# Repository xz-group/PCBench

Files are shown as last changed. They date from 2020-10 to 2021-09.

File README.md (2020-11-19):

# PCBench

PCBench is a free open-source benckmark for board-level hardware attacks and Trojans.

## What's News

Version 1.0

This is the initial release of the benchmars for board-level hardware security.

## Motivation
Most modern electronic systems are hosted by printed circuit boards(PCBs), making them a ubiquitous system component that can take many different shapes and forms. In order to achieve a high level of economy of scale, the global supply chain of electronic systems has evolved into disparate segments for the design, fabrication, assembly, and testing of PCB boards and their various associated components. <br />
As a consequence, the modern PCB supply chain exposes many vulnerabilities along its different stages, allowing adversaries to introduce malicious alterations to facilitate board-level attacks. As an emerging hardware threat, the attack and defense techniques at the board level have not yet been systemically explored and thus require a thorough and comprehensive investigation. <br />
In the absence of a standard board-level attack benchmark, current re-search on perspective countermeasures is likely to be evaluated on proprietary variants of ad-hoc attacks, preventing credible and verifiable comparison among different techniques. Upon this request, we have created the PCBench, which is a set of board-level attack benchmarks for open-source release.

## Benchmarking Methodology

We generated the benchmarks based on the methodology proposed in our **ASP-DAC 2021 paper: *[PCBench: Benchmarking of Board-Level Hardware Attacks and Trojans](http://jin.ece.ufl.edu/papers/ASPDAC2021_PCB.PDF)***.
In this paper, we systematically defined and categorized a broad range of board-level attacks. 
For the first time, the attack vectors and construction rules for board-level attacks were developed.
A practical and reliable board-level attack benchmark generation scheme was also developed, which can be used to produce references for evaluating countermeasures.

## Released Benchmarks
To facilitate the development of board-level attack benchmarks, representative circuit boards are chosen as the victim designs. 
Open-source hardware projects are mainly selected due to their modern design styles, the availability of PCB designs as well as detailed documents, firmware, and/or application software. 
As a result, researchers can easily reconstruct the board-level security evaluation benchmarks. 

**The following table lists the released benchmarks:**

 Design Name | Description | Dimension (mm^2) | No. of Components | No. of Layers
 ----------- | ----------- | :---------: | :-----------------: | :-------------:
 [arduino-due](arduino-due) | Microcontroller devlopment board based on ATsam3x8e with ARM Cortex-M3 core | 102x53 | 141 | 2
 [a13-olinuxino](a13-olinuxino-g2) | Single-board Linux computer based on Allwinner-A13 with Cortex-A8 core | 120x120|370|4

*This is not the full list of benchmarks as we continue developing the new benchmarks.* 

The fabricated Arduino-due board with and without Trojans are shown below.

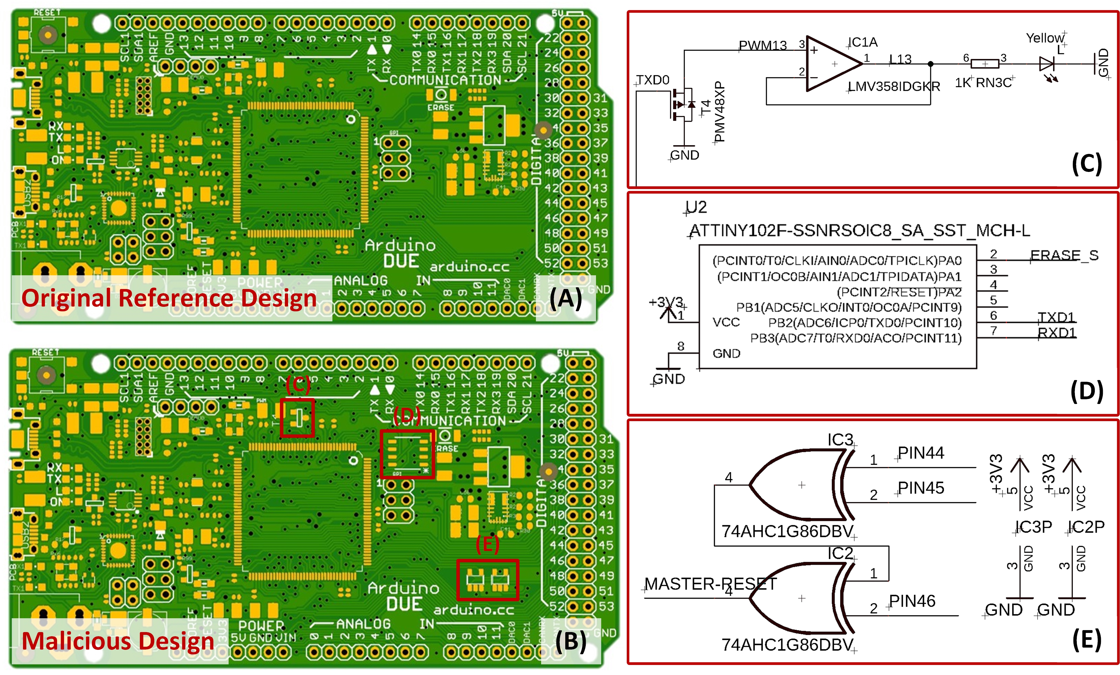
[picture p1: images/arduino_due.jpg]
Arduino Due Board


## Contributiors
The PCBench is mainly developed by *Huifeng Zhu* and *[Dr.Silvia Zhang](https://xzgroup.wustl.edu/people/xuan-silvia-zhang/)* from *Washington University in St.Louis*; *[Dr.Yier Jin](http://jin.ece.ufl.edu/)* from the *University of Florida*; and *[Dr.Xiaolong Guo](https://www.ece.k-state.edu/people/faculty/guo/)* from *Kansas State University*.

We also appreciate the efforts of below contributors: 

## How to Refer to PCBench?
If you are using the benchmarks provided in PCBench to develop either threat mitigation methods or new threat exploitations, please cite our official paper of PCBench. 
You can find the paper in the website of IEEE: [link]() or at [link](http://jin.ece.ufl.edu/papers/ASPDAC2021_PCB.PDF).

A typical BibTeX citation would be, for example:
```
@software{PCBench,
  author = {Huifeng Zhu and Xiaolong Guo and Yier Jin and Xuan Zhang}, % actual author and maintainer
  title = {PCBench: Benchmarking of Board-Level Hardware Attacks and Trojans},
  booktitle = {26th Asia and South Pacific Design Automation Conference (ASP-DAC)},
  year = {2021},
  url = {https://github.com/xz-group/PCBench},
  version = {1.0},
  date = {2020-10-15}, % set to the release date
}
```
## Get Feedback
Feel free to contact us if you have questions about PCBench: **Huifeng Zhu (zhuhuifeng@wustl.edu)**.

## License

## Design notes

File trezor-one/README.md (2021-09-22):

# Trezor One Benchmark



https://trezor.io/

## High-level Description of Hardware Attack
The goal of the Trezor One Benchmark is to siphon the recovery seed from a Trezor One device. This information could then be used to retrieve the original cryptocurrency passwords stored by the user. The recovery process is used in the event that the user forgets their PIN number or enters too many incorrect attempts. The user manual outlines this [recovery process](https://wiki.trezor.io/User_manual:Recovery).

During the initial startup sequence of the Trezor One, the user is instructed to write down a unique, device-generated sequence of 24 english words. Each word is displayed one at a time on the Trezor's built-in monochrome display.

This attack describes the necessary steps for capturing packets of display data and decoding them to reveal the full recovery seed.

## Data Capture
The Trezor One Victim board is equipped with a malicious ATtiny microcontroller that is attached, in a slave configuration, to the Trezor's STM32 microcontroller SPI lines. These SPI lines are also connected the the Trezor's display and are used to send bitmap image data. This configuration allows the malicious ATtiny to go undetected while still having access to all data being sent from the Trezor's microcontroller to its display.

Due to how the display operates, the Trezor's microcontroller sends a complete bitmap image to the display each time it needs to be altered, regardless of how many pixels need to change. This is beneficial because it makes it easy to decode recorded SPI packets and rebuild them into complete images. These decoded images represent exactly, pixel for pixel, what was displayed on the Trezor device at the time of packet transmission.

## Implementing the Attack

### Technical Details

#### Display Connecter Pins Table:

| PIN | <------------> | NET |
| --- | --- | --- |
| 12 | <------------> | GND |
| 13 | <------------> | SPI ENABLE |
| 15 | <------------> | DISPLAY DATA/COMMAND |
| 18 | <------------> | SPI CLOCK |
| 19 | <------------> | SPI DATA |

#### Trezor SSD1306 Operation
The display used is a 128x64 OLED SPI display. Internally, the display contains a single-chip driver called the SSD1306 which is widely utilized and documented. The full details of the [SSD1306 documentation](https://cdn-shop.adafruit.com/datasheets/SSD1306.pdf) are crucial to gaining a low-level understanding of this attack. 

A full screen's worth of data is sent to the display each time it is updated. At a simple level, there are 8,192 total pixels and each pixel is driven by a 1 for ON or 0 for OFF. This series of 1024 1's and 0's are sent one byte at a time via SPI to the display. However, they are not ordered left to right and top to bottom as one might expect. The full details of the pixel mapping algorithm is outlined on page 25 of the [SSD1306 documentation](https://cdn-shop.adafruit.com/datasheets/SSD1306.pdf) with regards to the display's GDDRAM. This process needs to be reversed for decoding and is exactly what is embedded in the [src/image_builder.py](image_builder.py) script.

Along with the 8,192 data bits that are sent to the display, there are also command sequences that are sent at the beginning of each transmission that do not represent pixel values. Outlined below is information representing the series of bits sent via SPI to the display by the Trezor. If necessary, specific command bytes can be tracked down in the [Trezor Firmware](https://github.com/trezor/trezor-mcu).

* **Setup Command Bytes (25 total)**
    * Description: The setup command bytes are sent directly after the RESET line of the display is triggered on startup. They aid in resetting the display, setting the contrast, setting the page addressing mode, etc. The exact bytes and corresponding meaning can be found in the [oled.c](https://github.com/trezor/trezor-mcu/blob/8af1f3643651e1cbee6b6196401f9c63e7cfc0f9/oled.c) file in the [Trezor Firmware](https://github.com/trezor/trezor-mcu).
    * Data: {0xAE, 0xD5, 0x80, 0xA8, 0x3F, 0xD3, 0x00, 0x40, 0x8D, 0x14, 0x20, 0x00, 0xA1, 0xC8, 0xDA, 0x12, 0x81, 0xCF, 0xD9, 0xF1, 0xDB, 0x40, 0xA4, 0xA6, 0xAF}
* **Prepended Command Bytes (3 total)**
    * Description: The prepended command bytes are sent directly before new image data is sent. For the Trezor, these bytes are always the same and can be helpful as a delimiter for debugging purposes.
    * Data: {0x00, 0x10, 0x40}
* **Pixel Value Bytes (1024 total)**
* Description: The pixel value bytes represent 1's and 0's for each of the 8,192 pixels. This means that there are 1024 SPI byte packets sent for this part of the transmission. This is the most important part of the transmission for the attack and is the only piece that needs to be recorded to EEPROM since the other pieces are constant and predictable.
* Data: {0x__, 0x__, 0x__, .......}

It is important to note that there is a signal connected to the display (DISPLAY DATA/COMMAND or D/C) that tells the display whether the incoming data is a series of command bytes or data bytes. For the Setup and Prepended Command Bytes, the D/C pin is pulled low so that the data is transferred to the SSD1306 command register. For the Pixel Value Bytes, the D/C is pulled high to be treated as data.

The order in which these command bytes and data bytes are sent is consistent:
1. The Setup Command Bytes are sent only once when the device is powered on.
1. The Preprended Command Bytes are sent before the initial screen data is sent.
1. The Pixel Value Bytes are sent as 0's (1024 bytes of 0x00) to clear the GDDRAM of the SSD1306.
1. The Preprended Command Bytes are sent before the startup screen data is sent.
1. The Pixel Value Bytes are sent to display the startup screen.
1. The previous two steps are repeated for every subsequent image displayed. This means that subsequent transmissions are a total of 1027 bytes (3 Prepend Command Bytes + 1024 Pixel Value Bytes)

Manual tests with an Arduino board and an external 128x64 OLED SPI display can be used to test what unique outputs may look like. Modify [SPI_Manual_Test.ino](/src/SPI_Manual_Test/SPI_Manual_Test.ino) for testing.

### Ideal Attack Sequence
1. Program the malicious ATtiny chip with firmware that enables it to record and store SPI packets to EEPROM.
1. After Trezor device is setup and functional, the malicious ATtiny chip will contain the SPI packets relating to the recovery seed image data. This means that the ATtiny device can now be connected to in some fashion that allows for its EEPROM to be extracted.
1. Enter the extracted EEPROM bytes into a .csv file.
1. Run the image builder Python script that converts the data in the .csv file to a .png image.
1. Repeat the previous step until all images representing each word in the recovery seed are created.
1. Use the recovery seed to gain access to the information on the Trezor device by following the [recovery process](https://wiki.trezor.io/User_manual:Recovery).

### Proof of Concept Attack Sequence
To prove that this ideal attack sequence is possible, various methods and tools were used to extract test data from a from both a real Trezor One and a Trezor victim board.

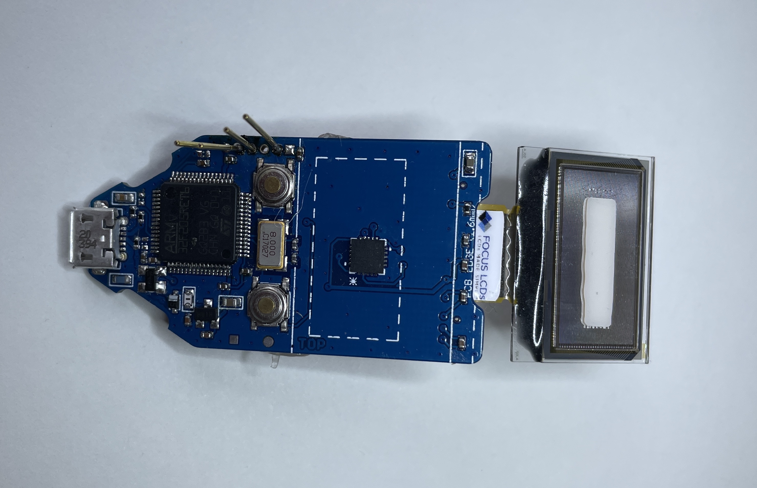
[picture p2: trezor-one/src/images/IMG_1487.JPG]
Trezor victim board


First, a Trezor victim board was populated. Firmware was built and uploaded by following the [Trezor One Dev Kit](https://mcudev.github.io/trezor-dev-kit/) documentation. Once the device is set up, you must navigate to trezor.io/start and follow the instructions. Unfortunately, this process involves updating the firmware which seems to halt any progress past this point. After the forced update, the Trezor displays an "Unknown bootloader detected" warning and does not work. However, for the purposes of the proof of concept, this limitation was ignored because the SPI data packets used to display the startup screen and "Unknown bootloader detected" warning are of the same format as the packets used to display all content (including the recovery seed words).

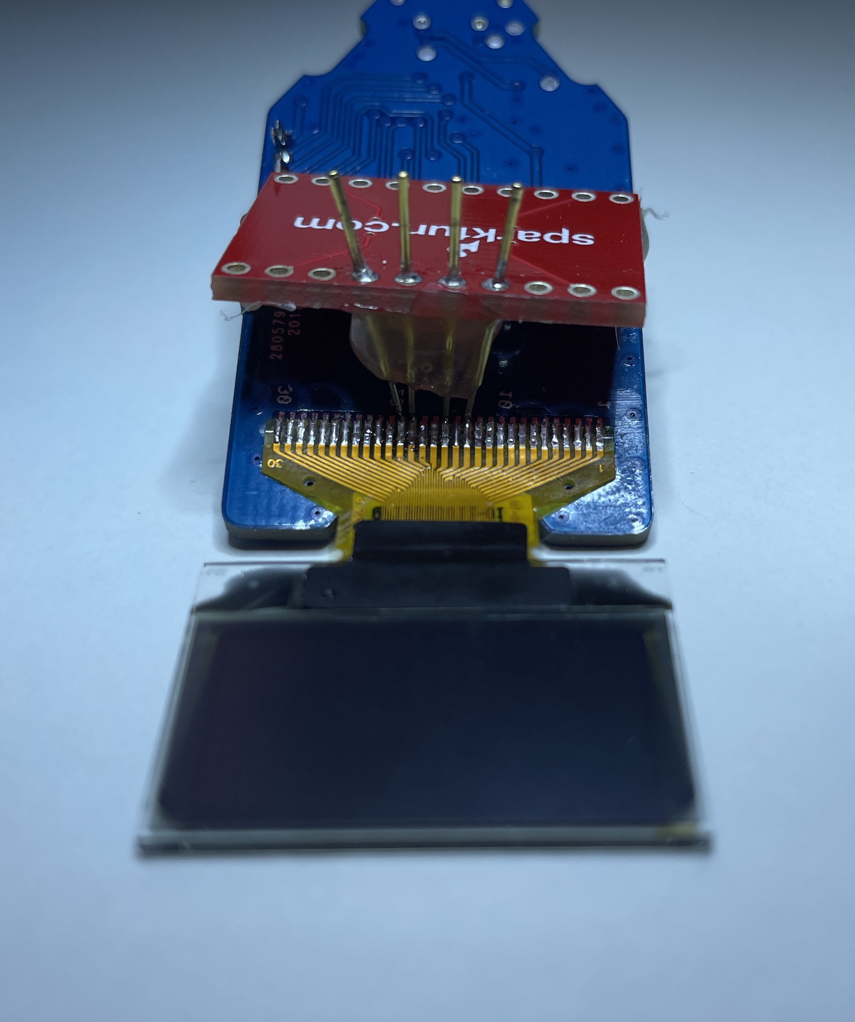
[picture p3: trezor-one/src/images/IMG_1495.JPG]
Improvised connector


Next, a logic analyzer was connected to the necessary pins on the display connector (see Technical Details) using an improvised connector. The HEX values sent over the SPI data line were then exported to the [startup_spi_data.csv](src/startup_spi_data.csv) file. The beginning and ending of the 1024 bytes representing each displayed image were then set manually in the [image_builder.py](src/image_builder.py) file. At this point in testing, the Trezor victim board displayed two images on startup. The first was a lock icon and the second was the "Unknown bootloader detected" warning. Setting and running the python script for both sets of 1024 bytes in the .csv file resulted in the [Lock Screen Image](src/lock_screen.png) and [Info Screen Image](src/info_screen.png) being generated.

To prove that these results were relevant to a real Trezor, the improvised connector was placed on a geniune Trezor One. Using a logic analyzer in the same fashion resulted in the [real_trezor_startup.csv](src/real_trezor_startup.csv) file. After setting the start and end rows of the SPI data relating to the startup screen, the python script produced the [real_trezor_startup.png](src/real_trezor_startup.png) image.

### Further Implementation

Currently, there is one gap between the proof of concept and the ideal attack sequence. In the proof of concept, the SPI data was captured with a logic analyzer and then exported to .csv file. In the ideal attack sequence, the ATtiny captures the data and the user then connects to the ATtiny to extract the recorded data from EEPROM.

Firmware for the ATtiny needs to be written that implements it as an SPI slave. Since the general purpose SPI library does not support the ATtiny85 being used, a more primitive script must be used. Refer to this [stackexchange post](https://electronics.stackexchange.com/questions/60114/spi-h-for-attiny) for ideas.

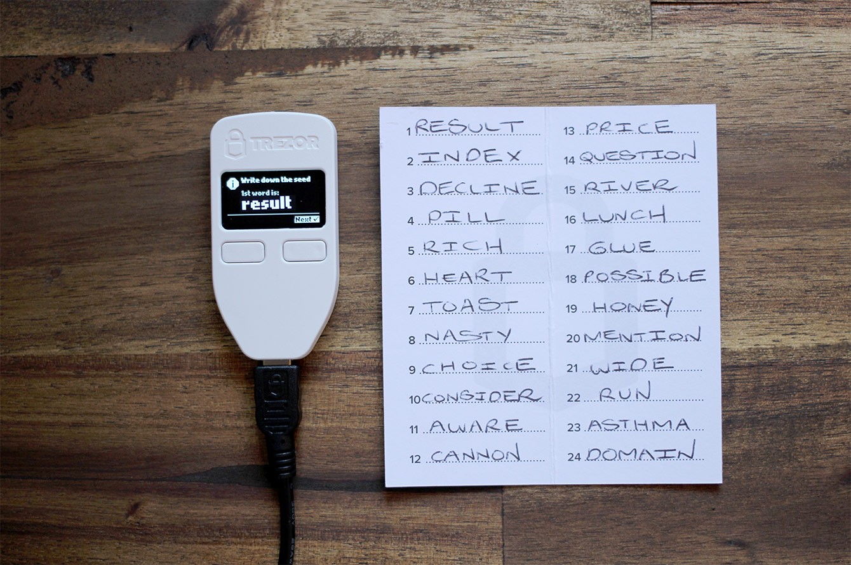
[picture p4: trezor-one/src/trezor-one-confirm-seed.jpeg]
Trezor One Recovery Seed


Once this is implemented, the next immediate problem is EEPROM space. It must be noted that the data has to be held in EEPROM because it needs to be stored in non-volatile memory. The Trezor will be powered off before the data extraction from the ATtiny occurs. It seems that the ATtiny85 has 512 bytes of EEPROM. Unfortunately, this is nowhere near sufficient for this application. Ideally, 24,576 bytes (24 recovery screens * 1024 bytes per display image) would be available to record the SPI data to. This also assumes that the ATtiny is equipped with code that knows exactly which SPI packets will represent the 24 recovery screens that need to be recorded. On the surface, this may seem simple to account for. In the startup sequence, the recovery screens should always be the Nth screen to be displayed. The ATtiny would then be able to count packets until it gets to the Nth screen. However, this may not work because of variants such as the unnecessary button presses from the user that result in extra screens being displayed. Therefore, a better method will probably have to be utilized. One method would be to figure out if the recovery screens have a special, unique design. For example, as shown in this [photo](trezor-one-confirm-seed.jpeg), the ATtiny could be programmed with a bitmap that has the correct bytes representing "Write down the seed" and "Nth word is:." These could then be compared with the most recently recorded packet to decide whether or not the packet represent a recovery screen. Furthermore, this method can also help reduce necessary EEPROM space. It can be noted than in the [photo](trezor-one-confirm-seed.jpeg), takes up at most 1/3 of the vertical space and slightly more than 1/2 of the horizontal space. While this can't solve the 512 byte limitation, it can greatly reduce the EEPROM size needed to well under 24,576 bytes. Since the final EEPROM size needed will be greater than the currently available 512 bytes in the ATtiny85, there are two options. The first is to choose another microcontroller with a larger EEPROM. The second option would be to add an external EEPROM chip which is cheap and offers a tremendous amount of storage. However, one caveat of the latter method is that the external EEPROM would need to be connected over SPI. This may potentially pose a problem because the microcontroller would have to act as both and SPI slave for the STM32 and a master for the external EEPROM.

### ATtiny85-20M1 Breakout Board

In order to upload code to this ATtiny85 package for testing, a custom breakout board is needed. This is because the footprint is unique and compatible breakout boards are difficult to find online. This breakout board was designed in KiCad and an image of the board along with the pinout information is listed below. All design files can be found [here](attiny85_breakout_board).

| Header Pin | ATtiny85 Pin | Connection |
| --- | --- | --- |
| 1 | 1 | RESET/PB5 |
| 2 | 2 | XTAL1/PB3 |
| 5 | 5 | XTAL2/PB4 |
| 8 | 8 | GND |
| 11 | 11 | AREF/PB0 |
| 12 | 12 | PB1 |
| 14 | 14 | PB2 |
| 15 | 15 | VCC |

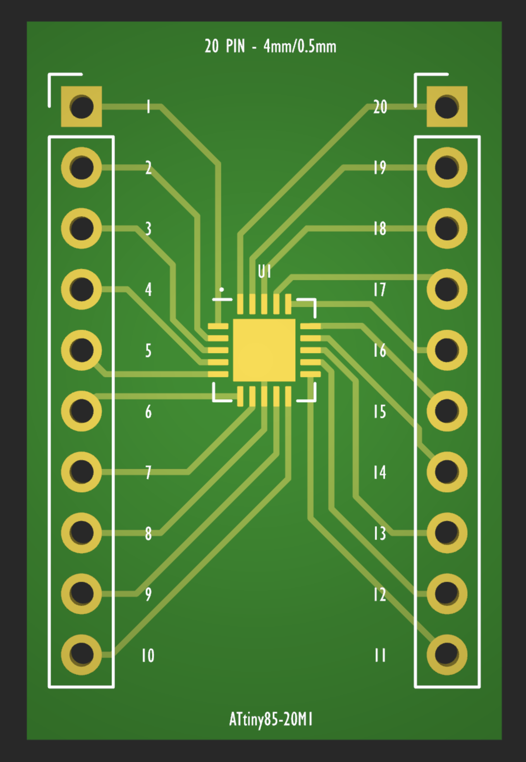
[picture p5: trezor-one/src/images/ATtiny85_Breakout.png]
ATtiny85 Breakout Board


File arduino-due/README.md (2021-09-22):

# Getting Started with the Arduino-Due Benchmark

## Introduction
This tutorial includes step-by-step information about how to get started with the `arduino-due` benchmark, including both setting up the boards and demonstrating the attacks.

For this benchmark, there are two versions of boards (as shown below): the  `malicious` version and the `reference` version. The `reference` version uses the exact same schematic design of the original [Arduino Due board](https://store.arduino.cc/usa/due). 
Note that we slightly modify the layout of the original design to ease inserting the Trojans and implementing the attacks. The `malicious` version is the same as the `reference` version (both schematic and layout) except the inserted malicious circuit, which means once the malicious circuits and related routings are removed, the `malicious` version board will be completely the same as the `reference` version board.

In this benchmark we implement three malicious attacks (as shown above):
1. A malicious MOSFET is connected to the UART transmitter to leak information through LED (subfigure c);
2. The maliciously programmed ATtiny microcontroller monitors the UART and generates Flash erase signal when triggered (subfigure d); 
3. Two XOR logic chips output a signal to reset the board once triggered (subfigure e).

## Initialize the boards
### Install the firmware of the Arduino Due programming port
#### Use the Atmel programmer to install the firmware:
1. Follow the instruction of https://www.arduino.cc/en/Hacking/DFUProgramming8U2

2. For the firmware files, the `hex` files can be found in
https://github.com/arduino/ArduinoCore-sam/tree/master/firmwares/atmega16u2

3. After programming the flash, you will see the programming port of the Arduino Due board in your Device manager.


### Test the functionality of the boards
1. Install the Arduino SAM Boards (32-bits ARM Cortex M3) from the tools->board->boards manager.
#### Program through the Programming Port
1. Connect the Programming Port.
2. Upload and Run the `Blink` example.

#### Program through the Native USB Port

1. Connect the native USB port.
2. Program directly using the native USB port, upload and Run the `Blink` example.

## Demonstrate the attacks
### 1. Malicious MOSFET
**Goal:**<br> A malicious MOSFET is connected to the UART transmit pin to leak information through LED.

**Configuration:**<br> In this demonstration, the datapath is as follows:
User input into the reference board's Serial Monitor is sent directly to the Serial1 port on the victim board. This Serial1 port (on the victim board) is directly connected to the LED that is used to leak the data. Once the victim board receives data from the reference board, it mirrors the characters back over the same Serial1 port to be leaked through the LED. The data is also mirrored to the SerialUSB port which will display on the victim board's Serial Monitor if connected.

**Demonstration:**<br>

1. Connect Pins

| Reference Board | <------------> | Victim Board |
| --- | --- | --- |
| Serial1 TX (18) | <------------> | Serial1 RX (19) |
| Serial1 RX (19) | <------------> | Serial1 TX (18) |
| GND | <------------> | GND |

2. Upload Source Code

* Attach the victim board via USB and upload the following [source code](attacks/malicious_MOSFET/victim_board_src/victim_board_src.ino)
* Attach the reference board via USB and upload the following [source code](attacks/malicious_MOSFET/reference_board_src/reference_board_src.ino)

3. Testing

* Connect the reference board via USB
* Open the Serial Monitor (this is accessed by clicking the plus button in the top right corner on the Arduino IDE)
* Click the hardware reset button (located next to the USB port) on the reference board
* Wait 5 seconds for the board to initialize until you see an information printout
* Try entering various characters into the Serial Monitor
* Take note of the LED blinking on the victim board whenever characters are sent via the reference board
* To confirm that characters are being sent, connect the reference board via USB and open another Serial Monitor to track the mirrored characters being sent from the reference board

**Vulnerability:**<br> The flashing of the LED corresponds to the 1's and 0's of the ASCII being transmitted through UART. This data could be sensed and decoded by another system to monitor sensitive UART data packets.

### 2. Malicious ATtiny
**Goal:**<br> A maliciously programmed ATtiny microcontroller monitors the UART and generates a Flash erase signal when triggered.

**Generalized Configuration:**<br> In this demonstration, the datapath is as follows:
User input into the reference board's Serial Monitor is sent directly to the Serial2 port on the victim board. This Serial2 port (on the victim board) is directly monitored by the malicious ATtiny. Once the trigger word is inputted by the user and subsequently read by the ATtiny, the ATtiny triggers a master reset of the victim board's flash memory. Throughout this process, the victim board's LED will continuously blink to show that it is still functional and has not yet been attacked. Once it is attacked, the LED will stop blinking and the board will have to be re-flashed before it can perform another test.

**Technical Configuration:**<br>
* The ATtiny102 constantly monitors the victim board's UART RX pin at 4800 baud
    * This connection configuration is undetectable by the victim board itself or any reference boards
* A reference board is used to connect to the Serial 2 UART Port of the victim board (TX-16 RX-17)
    * The reference board can trigger the ATtiny102 to erase the flash of the victim board by sending the command "ATTACK"
* A 6-character buffer array is maintined on the ATtiny102 to keep track of incoming UART characters
    * Each time a new character is read, it is placed at the end of the array
    * Subsequently, all remaining characters are shifted one index to the left in the array
    * This process discards the oldest (leftmost) character
* Once the buffer array contains the string "ATTACK" the ERASE sequence is triggered:
    * The ATtiny102 pulls the ERASE pin of the victim board LOW for 2 seconds to erase the FLASH
    * At this point, the victim board is in a paralyzed state and the ATtiny102 resumes normal listening operation

**Demonstration:**
1. Connect Pins

| Reference Board | <------------> | Victim Board |
| --- | --- | --- |
| Serial2 TX (16) | <------------> | Serial1 RX (17) |
| Serial1 RX (17) | <------------> | Serial1 TX (16) |
| GND | <------------> | GND |

2. Upload Source Code

* Attach the victim board via USB and upload the following [source code](attacks/malicious_ATtiny/victim_board_src/victim_board_src.ino)
* Attach the reference board via USB and upload the following [source code](attacks/malicious_ATtiny/reference_board_src/reference_board_src.ino)
* If the ATtiny needs to be flashed, use Atmel/Microchip Studio to upload the following [source code](attacks/malicious_ATtiny/ATtiny_src)

3. Testing

* Connect the reference board via USB
* Open the Serial Monitor (this is accessed by clicking the plus button in the top right corner on the Arduino IDE)
* Click the hardware reset button (located next to the USB port) on the reference board
* Wait 5 seconds for the board to initialize until you see an information printout
* Try entering various characters (not the trigger word) into the Serial Monitor
* Take note of the LED blinking on the victim board which signifies that it has not yet been attacked
* Enter the trigger word into the Serial Monitor
* Confirm that the attack was successful be ensuring that the victim board's LED stopped blinking

**Vulnerability:**<br> The ATtiny can erase the Flash of the victim board, rendering it useless, if the trigger command is sent to the victim board over UART.

### 3. Malicious XORs
**Goal:**<br> Two XOR logic chips output a signal to reset the victim board's Flash once triggered.

**Generalized Configuration:**<br> In this demonstration, the datapath is as follows:
User input into the reference board's Serial Monitor is monitored internally by the reference board. Once the trigger word is inputted by the user, a sequence of code executes that triggers a flash reset on the victim board. This is accomplished by setting pins 44, 45, and 46 on the victim board to a specific sequence of logic levels that trigger the flash reset. Throughout this process, the victim board's LED will continuously blink to show that it is still functional and has not yet been attacked. Once it is attacked, the LED will stop blinking and the board will have to be re-flashed before it can perform another test.

**Technical Configuration:**<br>
* The XOR chips have pins 44, 45, 46 from the victim board as inputs. In the default state, these pins are logical level HIGH so as to not trigger the Flash reset.
* The following truth table represents the various logic level inputs to the victim board and what output they trigger

| Pin 44 | Pin 45 | Pin 46 | Flash Reset |
| --- | --- | --- | ---  |
|0|0|0|NO|
|0|0|1|<mark>YES<mark>|
|0|1|0|<mark>YES<mark>|
|0|1|1|NO|
|1|0|0|<mark>YES<mark>|
|1|0|1|NO|
|1|1|0|NO|
|1|1|1|<mark>YES<mark>|

**Demonstration:**
1. Connect Pins

| Reference Board | <------------> | Victim Board |
| --- | --- | --- |
| D10 | <------------> | D44 |
| D11 | <------------> | D45 |
| D12 | <------------> | D46 |
| GND | <------------> | GND |

2. Upload Source Code

* Attach the victim board via USB and upload the following [source code](attacks/malicious_ATtiny/victim_board_src/victim_board_src.ino)
* Attach the reference board via USB and upload the following [source code](attacks/malicious_ATtiny/reference_board_src/reference_board_src.ino)

3. Testing

* Connect the reference board via USB
* Open the Serial Monitor (this is accessed by clicking the plus button in the top right corner on the Arduino IDE)
* Click the hardware reset button (located next to the USB port) on the reference board
* Wait 5 seconds for the board to initialize until you see an information printout
* Try entering various characters (not the trigger word) into the Serial Monitor
* Take note of the LED blinking on the victim board which signifies that it has not yet been attacked
* Enter the trigger word into the Serial Monitor
* Confirm that the attack was successful be ensuring that the victim board's LED stopped blinking

**Vulnerability:**<br> An external board can change the state of these input pins which would trigger a Flash reset of the victim board, rendering is useless.

## Developer Notes
* For an 8MHz internal clock on the ATtiny102, the prescaler sets the clock in the code to 1MHz
    * 1 MHz is not considered fast enough to communicated over UART at 9600 baud becuase data becomes corrupted
    * 4800 is the maximum clean baud rate for this internal clock
* ATtiny102 TX trace should be removed in final design
* Use other, non-programming pin, for the resetting functionality on the ATtiny102 (recommend PB1/Pin 5)
* The programming port on the test boards does not work due to a an error in the original Arduino Due design documentation

## References
1. Pinout of the Arduino Due Board: https://content.arduino.cc/assets/Pinout-Due_latest.pdf

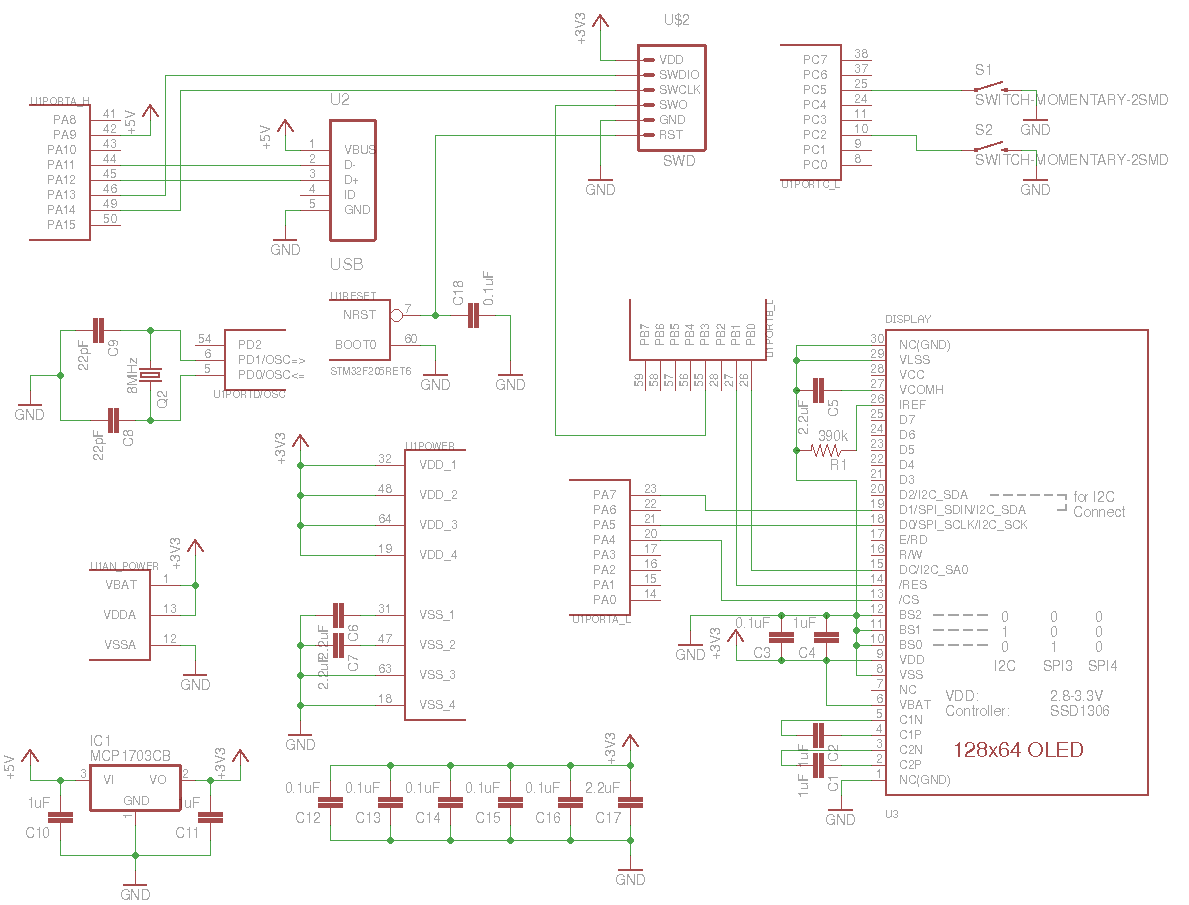
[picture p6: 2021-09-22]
trezor-one/src/electronics/trezor_one/trezor_v1.0.sch.png

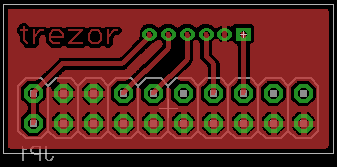
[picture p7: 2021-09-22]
trezor-one/src/electronics/trezor_one/programmer.brd.png

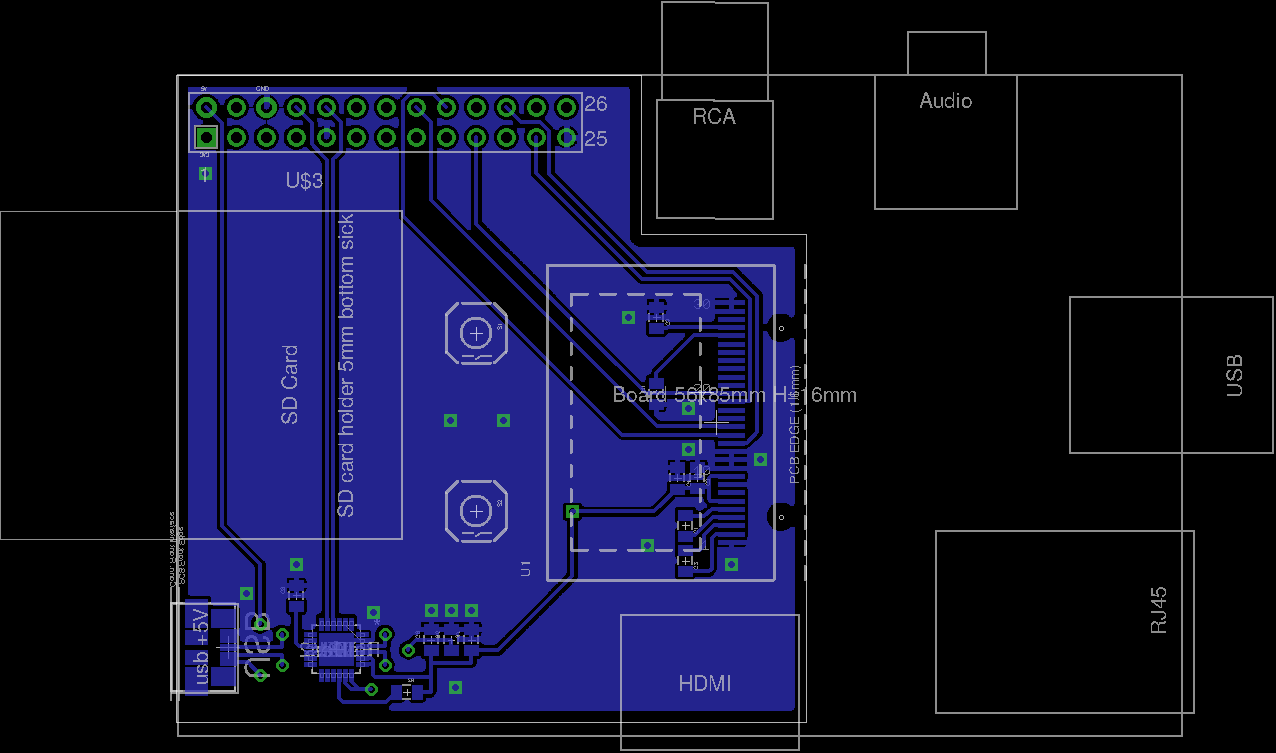
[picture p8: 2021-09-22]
trezor-one/src/electronics/trezor_one/raspi.brd.png

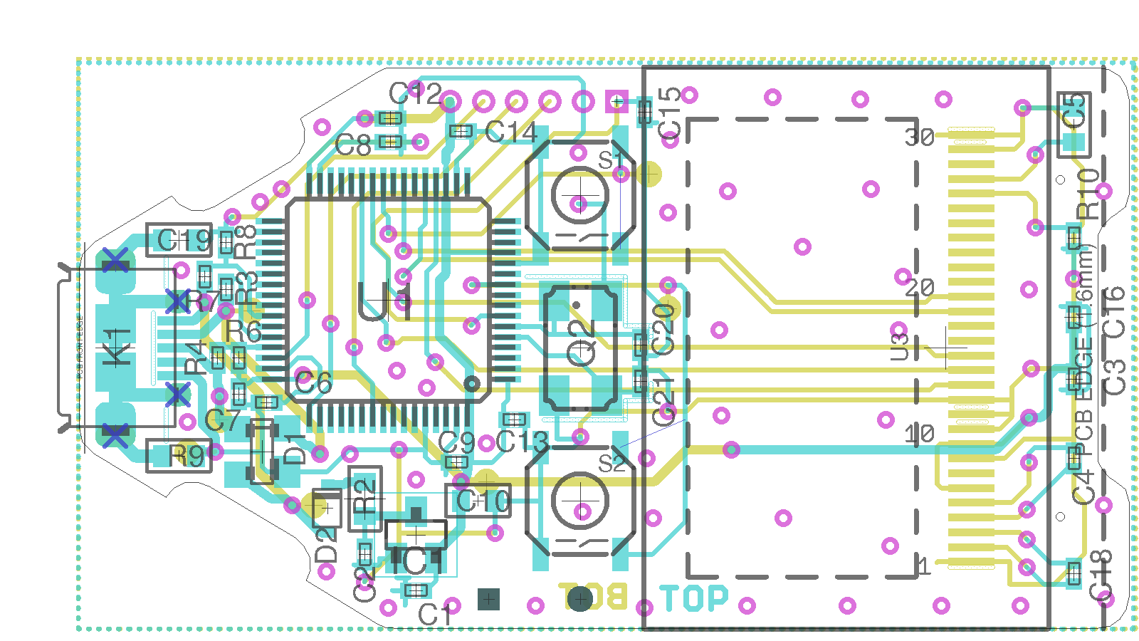
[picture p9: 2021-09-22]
trezor-one/src/electronics/trezor_one/trezor_v1.1.brd.png

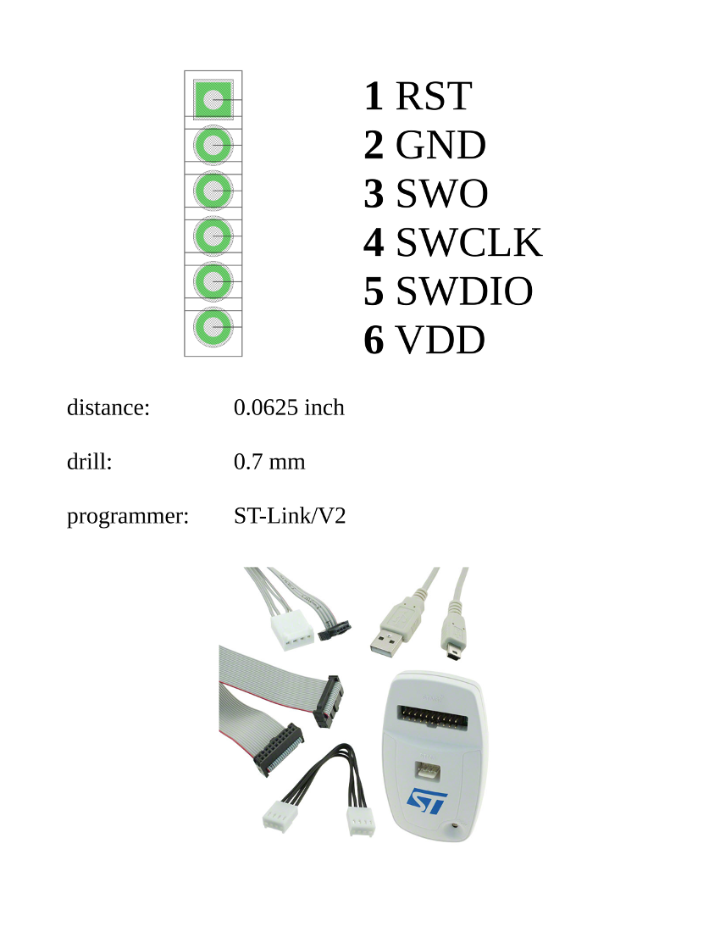
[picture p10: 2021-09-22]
trezor-one/src/electronics/trezor_one/programmer.png

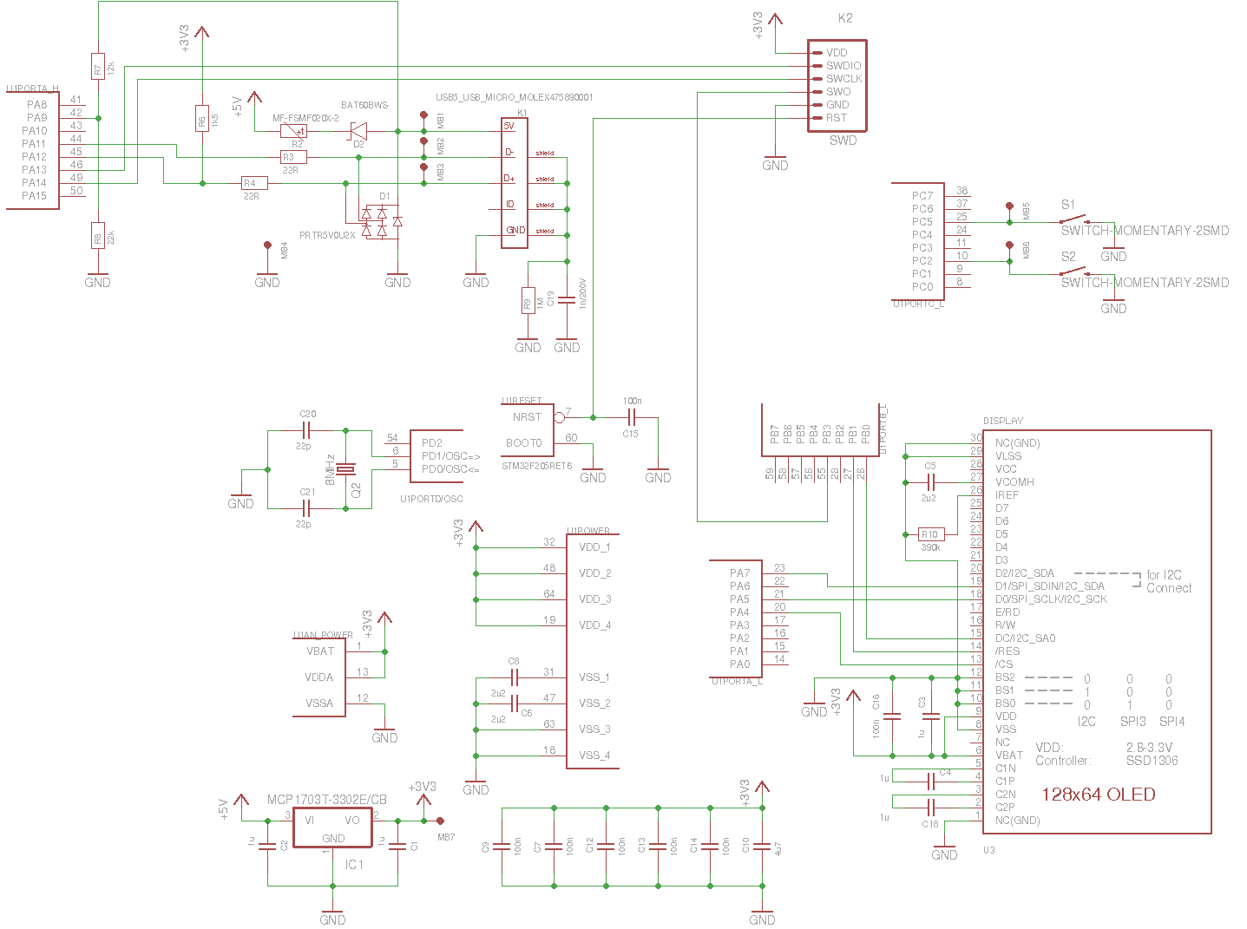
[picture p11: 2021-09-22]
trezor-one/src/electronics/trezor_one/trezor_v1.1.sch.png

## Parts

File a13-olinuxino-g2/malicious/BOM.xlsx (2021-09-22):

Qty | Value | Device | Package | Parts | Description
1 | 0.03R/1% | R-EU_R1206_5MIL_WS | R1206_5MIL_WS | R27 | RESISTOR, European symbol
4 | 1.05k/1% | R-EU_R0603_5MIL_DWS | R0603_5MIL_DWS | R35, R36, R37, R74 | RESISTOR, European symbol
4 | 1.1k/1% | R-EU_R0603_5MIL_DWS | R0603_5MIL_DWS | R19, R85, R100, R101 | RESISTOR, European symbol
3 | 100k/1% | R-EU_R0603_5MIL_DWS | R0603_5MIL_DWS | R69, R76, R84 | RESISTOR, European symbol
57 | 100nF | C-EUC0603_DWS | C0603_DWS | C1, C2, C3, C4, C13, C15, C17, C19, C20, C21, C22, C23, C24, C29, C30, C32, C34, C36, C37, C38, C39, C40, C41, C43, C44, C45, C46, C47, C48, C49, C50, C51, C56, C57, C59, C62, C63, C64, C70, C72, C80, C81, C82, C90, C97, C101, C105, C108, C110, C111, C112, C118, C119, C122, C127, C131, C141 | CAPACITOR, European symbol
1 | 100pF | C-EUC0603_DWS | C0603_DWS | C144 | CAPACITOR, European symbol
4 | 100uF/16V/LOWESR/105C/6.3x11mm_RM2.5 | CPOL-EUE2.5-6.3 | E2,5-6,3 | C91, C99, C107, C117 | POLARIZED CAPACITOR, European symbol
10 | 10k | R-EU_R0603_5MIL_DWS | R0603_5MIL_DWS | R14, R16, R18, R47, R55, R56, R96, R97, R103, R104 | RESISTOR, European symbol
1 | 10k/1% | R-EU_R0603_5MIL_DWS | R0603_5MIL_DWS | R81 | RESISTOR, European symbol
1 | 10nF | C-EUC0603_DWS | C0603_DWS | C123 | CAPACITOR, European symbol
1 | 10pF | C-EUC0603_DWS | C0603_DWS | C130 | CAPACITOR, European symbol
31 | 10uF/6.3V | C-EUC0603_DWS | C0603_DWS | C6, C7, C8, C10, C11, C14, C16, C31, C35, C54, C55, C58, C73, C74, C76, C77, C78, C79, C83, C85, C86, C88, C92, C93, C95, C96, C98, C100, C102, C109, C121 | CAPACITOR, European symbol
1 | 10uH/3.15A/20% | LLQH88PN100M38 | 8X8MM_3131 | L13
1 | 11k/1% | R-EU_R0603_5MIL_DWS | R0603_5MIL_DWS | R82 | RESISTOR, European symbol
2 | 13k/1% | R-EU_R0603_5MIL_DWS | R0603_5MIL_DWS | R68, R83 | RESISTOR, European symbol
3 | 17.8k/1% | R-EU_R0603_5MIL_DWS | R0603_5MIL_DWS | R20, R21, R22 | RESISTOR, European symbol
1 | 1N5819(S4SOD-123) | SCHOTKKY7.62SS-1N5819(S4SOD-123) | SOD-123 | D1
1 | 1N5822/SS34/SMA | D-MLL-41 | MELF-MLL41 | D9 | DIODE
1 | 1N5822/SS34/SMA | SCHOTKKY7.62SS2 | MLL-41 | D7
2 | 1R | R-EU_R0603_5MIL_DWS | R0603_5MIL_DWS | R34, R41 | RESISTOR, European symbol
9 | 1nF | C-EUC0603_DWS | C0603_DWS | C60, C61, C65, C66, C67, C84, C87, C103, C139 | CAPACITOR, European symbol
6 | 1uF | C-EUC0603_DWS | C0603_DWS | C28, C33, C75, C89, C94, C104 | CAPACITOR, European symbol
14 | 2.2k | R-EU_R0603_5MIL_DWS | R0603_5MIL_DWS | R8, R9, R45, R49, R50, R52, R53, R59, R60, R61, R72, R73, R75, R77 | RESISTOR, European symbol
3 | 2.2k/1% | R-EU_R0603_5MIL_DWS | R0603_5MIL_DWS | R31, R32, R33 | RESISTOR, European symbol
6 | 2.2uH/1.5A/DCR<0.1R/CD32 | L-CD32 | CD32 | L2, L3, L4, L10, L14, L15
3 | 200k/1% | R-EU_R0603_5MIL_DWS | R0603_5MIL_DWS | R7, R46, R67 | RESISTOR, European symbol
8 | 22R | R-EU_R0603_5MIL_DWS | R0603_5MIL_DWS | R87, R88, R89, R90, R91, R92, R93, R94 | RESISTOR, European symbol
1 | 22k/1% | R-EU_R0603_5MIL_DWS | R0603_5MIL_DWS | R86 | RESISTOR, European symbol
1 | 22pF | C-EUC0603_DWS | C0603_DWS | C114 | CAPACITOR, European symbol
1 | 22uF | C-EUC0603_DWS | C0603_DWS | C140 | CAPACITOR, European symbol
21 | 22uF/6.3V | C-EUC0603_DWS | C0603_DWS | C5, C9, C12, C18, C25, C42, C52, C68, C69, C71, C113, C115, C116, C128, C129, C132, C133, C135, C136, C137, C138 | CAPACITOR, European symbol
4 | 240R/1% | R-EU_R0603_5MIL_DWS | R0603_5MIL_DWS | R10, R12, R13, R23 | RESISTOR, European symbol
4 | 2k/1% | R-EU_R0603_5MIL_DWS | R0603_5MIL_DWS | R1, R2, R6, R11 | RESISTOR, European symbol
1 | 3.3k/1% | R-EU_R0603_5MIL_DWS | R0603_5MIL_DWS | R65 | RESISTOR, European symbol
2 | 3.3nF | C-EUC0603_DWS | C0603_DWS | C53, C124 | CAPACITOR, European symbol
1 | 32768Hz/6pF | MC-306_32.768KHZ/SMD_8038 | MC-306 | Q3
4 | 33pF | C-EUC0603_DWS | C0603_DWS | C26, C27, C120, C125 | CAPACITOR, European symbol
4 | 4.32k/1% | R-EU_R0603_5MIL_DWS | R0603_5MIL_DWS | R28, R29, R30, R102 | RESISTOR, European symbol
2 | 4.99k/1% | R-EU_R0603_5MIL_DWS | R0603_5MIL_DWS | R62, R71 | RESISTOR, European symbol
1 | 470uF/25V/LOWESR/105C | CPOL-EUE5-10.5 | E5-10,5 | C126 | POLARIZED CAPACITOR, European symbol
7 | 47k | R-EU_R0603_5MIL_DWS | R0603_5MIL_DWS | R4, R5, R17, R51, R54, R64, R70 | RESISTOR, European symbol
1 | 47pF | C-EUC0603_DWS | C0603_DWS | C134 | CAPACITOR, European symbol
3 | 51R | R-EU_R0603_5MIL_DWS | R0603_5MIL_DWS | R43, R98, R99 | RESISTOR, European symbol
3 | 549R/1% | R-EU_R0603_5MIL_DWS | R0603_5MIL_DWS | R38, R39, R40 | RESISTOR, European symbol
2 | 6.8k/1% | R-EU_R0603_5MIL_DWS | R0603_5MIL_DWS | R48, R79 | RESISTOR, European symbol
1 | 680R/1% | R-EU_R0603_5MIL_DWS | R0603_5MIL_DWS | R66 | RESISTOR, European symbol
1 | 74LVC1G06DCK | 74LVC1G06DCK | SC70-5 | IC1 | Single Inverter Buffer/Driver With Open-Drain Output
2 | 8.2k/1% | R-EU_R0603_5MIL_DWS | R0603_5MIL_DWS | R78, R80 | RESISTOR, European symbol
3 | 8.66k/1% | R-EU_R0603_5MIL_DWS | R0603_5MIL_DWS | R24, R25, R26 | RESISTOR, European symbol
1 | A13 | Allwinner A13 | TQFP176 | U3
1 | ATTINY102F-SSNRSOIC8_SA_SST_MCH-L | ATTINY102F-SSNRSOIC8_SA_SST_MCH-L | SOIC8_SA_SST_MCH-L | U17
1 | AXP209(QFN48) | AXP209 | QFN48 | U9
2 | BAT54C | DIODE_AC-CA_ | SOT23C | D10, D11 | DUAL DIODE
5 | BAT54S | DIODE_AC-AC_ | SOT23C(BAT54S) | D2, D3, D4, D5, D6 | DUAL DIODE
2 | BH10S | ML10 | ML10-MALE | GPIO-1, UEXT | HARTING
4 | BSS138 | N-MOS+DIODBSS138(SOT23-3) | SOT23 | FET1, FET2, FET4, FET5
1 | CL470nH/0805/1.76R/250mA | L-USL0805_5MIL_DWS | L0805_5MIL_DWS | L1 | INDUCTOR, American symbol
1 | DW02R | CON2DW02R | DW02R | LIPO_BAT
1 | FB0805/600R/200mA(201209-601) | L-USL0805_5MIL_DWS | L0805_5MIL_DWS | L12 | INDUCTOR, American symbol
6 | FB0805/600R/2A | L-USL0805_5MIL_DWS | L0805_5MIL_DWS | L5, L6, L7, L8, L9, L11 | INDUCTOR, American symbol
1 | GL850G-HHGXX | GL850G | SSOP28 | U11
1 | H27UBG8T2BTR | H27UBG8T2A | TSOP48 | U4
2 | HC49/S1 | HC49/S1 | HC49/SMD2_THIN | Q1, Q2 | CRYSTAL
1 | IRLML6402 | P-MOS+DIODIRLML6402 | SOT23 | FET3
2 | K4B2G0846Q-BCKO | H5TQ2G83CFR-H9C | FBGA78 | U1, U2
1 | LED/GREEN/0603 | LED0603DWS | LED-0603 | LED1
1 | LED/RED/0603 | LED0603DWS | LED-0603 | PWR_LED
1 | LED/YELLOW/0603 | LED0603DWS | LED-0603 | CHGLED
1 | MICRO_SD/MMC_CP_NEWTFC-WPAPR-08 | MICRO_SD/MMC_CP_NEWTFC-WPAPR-08 | TFC-WPAPR-08 | SD
2 | 2.54pinhead 2x20 | 2.54pinhead 2x20 | 2.54pinhead 2x20 | GPIO-2, LCD_CON | HARTING
1 | MP1482DS | MP1482 | SOIC8 | U13
1 | PCF8563T/5 | PCF8563 | SO-8 | U14 | Real-time clock/calendar
2 | PJ-W47S-05D2-LF_V2 | AUDIO_JACK_5PINPJ-W47S-05D2-LF_V2 | PJ-W47S-05D2-LF_5PIN_V2 | HEADPHONES, MIC
11 | RA0805_(4X0402)_22R | R_MATRIX_4E_25X625 | R_MATRIX_4_0402_25X625 | RM1, RM2, RM3, RM4, RM5, RM6, RM7, RM8, RM9, RM10, RM16
1 | RA1206_(4X0603)_4B8_100K | R_MATRIX_4E | R_MATRIX_4 | RM12
1 | SMBJ16A | SMBJ16A | DO214AA | D8
3 | SN74ALVC244 | 74ALVC244 | PW | U5, U6, U7
2 | SY6280 | SY6280 | SOT23-5 | U8, U12
1 | SY7208(SOT23-6) | SY7208 | SOT23-6 | U16
2 | SY8008C(AA)C | SY8008 | SOT23-5 | U10, U15
7 | T1107A(6x3.8x2.5mm) | SW-TAKT6 | SW-TAKT_6X3.5_SMD | PWR_BUT, RESET, SW1, SW2, SW3, SW4, SW5
1 | USB-OTG | MINI_USB9 | USB_MINI_9PIN | USB_OTG
3 | USB_A_VERTICAL | USB_SHIELDUSB_A_VERTICAL | USB_A_VERTICAL_PTH | USB_HOST1, USB_HOST2, USB_HOST3
1 | VGA15 | DB1522 | DB15-F_22MM | VGA_DB15-F
1 | YDJ-1136 | PWR-JAKPWR_JACK_UNI_MILLING | PWR_JACK_UNI_MILLING | PWR

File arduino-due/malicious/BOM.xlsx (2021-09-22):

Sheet: Sheet1
Qty | Value | Device | Package | Parts | Description | BUILT_BY | CASE | MANUFACTURER_PART_NUMBER | PART_NUMBER | TYPE | VALUE
1 |  | 0644_4X1VP.2,54H11,8 | PH1X4-THT | DEBUG | 4x1 V P.2,54 H11,8
3 | 0R | 0039_JUMP_0402 | R0402 | JR1, R1, R8 | 0R 0402 |  | 0402 |  | JUMP_0402 | Resistenze | 0R
1 | 100K_1% | 2022_CR0603FW104L | R0603-ROUND | R28 | 0603 Resistor 100K 1% |  |  |  | CR0603FW104L |  | 100K_1%
1 | 100k | 0026_100K_0603 | R0603-ROUND | R30 | 100K 0603 |  | 0603 |  | 100K_0603 | Resistenze | 100k
2 | 100k | 0134_CR0402FX1003L | R0402 | R4, R16 | 100K 0402 |  | 0402 |  | CR0402FX1003 L | Resistenze | 100k
3 | 100k | 0168_CAY16-104J4LF | CAY16 | RN1, RN2, RN4 | 100K 064 R |  | SMD 3,2x1,6 |  | CAY16-104J4LF | Resistenze | 100k
2 | 100nF | 0015_100NF_0603 | C0603-ROUND | C41, C50 | 100nF 0603 50V |  | 0603 |  | cl10b104kbnc | Condensatori | 100nF
22 | 100nF | 0132_100NF_0402 | C0402 | C4, C5, C6, C7, C8, C9, C10, C12, C13, C14, C15, C16, C17, C18, C19, C28, C30, C31, C32, C34, C36, C37 | 100nF 0402 |  | 0402 |  | 100nF_0402 | Condensatori | 100nF
4 | 10K | 0136_CR0402FX1002_L | R0402 | R2, R13, R18, R99 | 10K 0402 |  | 0402 |  | CR0402FX1002_L | Resistenze | 10K
2 | 10n | 0165_10NF_0402 | C0402 | C20, C26 | 10nF 0402
1 | 12mHz-12pF-K7 | 0396_12MHZ-12PF-K7 | CRYSTAL-3.2-2.5 | Y1 | 12Mhz - K7 12pF - SMD |  |  |  |  |  | 12mHz-12pF-K7
1 | 157SW | 0173_IT-1185AP1C-160G-G_T&R | SMD_157SW | ERASE | Pushbutton 4x3 SMD H2,5mm |  |  |  | IT-1185AP1C-160G-G_T&R | Switches | 157SW
1 | 16Mhz-KX-7 | 0395_16.000MHZ__12PF | CRYSTAL-3.2-2.5 | Y4 | 16Mhz - K7 12pF - SMD |  |  |  | 16.000Mhz__12pF | Cristalli | 16Mhz-KX-7
1 | 18x2F-H8.5 | 1756_12TW323 | 2X18 | XIO | Female Gray Connector strip for Arduino 3V3 bases 18x2 F V h 8,5 p2,54 |  |  |  | 12TW323 | Connettori | 18x2F-H8.5
1 | 19K1_0,1% | 2339_ | R0603-ROUND | R29 | 19K1 0,1% 0603 |  | 0603 |  |  | Resistenze | 19K1_0,1%
1 | 1K | 0005_064R_1K_/_CAY16-102J4LF | CAY16 | RN3 | 1K 064R |  | SMD_3,2x1,6 |  | 064R_1K_/_CAY16-102J4LF | Resistenze | 1K
5 | 1K | 0140_1K_0402 | R0402 | R3, R14, R15, R21, R23 | 1K 0402 |  | 0402 |  | 1K_0402 | Resistenze | 1K
1 | 1K5 | 0163_1K5_ARRAY | CAY16 | RN5 | 1K5 064 R
1 | 1M | 0139_1M_0402 | R0402 | R9 | 1M 0402 |  | 0402 |  | 1M_0402 | Resistenze | 1M
1 | 1uF | 0133_1UF_0402 | C0402 | C38 | 1uF 0402 |  | 0402 |  | 1uF_0402 | Condensatori | 1uF
2 | 22R | 0468_22R_0402 | R0402 | R19, R20 | 22R 0402 |  | 0402 |  | 22R_0402 | Resistenze | 22R
7 | 22pF | 0137_22PF_0402 | C0402 | C21, C22, C23, C24, C25, C39, C40 | 22pF 0402 |  | 0402 |  | 22pF_0402 | Condensatori | 22pF
10 | 22uF | 0167_ | SMC_B | C1, C2, C3, C11, C27, C29, C33, C35, C49, PC2 | 22uF 25V |  |  |  |  | Condensatori | 22uF
1 | 2x2M - NM | XXXX_PINHD-2X2 | 2X02 | JP5 | PIN HEADER
1 | 32,768Khz_SMD | 0213_ABS07-32.768KHZ-T | RESONATOR_EPSON_FC_145 | Y2 | 32,768KHz - SMD |  |  |  | ABS07-32.768KHZ-T | Cristalli | 32,768Khz_SMD
2 | 39R 1% | 0138_39R_0402 | R0402 | R5, R6 | 39R 0402
1 | 47uF | 0113_47UF | PANASONIC_D | PC1 | 47uF |  |  |  | 47uF | Condensatori | 47uF
1 | 56k | 0411_56K_0603 | R0603-ROUND | R31 | 56K 0603 |  | 0603 |  | 56K_0603 | Resistenze | 56k
1 | 6K8 | 0164_6K8_0603 | R0603-ROUND | R7 | 6K8 0603 |  | 0603 |  | 6K8_0603 | Resistenze | 6K8
2 | 74AHC1G86DBV | 74AHC1G86DBV | SOT23-5 | IC2, IC3 | 2-input EXCLUSIV-OR gate
1 | 74LVC1G125DCKR | 0040_SN74LVC1G125DCKR | SC70-5 | IC10 | Single bus buffer with 3-state output |  | SC70 |  | SN74LVC1G125DCKR | Circuito_Integrato | 74LVC1G125DCKR
1 | 75K | 0376_CR0603FX7502_L | R0603-ROUND | R17 | 75K 0603 |  | 0603 |  | CR0603FX7502_L | Resistenze | 75K
1 | ATMEGA16U2-MU | 0007_ATMEGA16U2-MUR | MLF32 | IC6 | 8-bit Microcontroller with 16K Bytes of ISP Flash and USB Controller ATMEGA16U2-MUR |  | QFN32_5x5 |  | ATMEGA16U2-MUR | Circuito_Integrato | ATMEGA16U2-MU
1 | ATSAM3X8EA-AU | 0162_ATSAM3X8EA-AUAU | LQFP144 | U1 | AT91SAM ARM-based Flash MCU ATSAM3X8EA-AU |  | LQFP144 |  | ATSAM3X8EA-AU | Circuito_Integrato | ATSAM3X8EA-AU
1 | ATTINY102F-SSNRSOIC8_SA_SST_MCH-L | ATTINY102F-SSNRSOIC8_SA_SST_MCH-L | SOIC8_SA_SST_MCH-L | U2 |  | EMA_Molly |  | ATTINY102F-SSNR
1 | BC847B | 0169_BC847B | SOT23 | Q2 | BC847BSMD |  |  |  | BC847B | Transistor | BC847B
5 | BRNCG0603MLC-05E | 0010_BRNCG0603MLC-05E | CT/CN0603 | Z1, Z2, Z3, Z4, Z5 | CG0603MLC-05E |  |  |  | BRNCG0603MLC-05E | Protezione | BRNCG0603MLC-05E
1 | CD1206-S01575 | 0012_CD1206-S01575 | MINIMELF | D2 | small-signal high-speed Switching Diodes CD1206 |  | 1206 |  | CD1206-S01575 | Diodi | CD1206-S01575
5 | FH254-108DF08500V | 1683_20TW-536 | 1X08 | ADCH, ADCL, COMMUNICATION, POWER, PWML | Female Gray Connector strip for Arduino 3V3 bases - 8x1 F V h 8,5 p2,54mm |  |  |  | 20TW-536 | Connettori | FH254-108DF08500V
1 | FH254-110DF08500V | 1684_20TW-537 | 1X10 | PWMH | Female Gray Connector strip for Arduino 3V3 bases - 10x1 F V h 8,5 p2,54mm |  |  |  | 20TW-537 | Connettori | FH254-110DF08500V
4 | FIDUCIALMOUNT | FIDUCIALMOUNT | FIDUCIA-MOUNT | FID1, FID2, FID3, FID4
1 | Green | 0043_KPT-2012SGC | CHIPLED_0805 | ON | LED GREEN - SMD-0805 |  |  |  | KPT-2012SGC | Opto | Green
2 | ICSP | 0114_PH254-203DF118A00V | 2X03 | ICSP1, SPI | 3x2 M V h 8,5 mm p2,54 |  |  |  | PH254-203DF118A00V | Connettori | ICSP
1 | LMV358IDGKR | 0021_LMV358IDGKR | MSOP08 | IC1 | Dual low-voltage (2.7 V to 5.5 V), operational amplifiers with rail-to-rail output swing LMV358IDGKR |  | MSOP8 |  | LMV358IDGKR | Circuito_Integrato | LMV358IDGKR
1 | MCR-AB1-S-RA-SMT-TR | 0631_MCR-AB1-S-RA-SMT-TR | MCR-AB1-S-RA-SMT | USB1 | Usb Micro F/90 Smd Tipo AB |  |  |  | MCR-AB1-S-RA-SMT-TR | Connettori | MCR-AB1-S-RA-SMT-TR
1 | MCR-B-S-RA-SMT-CS1TR | 0158_MCR-B-S-RA-SMT-CS1TR | CON2_USB_MICRO_B_AT | USB2 | Usb Micro F/90 Smd Tipo B |  |  |  | MCR-B-S-RA-SMT-CS1TR | Connettori | MCR-B-S-RA-SMT-CS1TR
2 | MF-MSMF050-2 500mA | 0002_MF-MSMF050-2 | L1812 | F1, F2 | 500 mA Multifuse � Polyfuse |  |  |  | MF-MSMF050-2 | Protezione | MF-MSMF050-2 500mA
5 | MH2029-300Y | 0001_BLM21PG300SN1D_/_MH2029-300Y | 805 | L1, L2, L3, L5, L6 | BLM21 |  |  |  | BLM21PG300SN1D_/_MH2029-300Y | Protezione | MH2029-300Y
1 | MPM3610 | 2093_MPM3610GQV-P | QFN-20 | IC5 | MPM3610 Step Down Regulator |  | QFN-20 |  | MPM3610GQV-P | Circuito_Integrato | MPM3610
1 | MSS1P3L-M3/89A | 1653_MSS1P3L-M3/89A | MICROSMP | D1 | Surface Mount Schottky Barrier Rectifiers - Case microSMP |  |  |  |  |  | MSS1P3L-M3/89A
1 | NM | J0402 | J0402 | BR1 | Three terminal jumper made from two 0402, 0603, 0805, etc.
1 | NX1117CE33Z | 0045_NX1117CE33Z,115 | SOT223 | IC4 | Low-dropout linear regulator 3V3 NX1117CE33Z,115 |  | SOT223 |  | NX1117CE33Z,115 | Circuito_Integrato | NX1117CE33Z
1 | PINHEAD-2x5-P1.27 | 0171_PH127-205DF055G00AROUND-PADS | PINHEAD_2X05_127 | CN2 | 2x5 PASSO 1,27
4 | PMV48XP | 0297_PMV48XP | SOT-23 | T1, T2, T3, T4 | 20 V, 3.5 A P-channel Trench MOSFET - PMV48XP |  | SOT23 |  | PMV48XP | Transistor | PMV48XP
1 | POWER-SUPPLY | 0018_19746-POWER-SUPPLY | POWERSUPPLY_DC-21MM | X2 | JACK |  |  |  | 19746 | Connettori | POWER-SUPPLY
1 | SS1P3L | 0025_SS1P3L-M3/84A | DO220AAL | D5 | 1A 30V Schottky Barrier Rectifiers -SS1P3L-M3/84A |  | SMP |  | SS1P3L-M3/84A | Diodi | SS1P3L
1 | TS42 | 0946_TS42031-160W-TR-7260 | TS42 | RESET | Pushbutton 6x6 Smd - White |  |  |  | IT-1157AHNP-160G-G_GTR | Switches | TS42
5 | Yellow | 0044_KPT-2012YC | CHIPLED_0805 | L, RX, RX1, TX, TX1 | LED YELLOW - SMD - 0805 |  |  |  | KPT-2012YC | Opto | Yellow

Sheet: DUE_V02g
Qty;"Value";"Device";"Package";"Parts";"Description";"BUILT_BY";"CASE";"CODE-ARDUINO";"COPYRIGHT";"DATASHEET";"DISTRIBUTOR-LINK";"DISTRIBUTOR-PN";"MANUFACTURER";"MANUFACTURER-PN";"MANUFACTURER_PART_NUMBER";"MONTHLY_USAGE";"NOTE";"PART_NUMBER";"POPULARITY";"PRICE";"SOURCELIBRARY";"SUPPLIER";"TYPE";"VALUE";"VENDOR";
1;"";"0644_4X1VP.2,54H11,8";"PH1X4-THT";"DEBUG";"4x1 V P.2,54 H11,8";"";"";"";"";"";"";"";"";"";"";"";"";"";"";"";"";"";"";"";"";
3;"0R";"0039_JUMP_0402";"R0402";"JR1, R1, R8";"0R 0402";"";"0402";"";"";"";"";"";"";"";"";"_____";"";"JUMP_0402";"";"_____";"";"_____";"Resistenze";"0R";"";
1;"100K_1%";"2022_CR0603FW104L";"R0603-ROUND";"R28";"0603 Resistor 100K 1%";"";"";"";"";"";"";"";"";"";"";"";"";"CR0603FW104L";"";"";"";"";"";"100K_1%";"";
1;"100k";"0026_100K_0603";"R0603-ROUND";"R30";"100K 0603";"";"0603";"";"";"";"";"";"";"";"";"_____";"";"100K_0603";"";"_____";"";"_____";"Resistenze";"100k";"";
2;"100k";"0134_CR0402FX1003L";"R0402";"R4, R16";"100K 0402";"";"0402";"";"";"";"";"";"";"";"";"";"";"CR0402FX1003 L";"";"";"";"";"Resistenze";"100k";"";
3;"100k";"0168_CAY16-104J4LF";"CAY16";"RN1, RN2, RN4";"100K 064 R";"";"SMD 3,2x1,6";"";"";"";"";"";"";"";"";"";"";"CAY16-104J4LF";"";"";"";"";"Resistenze";"100k";"";
2;"100nF";"0015_100NF_0603";"C0603-ROUND";"C41, C50";"100nF 0603 50V";"";"0603";"";"";"";"";"";"";"";"";"_____";"";"cl10b104kbnc";"";"_____";"";"_____";"Condensatori";"100nF";"";
22;"100nF";"0132_100NF_0402";"C0402";"C4, C5, C6, C7, C8, C9, C10, C12, C13, C14, C15, C16, C17, C18, C19, C28, C30, C31, C32, C34, C36, C37";"100nF 0402";"";"0402";"";"";"";"";"";"";"";"";"_____";"";"100nF_0402";"";"_____";"";"_____";"Condensatori";"100nF";"";
4;"10K";"0136_CR0402FX1002_L";"R0402";"R2, R13, R18, R99";"10K 0402";"";"0402";"";"";"";"";"";"";"";"";"_____";"";"CR0402FX1002_L";"";"_____";"";"_____";"Resistenze";"10K";"";
2;"10n";"0165_10NF_0402";"C0402";"C20, C26";"10nF 0402";"";"";"";"";"";"";"";"";"";"";"";"";"";"";"";"";"";"";"";"";
1;"12mHz-12pF-K7";"0396_12MHZ-12PF-K7";"CRYSTAL-3.2-2.5";"Y1";"12Mhz - K7 12pF - SMD";"";"";"";"";"";"";"";"";"";"";"";"";"";"";"";"";"";"";"12mHz-12pF-K7";"";
1;"157SW";"0173_IT-1185AP1C-160G-G_T&R";"SMD_157SW";"ERASE";"Pushbutton 4x3 SMD H2,5mm";"";"";"";"";"";"";"";"";"";"";"_____";"";"IT-1185AP1C-160G-G_T&R";"";"_____";"";"_____";"Switches";"157SW";"";
1;"16Mhz-KX-7";"0395_16.000MHZ__12PF";"CRYSTAL-3.2-2.5";"Y4";"16Mhz - K7 12pF - SMD";"";"";"";"";"";"";"";"";"";"";"_____";"";"16.000Mhz__12pF";"";"_____";"";"_____";"Cristalli";"16Mhz-KX-7";"";
1;"18x2F-H8.5";"1756_12TW323";"2X18";"XIO";"Female Gray Connector strip for Arduino 3V3 bases 18x2 F V h 8,5 p2,54";"";"";"";"";"";"";"";"";"";"";"_____";"";"12TW323";"";"_____";"";"_____";"Connettori";"18x2F-H8.5";"";
1;"19K1_0,1%";"2339_";"R0603-ROUND";"R29";"19K1 0,1% 0603";"";"0603";"";"";"";"";"";"";"";"";"_____";"";"";"";"_____";"";"_____";"Resistenze";"19K1_0,1%";"";
1;"1K";"0005_064R_1K_/_CAY16-102J4LF";"CAY16";"RN3";"1K 064R";"";"SMD_3,2x1,6";"";"";"";"";"";"";"";"";"_____";"";"064R_1K_/_CAY16-102J4LF";"";"_____";"";"_____";"Resistenze";"1K";"";
5;"1K";"0140_1K_0402";"R0402";"R3, R14, R15, R21, R23";"1K 0402";"";"0402";"";"";"";"";"";"";"";"";"_____";"";"1K_0402";"";"_____";"";"_____";"Resistenze";"1K";"";
1;"1K5";"0163_1K5_ARRAY";"CAY16";"RN5";"1K5 064 R";"";"";"";"";"";"";"";"";"";"";"";"";"";"";"";"";"";"";"";"";
1;"1M";"0139_1M_0402";"R0402";"R9";"1M 0402";"";"0402";"";"";"";"";"";"";"";"";"_____";"";"1M_0402";"";"_____";"";"_____";"Resistenze";"1M";"";
1;"1uF";"0133_1UF_0402";"C0402";"C38";"1uF 0402";"";"0402";"";"";"";"";"";"";"";"";"_____";"";"1uF_0402";"";"_____";"";"_____";"Condensatori";"1uF";"";
2;"22R";"0468_22R_0402";"R0402";"R19, R20";"22R 0402";"";"0402";"";"";"";"";"";"";"";"";"_____";"";"22R_0402";"";"_____";"";"_____";"Resistenze";"22R";"";
7;"22pF";"0137_22PF_0402";"C0402";"C21, C22, C23, C24, C25, C39, C40";"22pF 0402";"";"0402";"";"";"";"";"";"";"";"";"_____";"";"22pF_0402";"";"_____";"";"_____";"Condensatori";"22pF";"";
10;"22uF";"0167_";"SMC_B";"C1, C2, C3, C11, C27, C29, C33, C35, C49, PC2";"22uF 25V";"";"";"";"";"";"";"";"";"";"";"_____";"";"";"";"_____";"";"_____";"Condensatori";"22uF";"";
1;"2x2M - NM";"XXXX_PINHD-2X2";"2X02";"JP5";"PIN HEADER";"";"";"";"";"";"";"";"";"";"";"";"";"";"";"";"";"";"";"";"";
1;"32,768Khz_SMD";"0213_ABS07-32.768KHZ-T";"RESONATOR_EPSON_FC_145";"Y2";"32,768KHz - SMD";"";"";"";"";"";"";"";"";"";"";"_____";"";"ABS07-32.768KHZ-T";"";"_____";"";"_____";"Cristalli";"32,768Khz_SMD";"";
2;"39R 1%";"0138_39R_0402";"R0402";"R5, R6";"39R 0402";"";"";"";"";"";"";"";"";"";"";"";"";"";"";"";"";"";"";"";"";
1;"47uF";"0113_47UF";"PANASONIC_D";"PC1";"47uF";"";"";"";"";"";"";"";"";"";"";"_____";"";"47uF";"";"_____";"";"_____";"Condensatori";"47uF";"";
1;"56k";"0411_56K_0603";"R0603-ROUND";"R31";"56K 0603";"";"0603";"";"";"";"";"";"";"";"";"_____";"";"56K_0603";"";"_____";"";"_____";"Resistenze";"56k";"";
1;"6K8";"0164_6K8_0603";"R0603-ROUND";"R7";"6K8 0603";"";"0603";"";"";"";"";"";"";"";"";"_____";"";"6K8_0603";"";"_____";"";"_____";"Resistenze";"6K8";"";
2;"74AHC1G86DBV";"74AHC1G86DBV";"SOT23-5";"IC2, IC3";"2-input EXCLUSIV-OR gate";"";"";"";"";"";"";"";"";"";"";"";"";"";"0";"";"";"";"";"";"";
1;"74LVC1G125DCKR";"0040_SN74LVC1G125DCKR";"SC70-5";"IC10";"Single bus buffer with 3-state output";"";"SC70";"";"";"";"";"";"";"";"";"_____";"";"SN74LVC1G125DCKR";"";"_____";"";"_____";"Circuito_Integrato";"74LVC1G125DCKR";"";
1;"75K";"0376_CR0603FX7502_L";"R0603-ROUND";"R17";"75K 0603";"";"0603";"";"";"";"";"";"";"";"";"_____";"";"CR0603FX7502_L";"";"_____";"";"_____";"Resistenze";"75K";"";
1;"ATMEGA16U2-MU";"0007_ATMEGA16U2-MUR";"MLF32";"IC6";"8-bit Microcontroller with 16K Bytes of ISP Flash and USB Controller ATMEGA16U2-MUR";"";"QFN32_5x5";"";"";"";"";"";"";"";"";"_____";"";"ATMEGA16U2-MUR";"";"_____";"";"_____";"Circuito_Integrato";"ATMEGA16U2-MU";"";
1;"ATSAM3X8EA-AU";"0162_ATSAM3X8EA-AUAU";"LQFP144";"U1";"AT91SAM ARM-based Flash MCU ATSAM3X8EA-AU";"";"LQFP144";"";"";"";"";"";"";"";"";"";"";"ATSAM3X8EA-AU";"";"";"";"";"Circuito_Integrato";"ATSAM3X8EA-AU";"";
1;"ATTINY102F-SSNRSOIC8_SA_SST_MCH-L";"ATTINY102F-SSNRSOIC8_SA_SST_MCH-L";"SOIC8_SA_SST_MCH-L";"U2";"";"EMA_Molly";"";"";"Copyright (C) 2018 Accelerated Designs. All rights reserved";"";"";"";"";"";"ATTINY102F-SSNR";"";"";"";"";"";"Microchip_2019-08-23_25";"";"";"";"Microchip";
1;"BC847B";"0169_BC847B";"SOT23";"Q2";"BC847BSMD";"";"";"";"";"";"";"";"";"";"";"_____";"";"BC847B";"";"_____";"";"_____";"Transistor";"BC847B";"";
5;"BRNCG0603MLC-05E";"0010_BRNCG0603MLC-05E";"CT/CN0603";"Z1, Z2, Z3, Z4, Z5";"CG0603MLC-05E";"";"";"";"";"";"";"";"";"";"";"_____";"";"BRNCG0603MLC-05E";"";"_____";"";"_____";"Protezione";"BRNCG0603MLC-05E";"";
1;"CD1206-S01575";"0012_CD1206-S01575";"MINIMELF";"D2";"small-signal high-speed Switching Diodes CD1206";"";"1206";"";"";"";"";"";"";"";"";"_____";"";"CD1206-S01575";"";"_____";"";"_____";"Diodi";"CD1206-S01575";"";
2;"DNP";"A3-FRAME";"FRAME";"U$1, U$2";"";"";"";"DNP";"";"DNP";"DNP";"DNP";"DNP";"DNP";"";"";"DNP";"";"";"";"";"";"";"DNP";"";
8;"DNP";"TPTP-1.00MM";"TP-1.00MM";"UD+1, UD+2, UD-1, UD-2, UGND1, UGND2, UVB1, UVB2";"Testpoint";"";"";"";"";"DNP";"DNP";"DNP";"DNP";"DNP";"";"";"";"";"";"";"";"";"";"DNP";"";
5;"FH254-108DF08500V";"1683_20TW-536";"1X08";"ADCH, ADCL, COMMUNICATION, POWER, PWML";"Female Gray Connector strip for Arduino 3V3 bases - 8x1 F V h 8,5 p2,54mm";"";"";"";"";"";"";"";"";"";"";"_____";"";"20TW-536";"";"_____";"";"_____";"Connettori";"FH254-108DF08500V";"";
1;"FH254-110DF08500V";"1684_20TW-537";"1X10";"PWMH";"Female Gray Connector strip for Arduino 3V3 bases - 10x1 F V h 8,5 p2,54mm";"";"";"";"";"";"";"";"";"";"";"_____";"";"20TW-537";"";"_____";"";"_____";"Connettori";"FH254-110DF08500V";"";
4;"FIDUCIALMOUNT";"FIDUCIALMOUNT";"FIDUCIA-MOUNT";"FID1, FID2, FID3, FID4";"";"";"";"";"";"";"";"";"";"";"";"";"";"";"";"";"";"";"";"";"";
1;"Green";"0043_KPT-2012SGC";"CHIPLED_0805";"ON";"LED GREEN - SMD-0805";"";"";"";"";"";"";"";"";"";"";"_____";"";"KPT-2012SGC";"";"_____";"";"_____";"Opto";"Green";"";
2;"ICSP";"0114_PH254-203DF118A00V";"2X03";"ICSP1, SPI";"3x2 M V h 8,5 mm p2,54";"";"";"";"";"";"";"";"";"";"";"_____";"";"PH254-203DF118A00V";"";"_____";"";"_____";"Connettori";"ICSP";"";
1;"LMV358IDGKR";"0021_LMV358IDGKR";"MSOP08";"IC1";"Dual low-voltage (2.7 V to 5.5 V), operational amplifiers with rail-to-rail output swing LMV358IDGKR";"";"MSOP8";"";"";"";"";"";"";"";"";"_____";"";"LMV358IDGKR";"";"_____";"";"_____";"Circuito_Integrato";"LMV358IDGKR";"";
1;"MCR-AB1-S-RA-SMT-TR";"0631_MCR-AB1-S-RA-SMT-TR";"MCR-AB1-S-RA-SMT";"USB1";"Usb Micro F/90 Smd Tipo AB";"";"";"";"";"";"";"";"";"";"";"_____";"";"MCR-AB1-S-RA-SMT-TR";"";"_____";"";"_____";"Connettori";"MCR-AB1-S-RA-SMT-TR";"";
1;"MCR-B-S-RA-SMT-CS1TR";"0158_MCR-B-S-RA-SMT-CS1TR";"CON2_USB_MICRO_B_AT";"USB2";"Usb Micro F/90 Smd Tipo B";"";"";"";"";"";"";"";"";"";"";"_____";"";"MCR-B-S-RA-SMT-CS1TR";"";"_____";"";"_____";"Connettori";"MCR-B-S-RA-SMT-CS1TR";"";
2;"MF-MSMF050-2 500mA";"0002_MF-MSMF050-2";"L1812";"F1, F2";"500 mA Multifuse 锟?Polyfuse";"";"";"";"";"";"";"";"";"";"";"_____";"";"MF-MSMF050-2";"";"_____";"";"_____";"Protezione";"MF-MSMF050-2 500mA";"";
5;"MH2029-300Y";"0001_BLM21PG300SN1D_/_MH2029-300Y";"0805";"L1, L2, L3, L5, L6";"BLM21";"";"";"";"";"";"";"";"";"";"";"_____";"";"BLM21PG300SN1D_/_MH2029-300Y";"";"_____";"";"_____";"Protezione";"MH2029-300Y";"";
1;"MPM3610";"2093_MPM3610GQV-P";"QFN-20";"IC5";"MPM3610 Step Down Regulator";"";"QFN-20";"";"";"";"";"";"";"";"";"";"";"MPM3610GQV-P";"";"";"";"";"Circuito_Integrato";"MPM3610";"";
1;"MSS1P3L-M3/89A";"1653_MSS1P3L-M3/89A";"MICROSMP";"D1";"Surface Mount Schottky Barrier Rectifiers - Case microSMP";"";"";"";"";"";"";"";"";"";"";"";"";"";"";"";"";"";"";"MSS1P3L-M3/89A";"";
1;"NM";"J0402";"J0402";"BR1";"Three terminal jumper made from two 0402, 0603, 0805, etc.";"";"";"";"";"";"";"";"";"";"";"";"";"";"";"";"";"";"";"";"";
1;"NX1117CE33Z";"0045_NX1117CE33Z,115";"SOT223";"IC4";"Low-dropout linear regulator 3V3 NX1117CE33Z,115";"";"SOT223";"";"";"";"";"";"";"";"";"_____";"";"NX1117CE33Z,115";"";"_____";"";"_____";"Circuito_Integrato";"NX1117CE33Z";"";
1;"PINHEAD-2x5-P1.27";"0171_PH127-205DF055G00AROUND-PADS";"PINHEAD_2X05_127";"CN2";"2x5 PASSO 1,27";"";"";"";"";"";"";"";"";"";"";"";"";"";"";"";"";"";"";"";"";
4;"PMV48XP";"0297_PMV48XP";"SOT-23";"T1, T2, T3, T4";"20 V, 3.5 A P-channel Trench MOSFET - PMV48XP";"";"SOT23";"";"";"";"";"";"";"";"";"_____";"";"PMV48XP";"";"_____";"";"_____";"Transistor";"PMV48XP";"";
1;"POWER-SUPPLY";"0018_19746-POWER-SUPPLY";"POWERSUPPLY_DC-21MM";"X2";"JACK";"";"";"";"";"";"";"";"";"";"";"_____";"";"19746";"";"_____";"";"_____";"Connettori";"POWER-SUPPLY";"";
1;"SS1P3L";"0025_SS1P3L-M3/84A";"DO220AAL";"D5";"1A 30V Schottky Barrier Rectifiers -SS1P3L-M3/84A";"";"SMP";"";"";"";"";"";"";"";"";"_____";"";"SS1P3L-M3/84A";"";"_____";"";"_____";"Diodi";"SS1P3L";"";
1;"TS42";"0946_TS42031-160W-TR-7260";"TS42";"RESET";"Pushbutton 6x6 Smd - White";"";"";"";"";"";"";"";"";"";"";"_____";"";"IT-1157AHNP-160G-G_GTR";"";"_____";"";"_____";"Switches";"TS42";"";
5;"Yellow";"0044_KPT-2012YC";"CHIPLED_0805";"L, RX, RX1, TX, TX1";"LED YELLOW - SMD - 0805";"";"";"";"";"";"";"";"";"";"";"_____";"";"KPT-2012YC";"";"_____";"";"_____";"Opto";"Yellow";"";

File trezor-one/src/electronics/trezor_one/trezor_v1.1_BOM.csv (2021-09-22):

Qty | Value | Device | Package | Parts | Description
7 | 100n | C_0402 | 402 | C7, C9, C12, C13, C14, C15, C16
1 | 12k | R_0402 | 402 | R7
1 | 1M | R_0603 | 603 | R9
1 | 1k5 | R_0402 | 402 | R6
1 | 1n/200V | C_0603 | 603 | C19
5 | 1u | C_0402 | 402 | C1, C2, C3, C4, C18
2 | 22R | R_0402 | 402 | R3, R4
1 | 22k | R_0402 | 402 | R8
2 | 22p | C_0402 | 402 | C20, C21
2 | 2u2 | C_0402 | 402 | C6, C8
1 | 2u2 | C_0603 | 603 | C5
1 | 390k | R_0402 | 402 | R10
1 | 4u7 | C_0603 | 603 | C10
1 | 8MHz | CRYSTALCTS406 | CTS406 | Q2 | CRYSTAL
1 | BAT60BWS | DS_SOD323 | SOD323 | D2
1 | DISPLAY | DISP_OLED_UG-2864HSWEG010.96";UG-2864HSWEG01_0.96IN_WRAPAROUND" | U3 | UG-2864HSWEG01 OLED display
1 | MCP1703T-3302E/CB | MCP1703CB | SOT23 | IC1 | 250 mA, 16V, Low Quiescent Current LDO Regulator
1 | MF-FSMF020X-2 | POLYSWITCH_0603 | 603 | R2
1 | PRTR5V0U2X | PRTR5V0_SOT143B | SOT143B | D1
1 | STM32F205RET6 | STM32F10XRXT6 | TQFP64 | U1 | STM32F101/103 64pin LQFP
1 | SWD | SWD | SWD | K2 | SWD
2 | SWITCH-MOMENTARY-2SMD | SWITCH-MOMENTARY-2SMD | TACTILE_SWITCH_SMD | S1, S2 | Various NO switches- pushbuttons, reed, etc
1 | USB5_USB_MICRO_MOLEX475890001 | USB5_USB_MICRO_MOLEX475890001 | USB_MICRO-MOLEX475890001 | K1

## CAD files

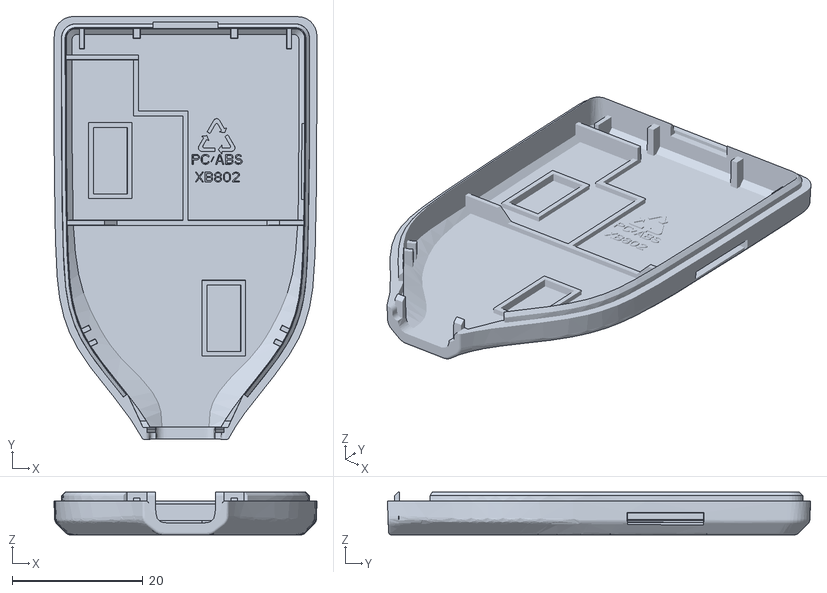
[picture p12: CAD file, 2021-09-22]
trezor-one/src/case/trezor_model_t/v1/bottom.stl
40.2 x 64.7 x 6.55

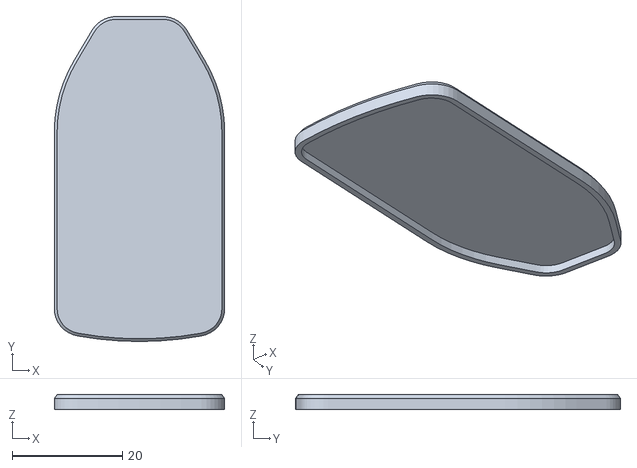
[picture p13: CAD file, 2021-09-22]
trezor-one/src/case/trezor_one/v3/cover-down.stl
30.9 x 58.9 x 2.64

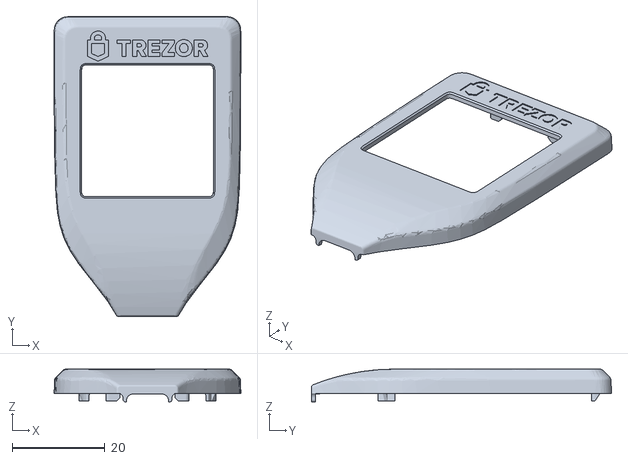
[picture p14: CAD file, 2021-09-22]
trezor-one/src/case/trezor_model_t/v1/top.stl
40.2 x 64.6 x 7.05

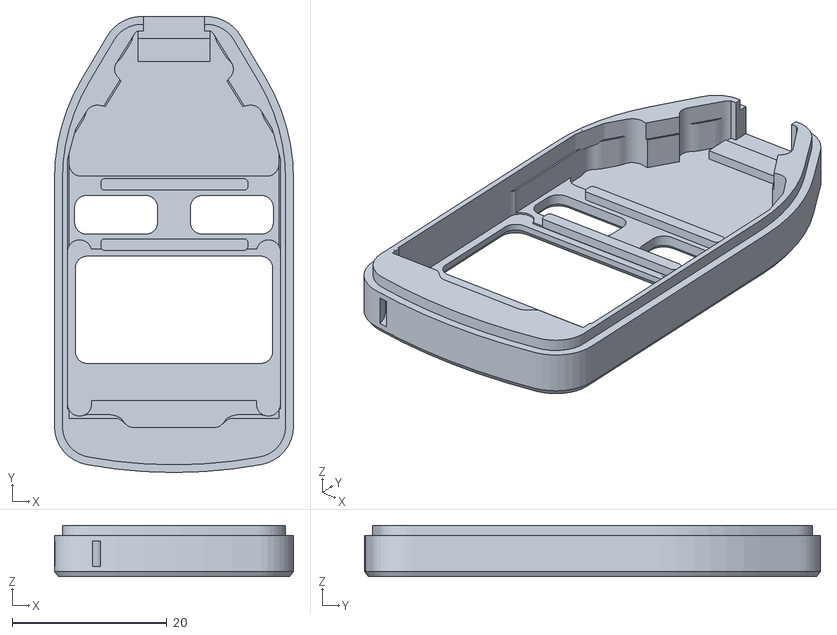
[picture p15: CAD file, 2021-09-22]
trezor-one/src/case/trezor_one/v3/cover-up.stl
30.9 x 58.9 x 6.61

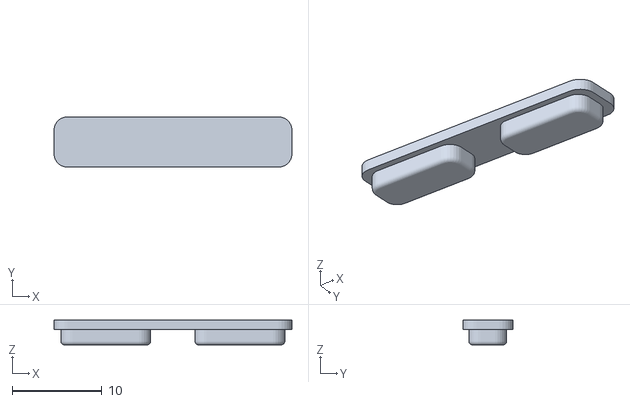
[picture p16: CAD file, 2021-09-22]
trezor-one/src/case/trezor_one/v3/buttons.stl
26.5 x 5.60 x 2.76

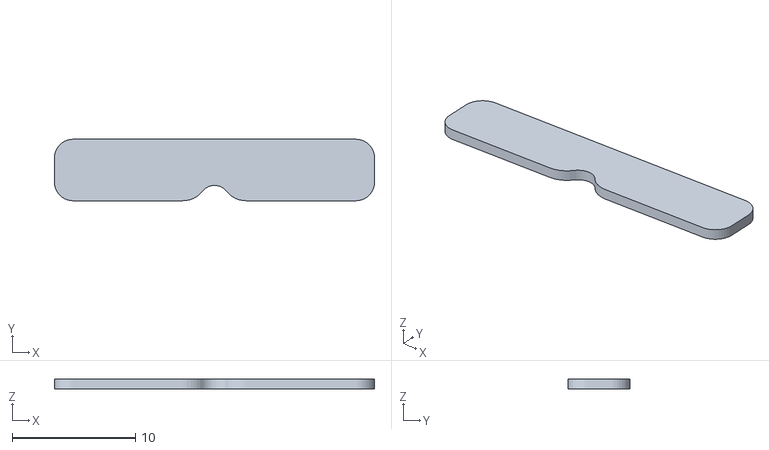
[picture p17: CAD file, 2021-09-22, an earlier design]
trezor-one/src/case/trezor_one/v1/button-down.stl
26.0 x 5.00 x 0.8

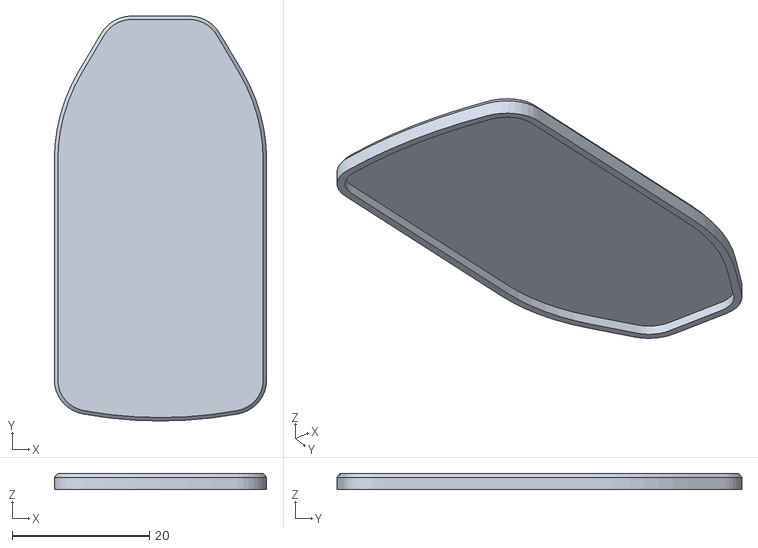
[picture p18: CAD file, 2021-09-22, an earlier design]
trezor-one/src/case/trezor_one/v2/cover-down-3.stl
30.9 x 58.9 x 2.40

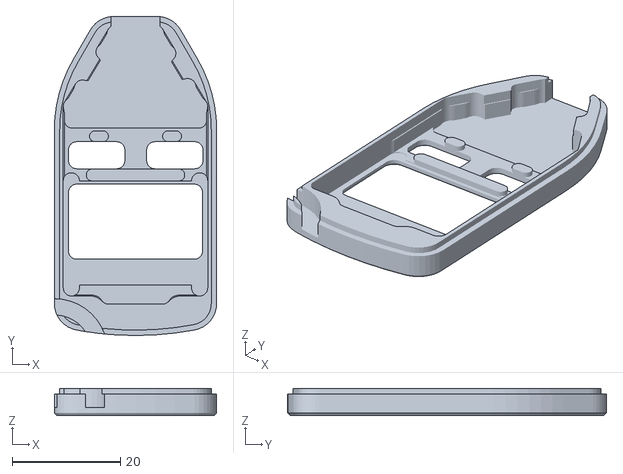
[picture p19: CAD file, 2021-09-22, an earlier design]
trezor-one/src/case/trezor_one/v1/cover-up.stl
30.0 x 58.9 x 5.00

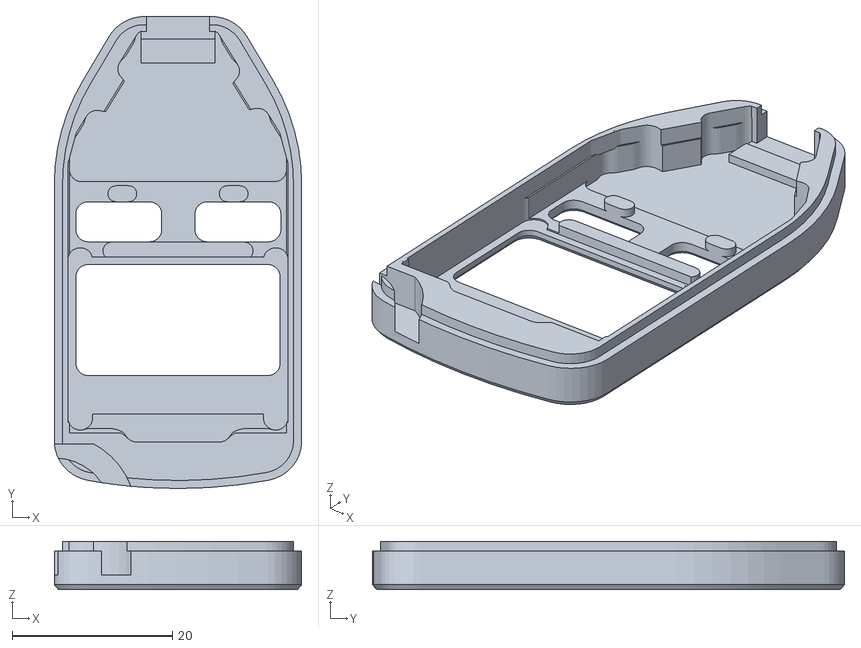
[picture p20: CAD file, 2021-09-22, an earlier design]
trezor-one/src/case/trezor_one/v2/cover-up-3.stl
30.9 x 58.9 x 6.01

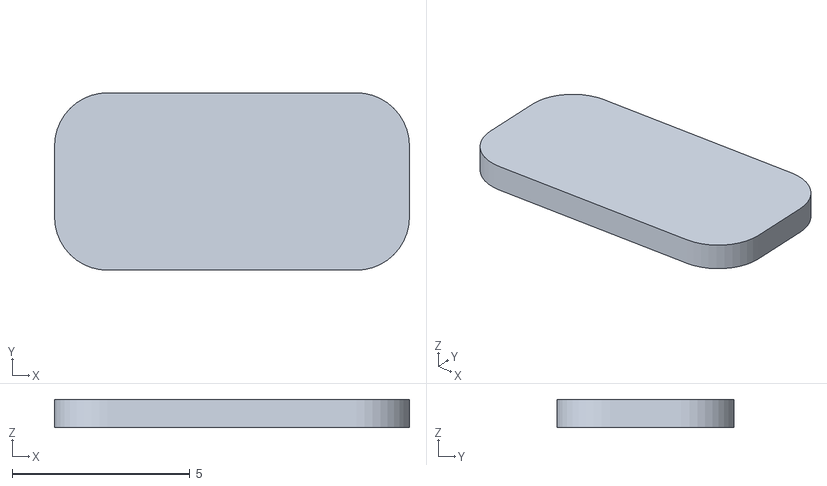
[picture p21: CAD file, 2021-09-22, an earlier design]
trezor-one/src/case/trezor_one/v1/button-up-1.stl
10.0 x 5.00 x 0.8

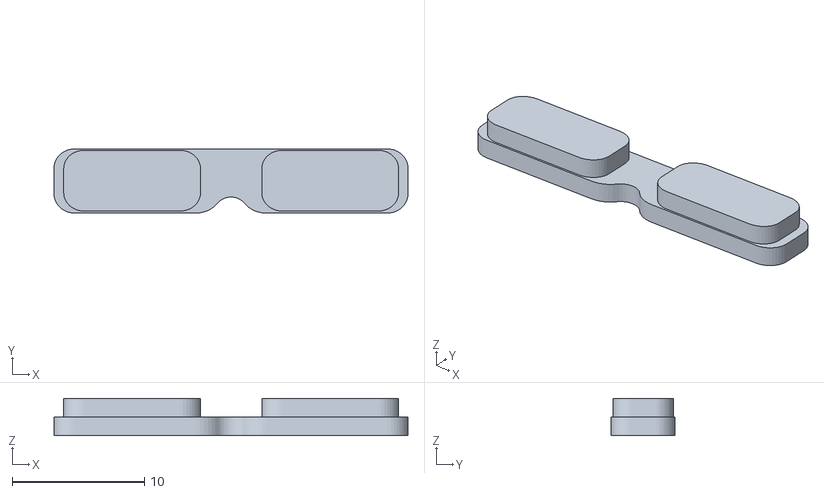
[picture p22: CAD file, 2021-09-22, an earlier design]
trezor-one/src/case/trezor_one/v2/buttons.stl
26.8 x 4.85 x 2.82

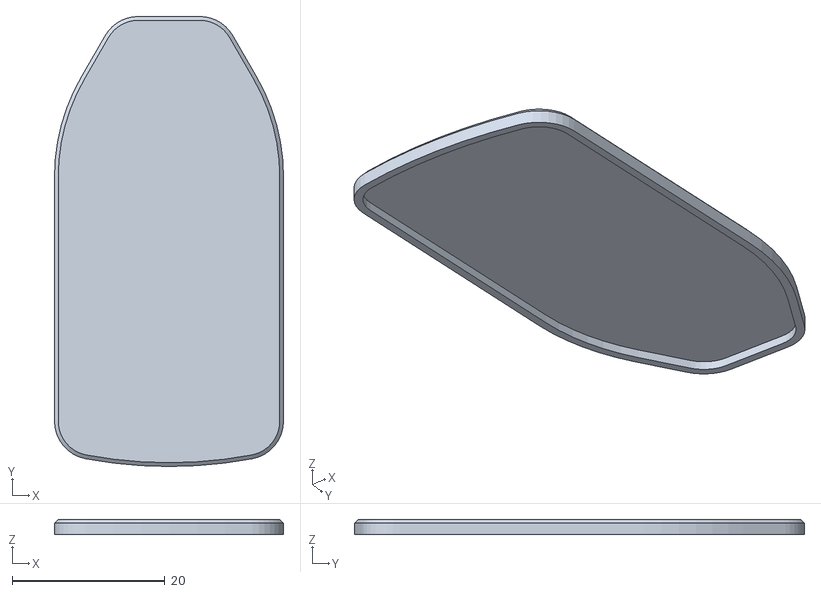
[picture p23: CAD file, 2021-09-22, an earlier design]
trezor-one/src/case/trezor_one/v1/cover-down.stl
30.0 x 58.9 x 2.00

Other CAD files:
trezor-one/src/case/trezor_one/v1/button-up-2.stl

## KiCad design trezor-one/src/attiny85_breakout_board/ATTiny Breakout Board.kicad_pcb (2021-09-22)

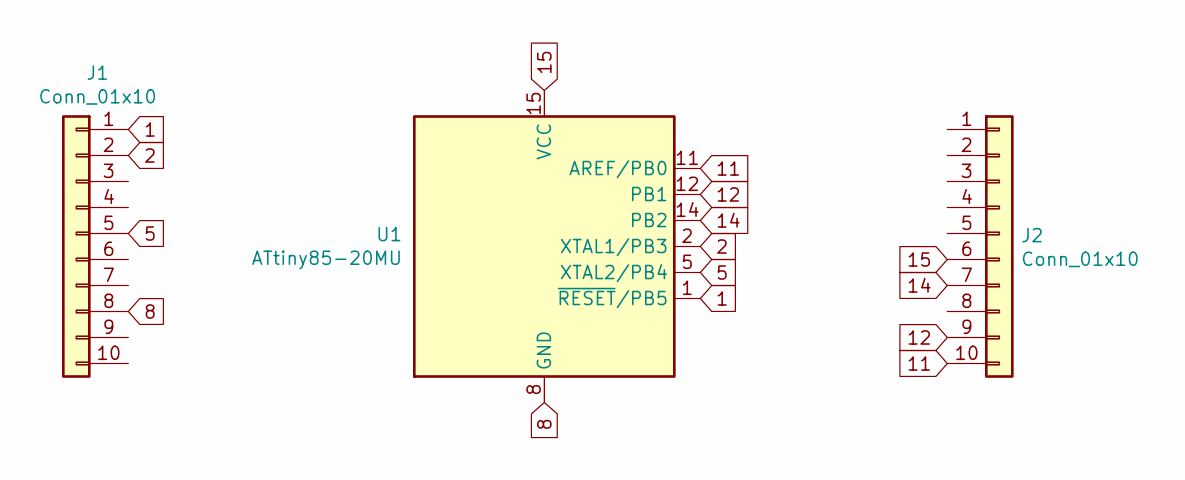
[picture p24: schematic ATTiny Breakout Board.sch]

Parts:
J1, J2: Conn_01x10; PinHeader_1x10_P2.54mm_Vertical
U1: ATtiny85-20MU; QFN-20-1EP_4x4mm_P0.5mm_EP2.6x2.6mm

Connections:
1: J1.1, U1.1 (~RESET~/PB5)
2: J1.2, U1.2 (XTAL1/PB3)
5: J1.5, U1.5 (XTAL2/PB4)
8: J1.8, U1.8 (GND), U1.21 (GND)
11: J2.10, U1.11 (AREF/PB0)
12: J2.9, U1.12 (PB1)
14: J2.7, U1.14 (PB2)
15: J2.6, U1.15 (VCC)
unnamed: J1.3, U1.3 (NC)
unnamed: J1.4, U1.4 (NC)
unnamed: J1.6, U1.6 (NC)
unnamed: J1.7, U1.7 (NC)
unnamed: J1.9, U1.9 (NC)
unnamed: J1.10, U1.10 (NC)
unnamed: J2.1, U1.20 (NC)
unnamed: J2.2, U1.19 (NC)
unnamed: J2.3, U1.18 (NC)
unnamed: J2.4, U1.17 (NC)
unnamed: J2.5, U1.16 (NC)
unnamed: J2.8, U1.13 (NC)

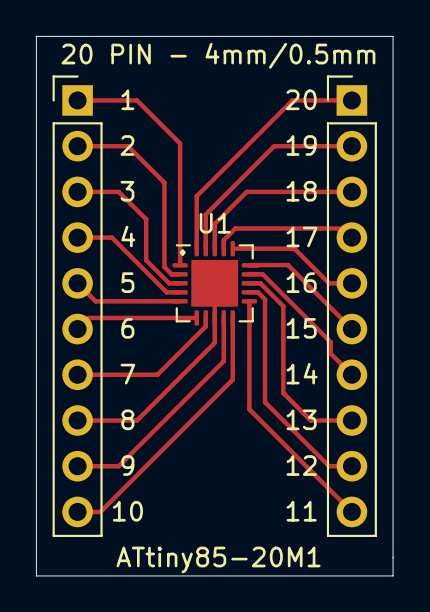
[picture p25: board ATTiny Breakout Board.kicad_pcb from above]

Board: 2 copper layers, 19.8 x 30.0 mm, 3 parts (0 on the bottom side), 20 nets.

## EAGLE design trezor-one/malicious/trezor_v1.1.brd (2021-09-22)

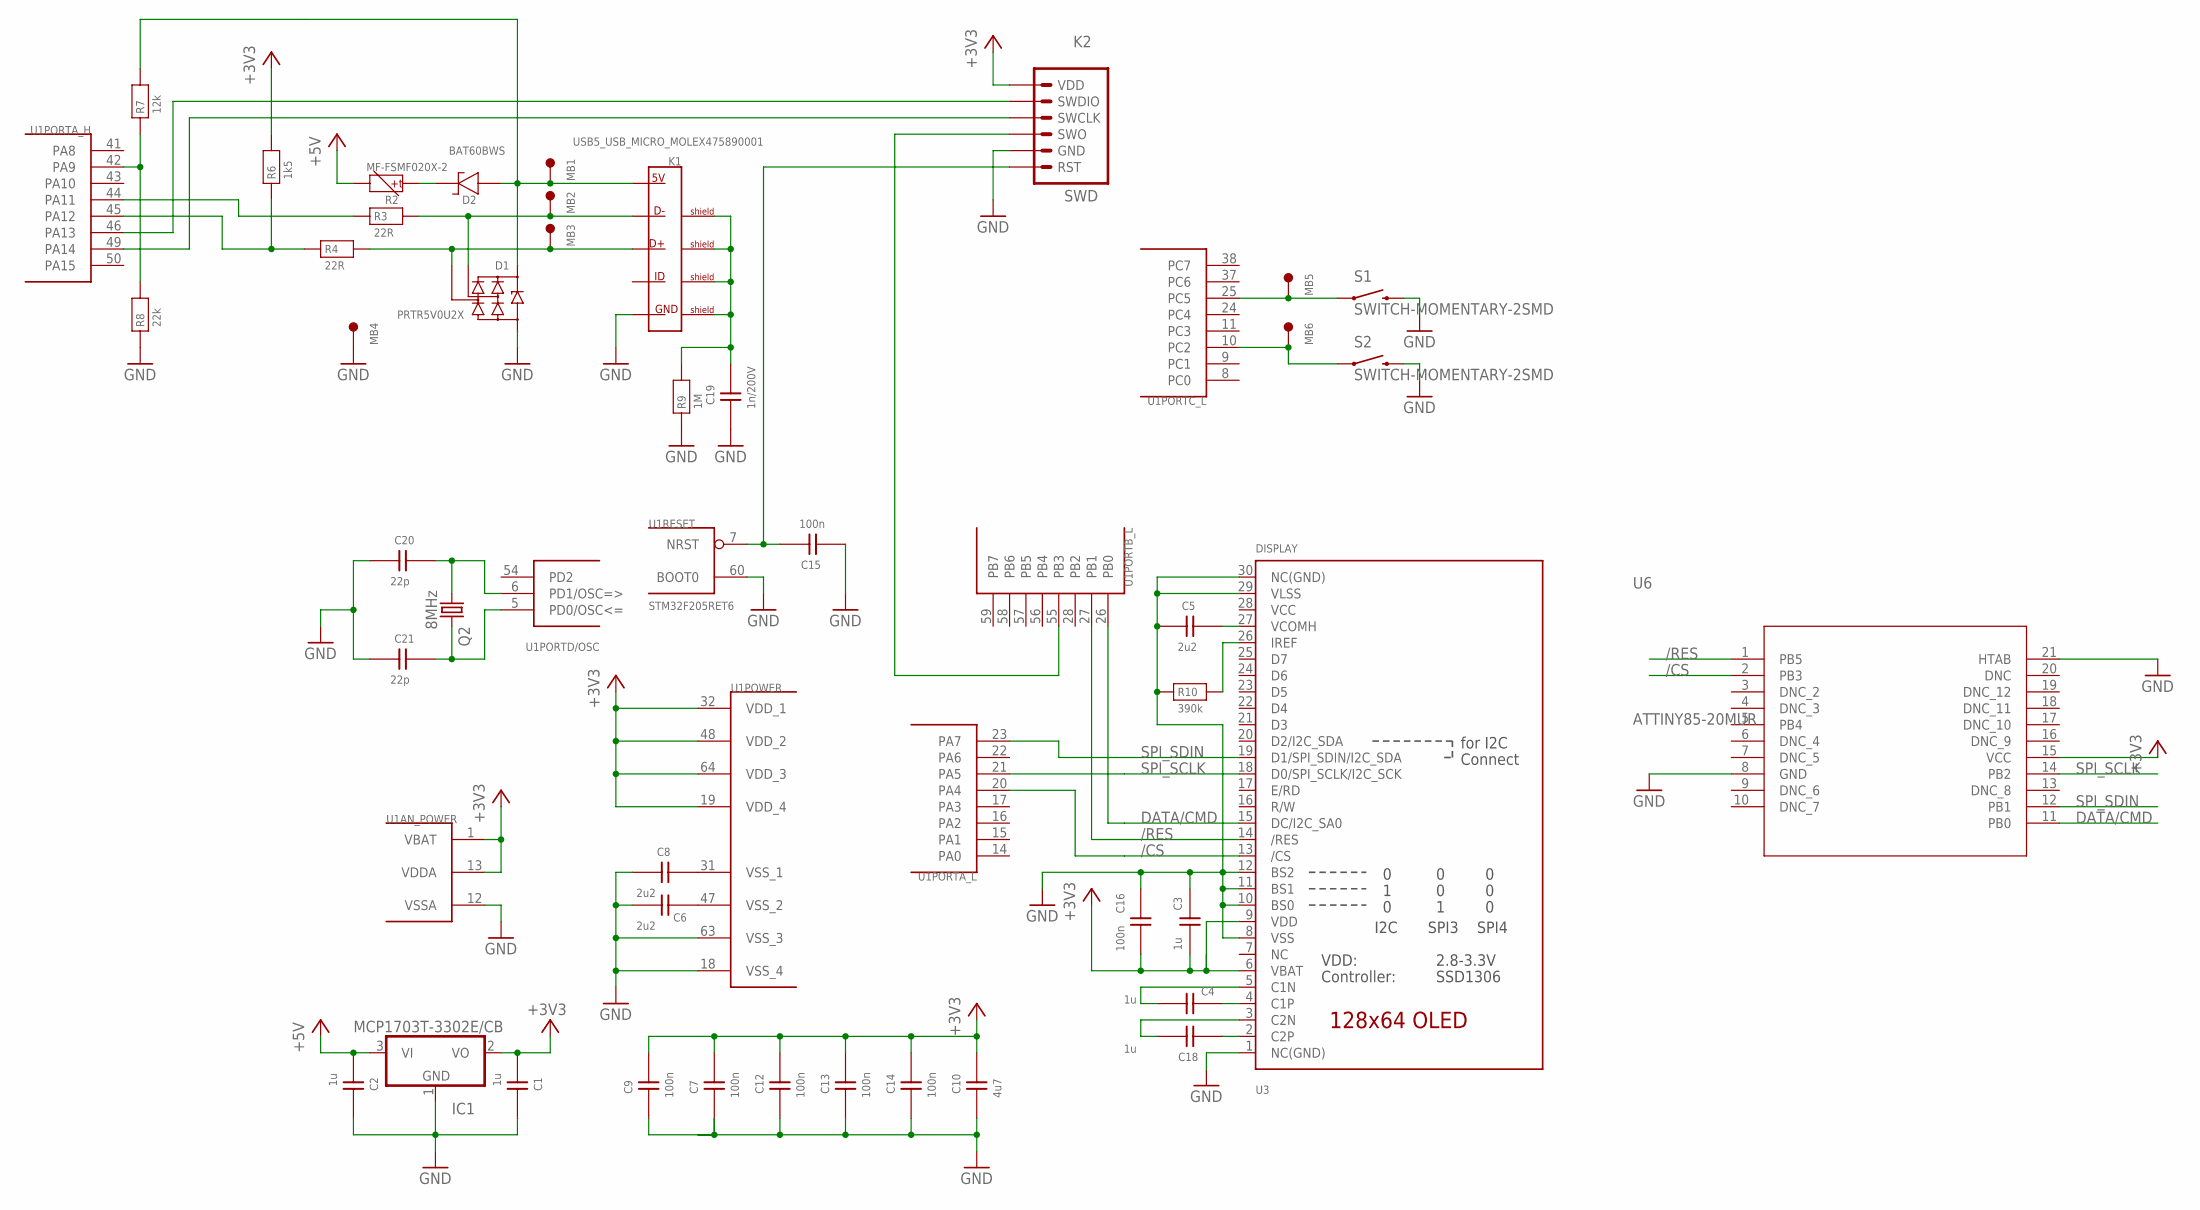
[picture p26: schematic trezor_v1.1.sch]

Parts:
C1, C2, C3, C4, C18: 1u; 0402
C5: 2u2; 0603
C6, C8: 2u2; 0402
C7, C9, C12, C13, C14, C15, C16: 100n; 0402
C10: 4u7; 0603
C19: 1n/200V; 0603
C20, C21: 22p; 0402
D1: PRTR5V0U2X; SOT143B
D2: BAT60BWS; SOD323
IC1: MCP1703T-3302E/CB; SOT23
K1: USB5_USB_MICRO_MOLEX475890001; USB_MICRO-MOLEX475890001
K2: SWD
MB1, MB2, MB3, MB4, MB5, MB6: MB_1.50; MB1.5
Q2: 8MHz; CTS406
R2: MF-FSMF020X-2; 0603
R3, R4: 22R; 0402
R6: 1k5; 0402
R7: 12k; 0402
R8: 22k; 0402
R9: 1M; 0603
R10: 390k; 0402
S1, S2: SWITCH-MOMENTARY-2SMD; TACTILE_SWITCH_SMD
U1: STM32F205RET6; TQFP64
U3: DISPLAY; UG-2864HSWEG01_0.96IN_WRAPAROUND
U6: ATTINY85-20MUR; 20M1_ATM

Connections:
+3V3: C1.P$1 (1), C3.P$1 (1), C7.P$2 (2), C9.P$2 (2), C10.2, C12.P$2 (2), C13.P$2 (2), C14.P$2 (2), C16.P$1 (1), IC1.2 (VO), K2.6 (VDD), R6.P$2 (2), U1.1 (VBAT), U1.13 (VDDA), U1.19 (VDD_4), U1.32 (VDD_1), U1.48 (VDD_2), U1.64 (VDD_3), U3.6 (VBAT), U3.9 (VDD), U6.15 (VCC)
+5V: C2.P$1 (1), IC1.3 (VI), R2.2
/CS: U1.20 (PA4), U3.13 (/CS), U6.2 (PB3)
/RES: U1.27 (PB1), U3.14 (/RES), U6.1 (PB5)
DATA/CMD: U1.26 (PB0), U3.15 (DC/I2C_SA0), U6.11 (PB0)
GND: C1.P$2 (2), C2.P$2 (2), C3.P$2 (2), C5.1, C6.P$1 (1), C7.P$1 (1), C8.P$1 (1), C9.P$1 (1), C10.1, C12.P$1 (1), C13.P$1 (1), C14.P$1 (1), C15.P$1 (1), C16.P$2 (2), C19.1, C20.P$1 (1), C21.P$1 (1), D1.1 (GND), IC1.1 (GND), K1.5 (5_GND), K2.2 (GND), MB4.1, R8.P$1 (1), R9.1, R10.P$1 (1), S1.3 (2), S1.4 (2), S2.3 (2), S2.4 (2), U1.12 (VSSA), U1.18 (VSS_4), U1.60 (BOOT0), U1.63 (VSS_3), U3.1 (NC(GND)), U3.8 (VSS), U3.10 (BS0), U3.11 (BS1), U3.12 (BS2), U3.29 (VLSS), U3.30 (NC(GND)), U6.8 (GND), U6.21 (HTAB)
unnamed: C15.P$2 (2), K2.1 (RST), U1.7 (NRST)
unnamed: C8.P$2 (2), U1.31 (VSS_1)
unnamed: C5.2, U3.27 (VCOMH)
unnamed: C6.P$2 (2), U1.47 (VSS_2)
unnamed: R10.P$2 (2), U3.26 (IREF)
unnamed: C18.P$1 (1), U3.2 (C2P)
unnamed: C4.P$1 (1), U3.4 (C1P)
unnamed: C18.P$2 (2), U3.3 (C2N)
unnamed: C4.P$2 (2), U3.5 (C1N)
unnamed: K2.3 (SWO), U1.55 (PB3)
unnamed: K2.5 (SWDIO), U1.46 (PA13)
unnamed: K2.4 (SWCLK), U1.49 (PA14)
unnamed: R3.P$1 (1), U1.44 (PA11)
unnamed: MB5.1, S1.1, S1.2 (1), U1.25 (PC5)
unnamed: MB6.1, S2.1, S2.2 (1), U1.10 (PC2)
unnamed: D1.4 (VCC), D2.A (1), K1.1 (1_5V), MB1.1, R7.P$2 (2)
unnamed: D2.K (2), R2.1
unnamed: D1.2 (I/O1), K1.2 (2_D-), MB2.1, R3.P$2 (2)
unnamed: D1.3 (I/O2), K1.3 (3_D+), MB3.1, R4.P$2 (2)
unnamed: C19.2, K1.S1_BOT (SHIELD_1), K1.S1_TOP (SHIELD_1), K1.S2_BOT (SHIELD_2), K1.S2_TOP (SHIELD_2), K1.S3_BOT (SHIELD_3), K1.S3_TOP (SHIELD_3), K1.S4_BOT (SHIELD_4), K1.S4_TOP (SHIELD_4), K1.SA (SHIELD_1), K1.SB (SHIELD_2), R9.2
unnamed: R7.P$1 (1), R8.P$2 (2), U1.42 (PA9)
SPI_SCLK: U1.21 (PA5), U3.18 (D0/SPI_SCLK/I2C_SCK), U6.14 (PB2)
SPI_SDIN: U1.23 (PA7), U3.19 (D1/SPI_SDIN/I2C_SDA), U6.12 (PB1)
USB_D_P: R4.P$1 (1), R6.P$1 (1), U1.45 (PA12)
VCC: U3.28 (VCC)
XTAL1: C20.P$2 (2), Q2.1, U1.6 (PD1/OSC=>)
XTAL2: C21.P$2 (2), Q2.3 (2), U1.5 (PD0/OSC<=)

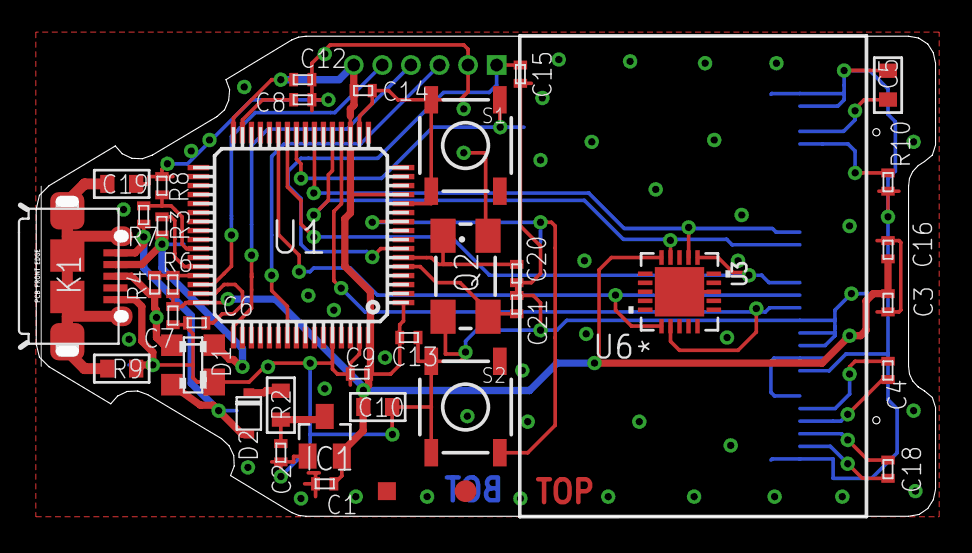
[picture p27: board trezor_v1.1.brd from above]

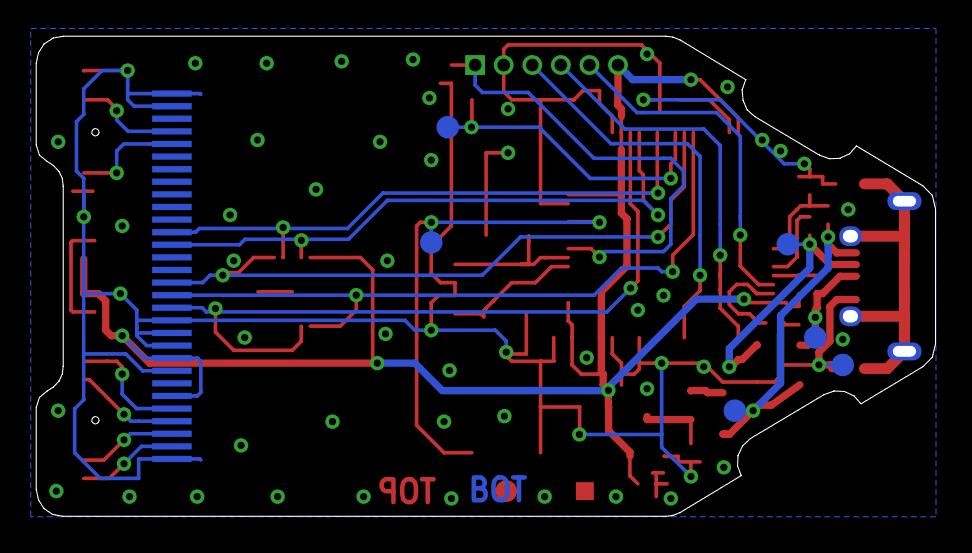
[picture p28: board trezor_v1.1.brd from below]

Board: 2 copper layers, 50.0 x 26.7 mm, 46 parts (6 on the bottom side), 32 nets.

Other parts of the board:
U$3: BADMARK
U$4: CENTR

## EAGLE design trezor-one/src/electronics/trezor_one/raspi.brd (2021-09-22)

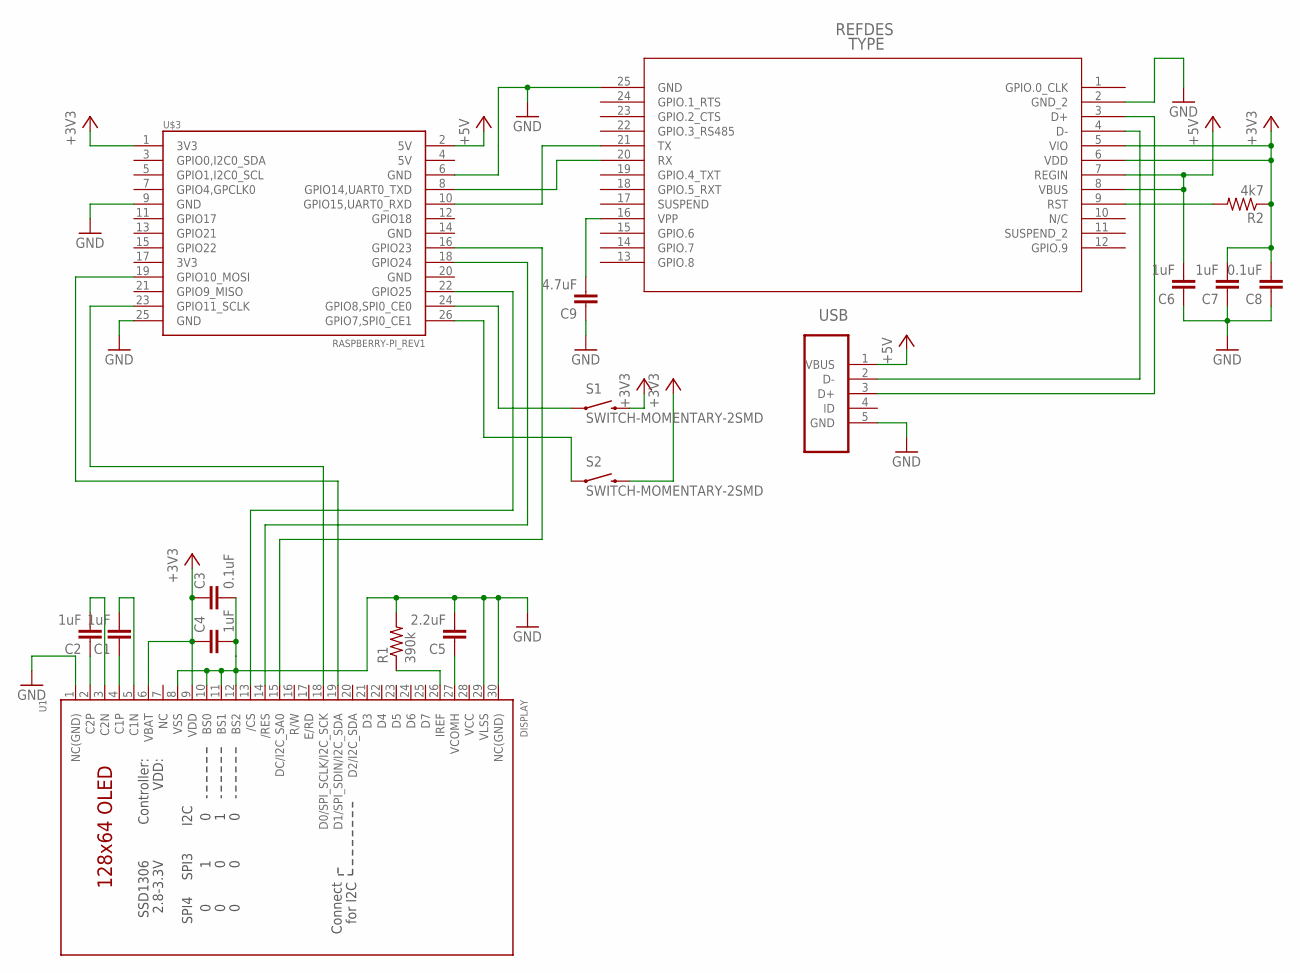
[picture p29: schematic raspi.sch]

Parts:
C1, C2, C4, C6, C7: 1uF; 0805
C3, C8: 0.1uF; 0805
C5: 2.2uF; 0805
C9: 4.7uF; 0805
R1: 390k; 0805
R2: 4k7; 0805
S1, S2: SWITCH-MOMENTARY-2SMD; TACTILE_SWITCH_SMD
U1: DISPLAY; UG-2864HSWEG01_0.96IN_WRAPAROUND
U2: CP2110-F01-GM
U$3: RASPBERRY-PI_REV1
USB: 47346-0001; MOLEX_47346-0001

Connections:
+3V3: C3.1, C4.1, C7.2, C8.2, R2.1, S1.3 (2), S2.3 (2), U1.6 (VBAT), U1.9 (VDD), U2.5 (VIO), U2.6 (VDD), U$3.1 (3V3)
+5V: C6.2, U2.7 (REGIN), U2.8 (VBUS), U$3.2 (5V), USB.1 (VBUS)
GND: C3.2, C4.2, C5.2, C6.1, C7.1, C8.1, C9.1, R1.2, U1.1 (NC(GND)), U1.8 (VSS), U1.10 (BS0), U1.11 (BS1), U1.12 (BS2), U1.29 (VLSS), U1.30 (NC(GND)), U2.2 (GND_2), U2.25 (GND), U$3.6 (GND), U$3.9 (GND), U$3.25 (GND), USB.5 (GND)
unnamed: U1.19 (D1/SPI_SDIN/I2C_SDA), U$3.19 (GPIO10_MOSI)
unnamed: S2.1, U$3.26 (GPIO7,SPI0_CE1)
unnamed: S1.1, U$3.24 (GPIO8,SPI0_CE0)
unnamed: U1.15 (DC/I2C_SA0), U$3.16 (GPIO23)
unnamed: U1.18 (D0/SPI_SCLK/I2C_SCK), U$3.23 (GPIO11_SCLK)
unnamed: C5.1, U1.27 (VCOMH)
unnamed: U1.13 (/CS), U$3.22 (GPIO25)
unnamed: U1.14 (/RES), U$3.18 (GPIO24)
unnamed: R1.1, U1.26 (IREF)
unnamed: C2.1, U1.2 (C2P)
unnamed: C1.1, U1.4 (C1P)
unnamed: C2.2, U1.3 (C2N)
unnamed: C1.2, U1.5 (C1N)
unnamed: C9.2, U2.16 (VPP)
unnamed: U2.21 (TX), U$3.10 (GPIO15,UART0_RXD)
unnamed: U2.20 (RX), U$3.8 (GPIO14,UART0_TXD)
unnamed: R2.2, U2.9 (RST)
USB_D_N: U2.4 (D-), USB.2 (D-)
USB_D_P: U2.3 (D+), USB.3 (D+)
VCC: U1.28 (VCC)

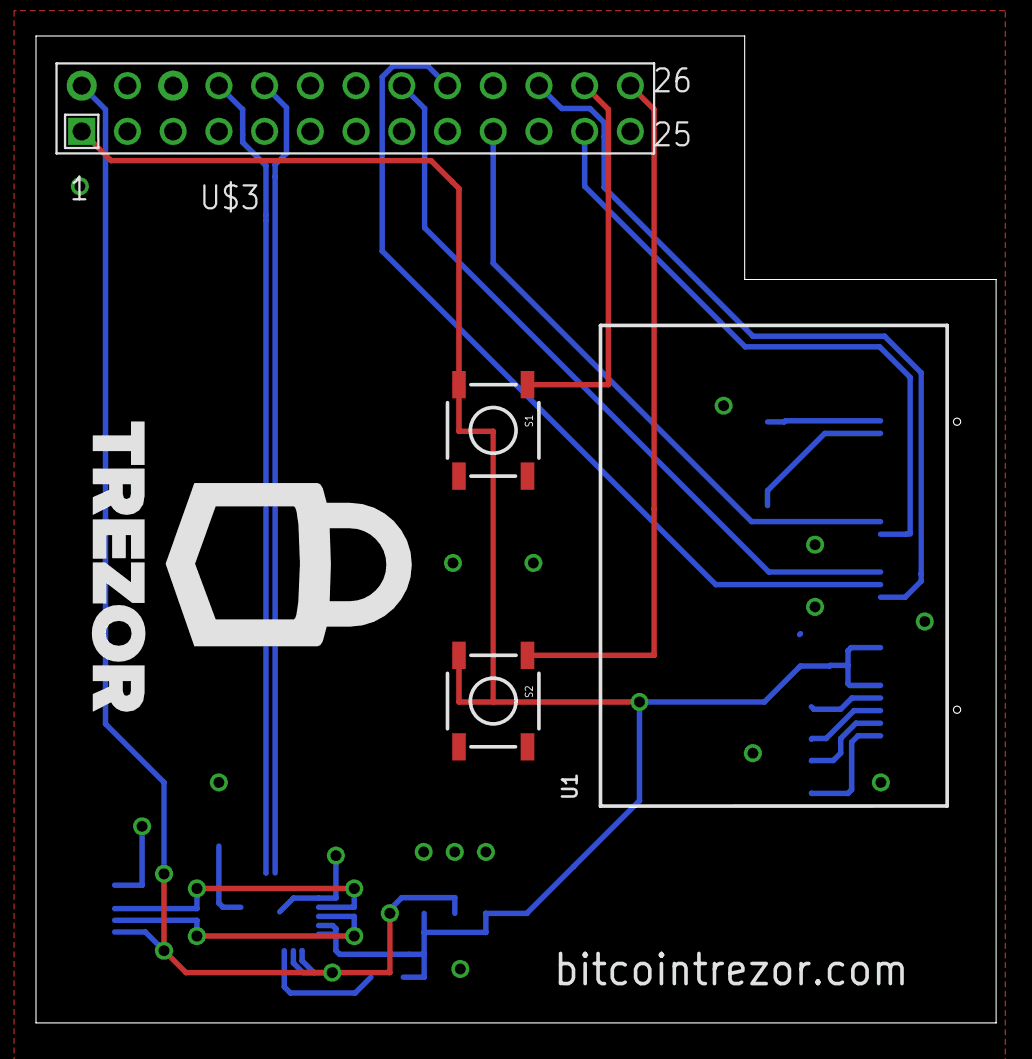
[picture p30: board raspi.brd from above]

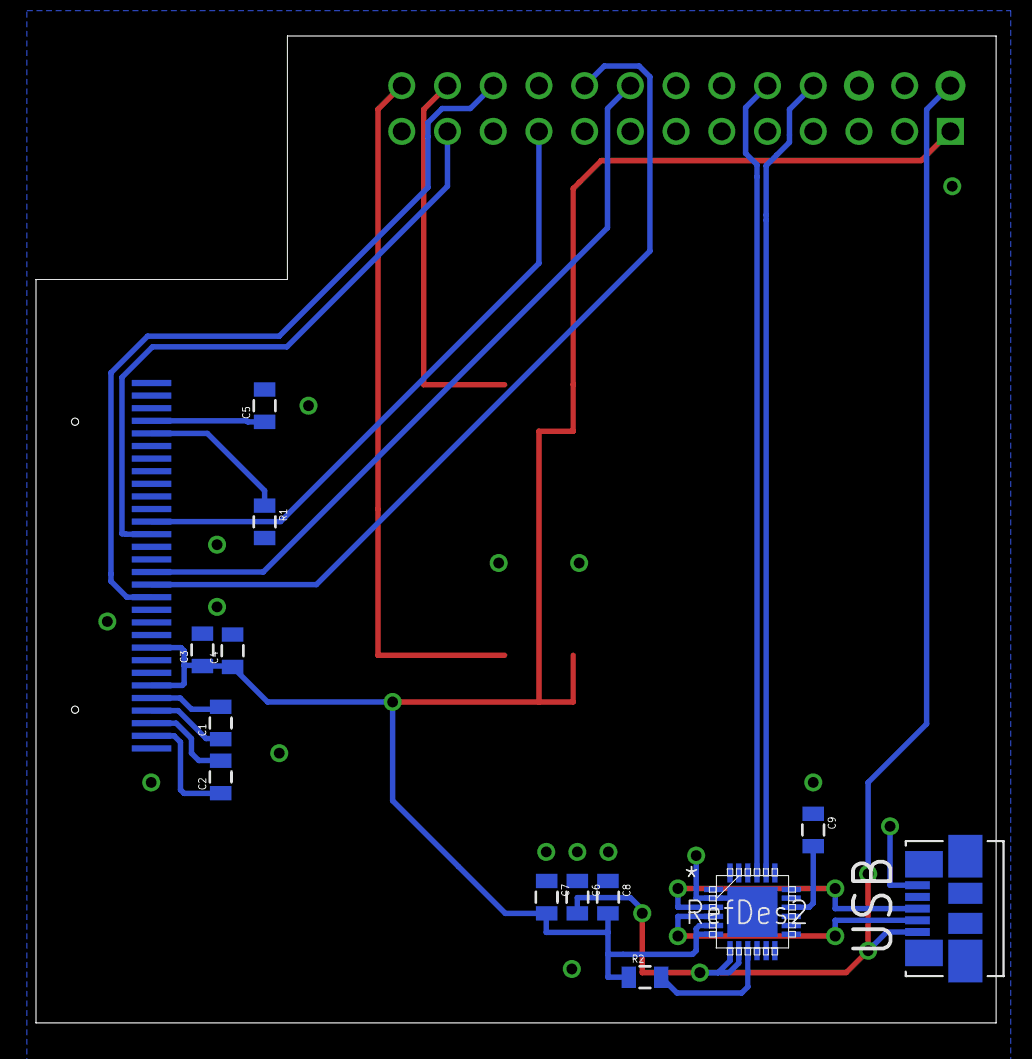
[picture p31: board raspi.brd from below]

Board: 2 copper layers, 53.3 x 54.8 mm, 17 parts (13 on the bottom side), 22 nets.

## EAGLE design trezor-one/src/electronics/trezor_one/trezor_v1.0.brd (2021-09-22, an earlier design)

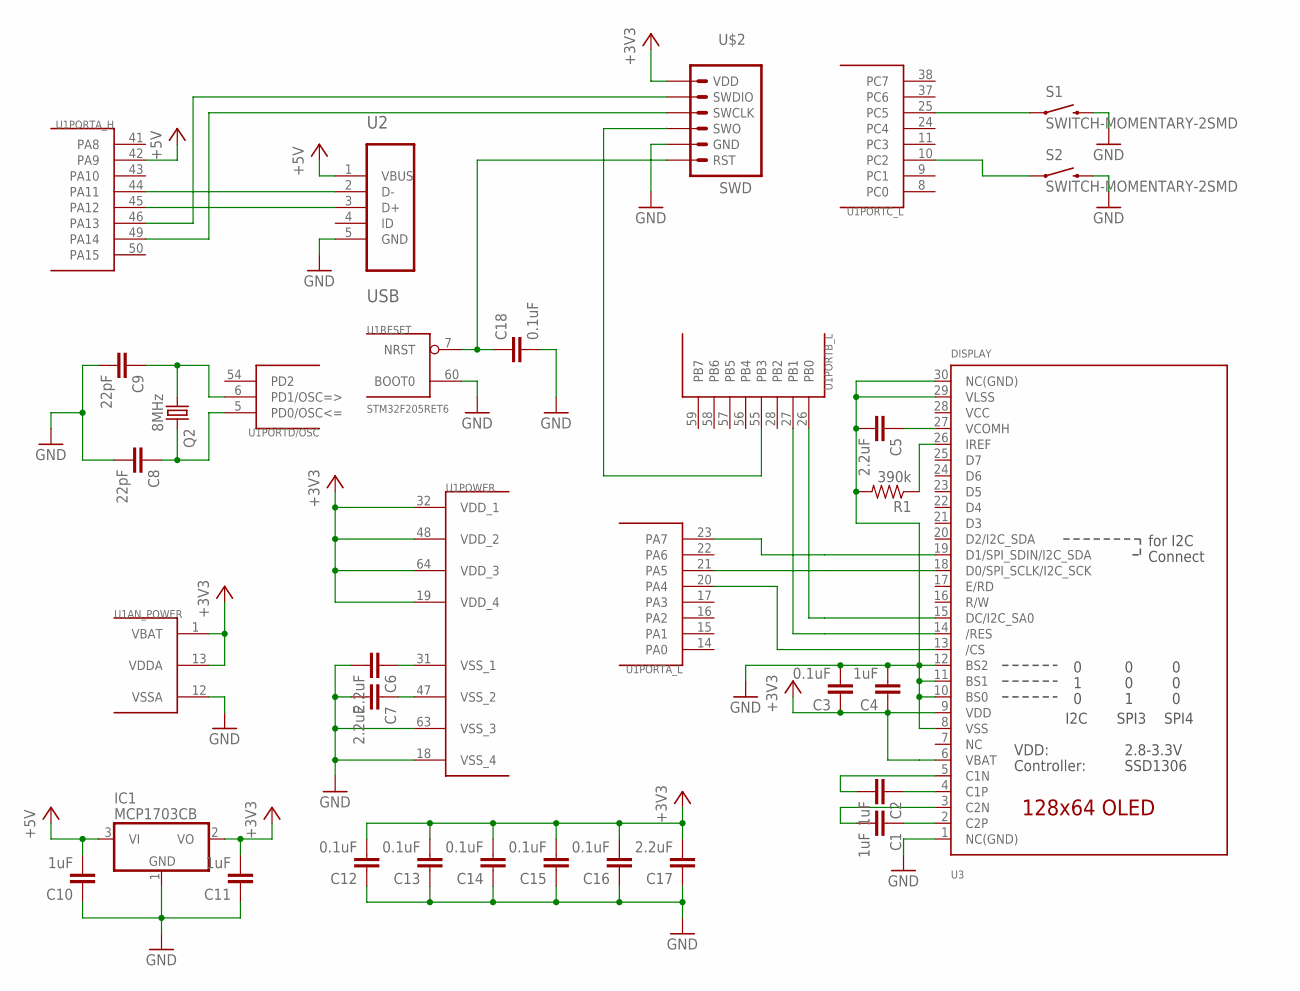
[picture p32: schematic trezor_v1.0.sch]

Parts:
C1, C2, C4, C10, C11: 1uF; 0603-CAP
C3, C12, C13, C14, C15, C16, C18: 0.1uF; 0603-CAP
C5, C6, C7, C17: 2.2uF; 0603-CAP
C8, C9: 22pF; 0603-CAP
IC1: MCP1703CB; SOT23
Q2: 8MHz; CTS406
R1: 390k; 0603-RES
S1, S2: SWITCH-MOMENTARY-2SMD; TACTILE_SWITCH_SMD
U1: STM32F205RET6; TQFP64
U2: USB; MOLEX_47346-0001
U3: DISPLAY; UG-2864HSWEG01_0.96IN_WRAPAROUND
U$2: SWD

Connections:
+3V3: C3.1, C4.1, C11.2, C12.2, C13.2, C14.2, C15.2, C16.2, C17.2, IC1.2 (VO), U1.1 (VBAT), U1.13 (VDDA), U1.19 (VDD_4), U1.32 (VDD_1), U1.48 (VDD_2), U1.64 (VDD_3), U3.6 (VBAT), U3.9 (VDD), U$2.6 (VDD)
+5V: C10.2, IC1.3 (VI), U1.42 (PA9), U2.1 (VBUS)
GND: C3.2, C4.2, C5.2, C6.2, C7.2, C8.2, C9.2, C10.1, C11.1, C12.1, C13.1, C14.1, C15.1, C16.1, C17.1, C18.2, IC1.1 (GND), R1.2, S1.3 (2), S2.3 (2), U1.12 (VSSA), U1.18 (VSS_4), U1.60 (BOOT0), U1.63 (VSS_3), U2.5 (GND), U3.1 (NC(GND)), U3.8 (VSS), U3.10 (BS0), U3.11 (BS1), U3.12 (BS2), U3.29 (VLSS), U3.30 (NC(GND)), U$2.2 (GND)
unnamed: U1.23 (PA7), U3.19 (D1/SPI_SDIN/I2C_SDA)
unnamed: C18.1, U1.7 (NRST), U$2.1 (RST)
unnamed: U1.26 (PB0), U3.15 (DC/I2C_SA0)
unnamed: C6.1, U1.31 (VSS_1)
unnamed: U1.21 (PA5), U3.18 (D0/SPI_SCLK/I2C_SCK)
unnamed: C5.1, U3.27 (VCOMH)
unnamed: U1.27 (PB1), U3.14 (/RES)
unnamed: C7.1, U1.47 (VSS_2)
unnamed: R1.1, U3.26 (IREF)
unnamed: C1.1, U3.2 (C2P)
unnamed: C2.1, U3.4 (C1P)
unnamed: C1.2, U3.3 (C2N)
unnamed: C2.2, U3.5 (C1N)
unnamed: U1.55 (PB3), U$2.3 (SWO)
unnamed: U1.46 (PA13), U$2.5 (SWDIO)
unnamed: U1.20 (PA4), U3.13 (/CS)
unnamed: U1.49 (PA14), U$2.4 (SWCLK)
unnamed: S1.1, U1.25 (PC5)
unnamed: S2.1, U1.10 (PC2)
USB_D_N: U1.44 (PA11), U2.2 (D-)
USB_D_P: U1.45 (PA12), U2.3 (D+)
VCC: U3.28 (VCC)
XTAL1: C9.1, Q2.1, U1.6 (PD1/OSC=>)
XTAL2: C8.1, Q2.3 (2), U1.5 (PD0/OSC<=)

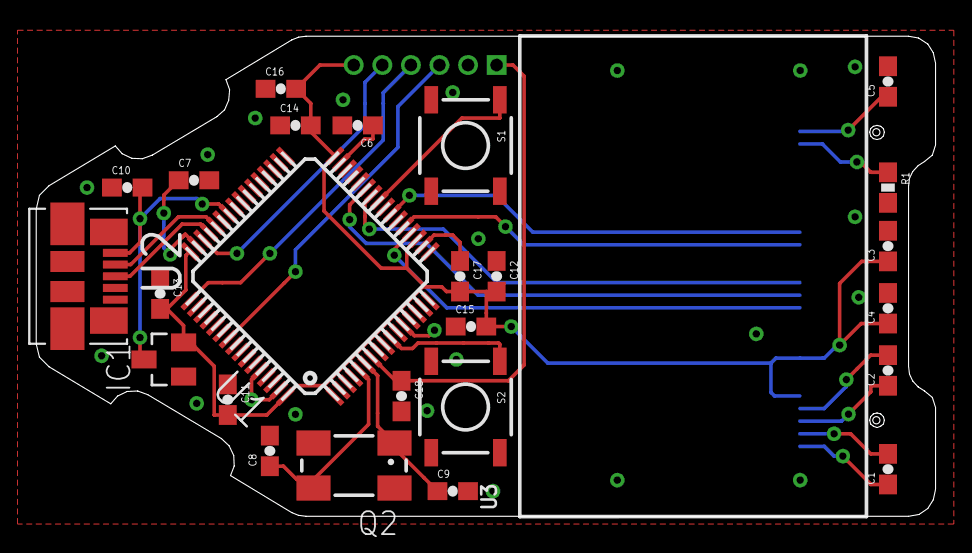
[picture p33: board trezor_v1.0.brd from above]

Board: 2 copper layers, 50.0 x 26.7 mm, 27 parts (0 on the bottom side), 26 nets.

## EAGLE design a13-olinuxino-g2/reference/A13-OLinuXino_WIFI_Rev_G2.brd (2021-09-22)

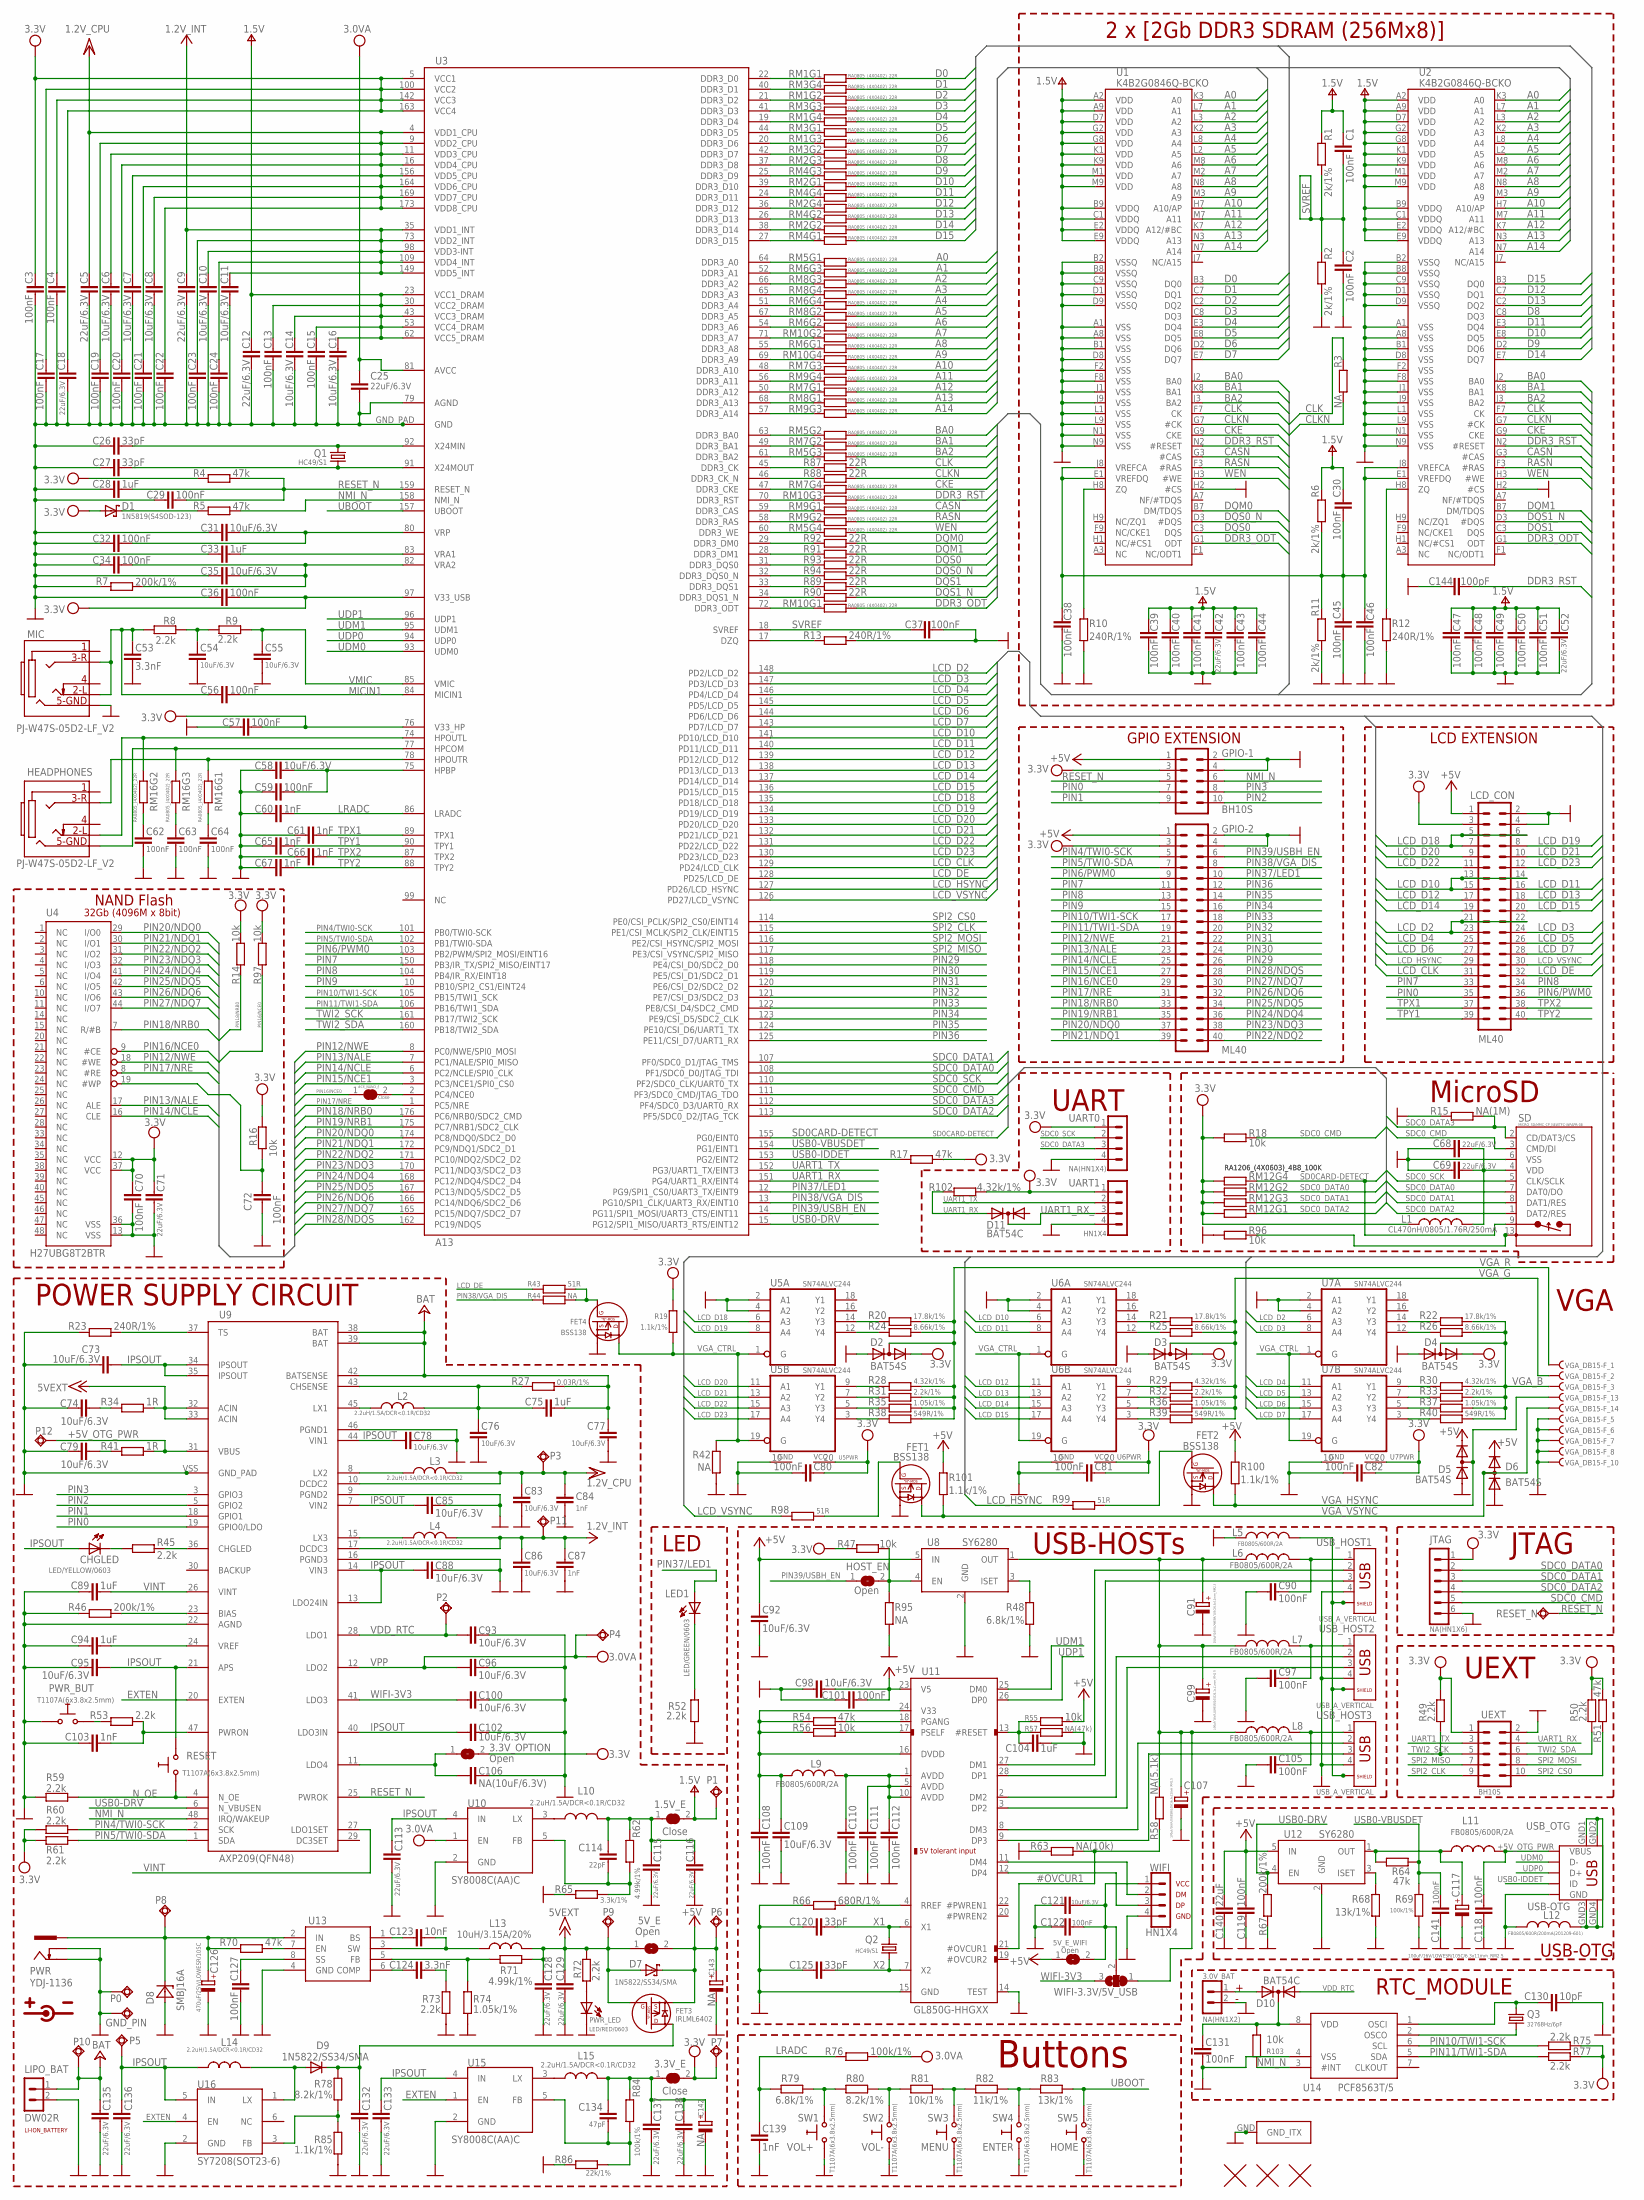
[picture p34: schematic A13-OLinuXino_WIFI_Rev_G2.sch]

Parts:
1.5V_E, 3.3V_E: Close; SJ_1_SMALLER_CLOSE
3.0V_BAT: NA(HN1X2); HN1X2
3.3V_OPTION, 5V_E, 5V_E_WIFI: Open; SJ_1_SMALLER
#CE_NAND_E: Close; SJ_1_SMALLER_CLOSE_10MILS
C1, C2, C3, C4, C13, C15, C17, C19, C20, C21, C22, C23, C24, C29, C30, C32, C34, C36, C37, C38, C39, C40, C41, C43, C44, C45, C46, C47, C48, C49, C50, C51, C56, C57, C59, C62, C63, C64, C70, C72, C80, C81, C82, C90, C97, C101, C105, C108, C110, C111, C112, C118, C119, C122, C127, C131, C141: 100nF; C0603_DWS
C5, C9, C12, C18, C25, C42, C52, C68, C69, C71, C113, C115, C116, C128, C129, C132, C133, C135, C136, C137, C138: 22uF/6.3V; C0603_DWS
C6, C7, C8, C10, C11, C14, C16, C31, C35, C54, C55, C58, C73, C74, C76, C77, C78, C79, C83, C85, C86, C88, C92, C93, C95, C96, C98, C100, C102, C109, C121: 10uF/6.3V; C0603_DWS
C26, C27, C120, C125: 33pF; C0603_DWS
C28, C33, C75, C89, C94, C104: 1uF; C0603_DWS
C53, C124: 3.3nF; C0603_DWS
C60, C61, C65, C66, C67, C84, C87, C103, C139: 1nF; C0603_DWS
C91, C99, C107, C117: 100uF/16V/LOWESR/105C/6.3x11mm_RM2.5; E2,5-6,3
C106: NA(10uF/6.3V); C0603_DWS
C114: 22pF; C0603_DWS
C123: 10nF; C0603_DWS
C126: 470uF/25V/LOWESR/105C; E5-10,5
C130: 10pF; C0603_DWS
C134: 47pF; C0603_DWS
C140: 22uF; C0603_DWS
C142, C143: NA; E3,5-8
C144: 100pF; C0603_DWS
CHGLED: LED/YELLOW/0603; LED-0603
D1: 1N5819(S4SOD-123); SOD-123
D2, D3, D4, D5, D6: BAT54S; SOT23C(BAT54S)
D7: 1N5822/SS34/SMA; MLL-41
D8: SMBJ16A; DO214AA
D9: 1N5822/SS34/SMA; MELF-MLL41
D10, D11: BAT54C; SOT23C
FET1, FET2, FET4: BSS138; SOT23
FET3: IRLML6402; SOT23
GND_PIN: TESTPAD3; TEST_PAD40/70/SQUARE
GPIO-1: BH10S; ML10-MALE
GPIO-2: ML40
HEADPHONES: PJ-W47S-05D2-LF_V2; PJ-W47S-05D2-LF_5PIN_V2
HOST_EN: Open; SJ_1_SMALLER
JTAG: NA(HN1X6); HN1X6
L1: CL470nH/0805/1.76R/250mA; L0805_5MIL_DWS
L2, L3, L4, L10, L14, L15: 2.2uH/1.5A/DCR<0.1R/CD32; CD32
L5, L6, L7, L8, L9, L11: FB0805/600R/2A; L0805_5MIL_DWS
L12: FB0805/600R/200mA(201209-601); L0805_5MIL_DWS
L13: 10uH/3.15A/20%; 8X8MM_3131
LCD_CON: ML40
LED1: LED/GREEN/0603; LED-0603
LIPO_BAT: DW02R
MIC: PJ-W47S-05D2-LF_V2; PJ-W47S-05D2-LF_5PIN_V2
P0, P1, P2, P3, P4, P5, P6, P7, P8, P9, P10, P11, P12: TESTPADTESTPAD_40-ROUND; TESTPAD_40-ROUND
PWR: YDJ-1136; PWR_JACK_UNI_MILLING
PWR_BUT: T1107A(6x3.8x2.5mm); SW-TAKT_6X3.5_SMD
PWR_LED: LED/RED/0603; LED-0603
Q1, Q2: HC49/S1; HC49/SMD2_THIN
Q3: 32768Hz/6pF; MC-306
R1, R2, R6, R11: 2k/1%; R0603_5MIL_DWS
R3, R42, R44, R95: NA; R0603_5MIL_DWS
R4, R5, R17, R51, R54, R64, R70: 47k; R0603_5MIL_DWS
R7, R46, R67: 200k/1%; R0603_5MIL_DWS
R8, R9, R45, R49, R50, R52, R53, R59, R60, R61, R72, R73, R75, R77: 2.2k; R0603_5MIL_DWS
R10, R12, R13, R23: 240R/1%; R0603_5MIL_DWS
R14, R16, R18, R47, R55, R56, R96, R97, R103: 10k; R0603_5MIL_DWS
R15: NA(1M); R0603_5MIL_DWS
R19, R85, R100, R101: 1.1k/1%; R0603_5MIL_DWS
R20, R21, R22: 17.8k/1%; R0603_5MIL_DWS
R24, R25, R26: 8.66k/1%; R0603_5MIL_DWS
R27: 0.03R/1%; R1206_5MIL_WS
R28, R29, R30, R102: 4.32k/1%; R0603_5MIL_DWS
R31, R32, R33: 2.2k/1%; R0603_5MIL_DWS
R34, R41: 1R; R0603_5MIL_DWS
R35, R36, R37, R74: 1.05k/1%; R0603_5MIL_DWS
R38, R39, R40: 549R/1%; R0603_5MIL_DWS
R43, R98, R99: 51R; R0603_5MIL_DWS
R48, R79: 6.8k/1%; R0603_5MIL_DWS
R57: NA(47k); R0603_5MIL_DWS
R58: NA(5.1k); R0603_5MIL_DWS
R62, R71: 4.99k/1%; R0603_5MIL_DWS
R63: NA(10k); R0603_5MIL_DWS
R65: 3.3k/1%; R0603_5MIL_DWS
R66: 680R/1%; R0603_5MIL_DWS
R68, R83: 13k/1%; R0603_5MIL_DWS
R69, R76, R84: 100k/1%; R0603_5MIL_DWS
R78, R80: 8.2k/1%; R0603_5MIL_DWS
R81: 10k/1%; R0603_5MIL_DWS
R82: 11k/1%; R0603_5MIL_DWS
R86: 22k/1%; R0603_5MIL_DWS
R87, R88, R89, R90, R91, R92, R93, R94: 22R; R0603_5MIL_DWS
RESET: T1107A(6x3.8x2.5mm); SW-TAKT_6X3.5_SMD
RESET_N: TESTPAD40/70; TESTPAD
RM1, RM2, RM3, RM4, RM5, RM6, RM7, RM8, RM9, RM10, RM16: RA0805_(4X0402)_22R; R_MATRIX_4_0402_25X625
RM12: RA1206_(4X0603)_4B8_100K; R_MATRIX_4
SD: MICRO_SD/MMC_CP_NEWTFC-WPAPR-08; TFC-WPAPR-08
SW1, SW2, SW3, SW4, SW5: T1107A(6x3.8x2.5mm); SW-TAKT_6X3.5_SMD
U1, U2: K4B2G0846Q-BCKO; FBGA78
U3: A13; TQFP176
U4: H27UBG8T2BTR; TSOP48
U5, U6, U7: SN74ALVC244; PW
U8, U12: SY6280; SOT23-5
U9: AXP209(QFN48); QFN48
U10, U15: SY8008C(AA)C; SOT23-5
U11: GL850G-HHGXX; SSOP28
U13: MP1482DS; SOIC8
U14: PCF8563T/5; SO-8
U16: SY7208(SOT23-6); SOT23-6
U$1, U$2, U$3: FIDUCIAL1X2; FIDUCIAL-1X2
U$4: NANO_ITX; NANO-ITX_120X120
UART0: NA(HN1X4); HN1X4
UART1: HN1X4
UEXT: BH10S; ML10-MALE
USB_HOST1, USB_HOST2, USB_HOST3: USB_A_VERTICAL; USB_A_VERTICAL_PTH
USB_OTG: USB-OTG; USB_MINI_9PIN
VGA_DB15-F: VGA15; DB15-F_22MM
WIFI: HN1X4
WIFI-3.3V/5V_USB: SJ2W6; SJ_2_SMALL_12_TIED

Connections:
#OVCUR1: R58.1, R63.2, U11.21 (#OVCUR1)
+5V: 5V_E.2, 5V_E_WIFI.1, C92.1, C98.1, C101.1, C119.1, C140.1, C143.+, D5.2 (K), D6.2 (K), D7.K (C), FET3.2 (S), GPIO-1.1, GPIO-2.1, LCD_CON.1, P6.1, R55.2, R100.2, R101.2, U8.5 (IN), U11.23 (V5), U12.5 (IN)
+5V_OTG_PWR: C118.1, L11.1, P12.1, R41.2, U9.31 (VBUS), USB_OTG.VBUS
+15V: 5V_E.1, C128.1, C129.1, D7.A, FET3.1 (G), L13.2, P9.1, R34.2, R71.2, R72.1, U9.32 (ACIN), U9.33 (ACIN)
+24V: C75.2, C77.1, C135.2, LIPO_BAT.1, P10.1, R27.2, U9.38 (BAT), U9.39 (BAT), U9.42 (BATSENSE)
A0: RM5.1.2 (2), U1.K3 (A0), U2.K3 (A0)
A1: RM6.3.2 (2), U1.L7 (A1), U2.L7 (A1)
A2: RM8.3.2 (2), U1.L3 (A2), U2.L3 (A2)
A3: RM8.4.2 (2), U1.K2 (A3), U2.K2 (A3)
A4: RM6.4.2 (2), U1.L8 (A4), U2.L8 (A4)
A5: RM8.2.2 (2), U1.L2 (A5), U2.L2 (A5)
A6: RM6.2.2 (2), U1.M8 (A6), U2.M8 (A6)
A7: RM10.2.2 (2), U1.M2 (A7), U2.M2 (A7)
A8: RM6.1.2 (2), U1.N8 (A8), U2.N8 (A8)
A9: RM10.4.2 (2), U1.M3 (A9), U2.M3 (A9)
A10: RM7.3.2 (2), U1.H7 (A10/AP), U2.H7 (A10/AP)
A11: RM9.4.2 (2), U1.M7 (A11), U2.M7 (A11)
A12: RM7.1.2 (2), U1.K7 (A12/#BC), U2.K7 (A12/#BC)
A13: RM8.1.2 (2), U1.N3 (A13), U2.N3 (A13)
A14: RM9.3.2 (2), U1.N7 (A14), U2.N7 (A14)
AVDD: C110.1, C111.1, C112.1, L9.2, U11.1 (AVDD), U11.5 (AVDD), U11.10 (AVDD)
BA0: RM5.2.2 (2), U1.J2 (BA0), U2.J2 (BA0)
BA1: RM7.2.2 (2), U1.K8 (BA1), U2.K8 (BA1)
BA2: RM5.3.2 (2), U1.J3 (BA2), U2.J3 (BA2)
CASN: RM9.1.2 (2), U1.G3 (#CAS), U2.G3 (#CAS)
CKE: RM7.4.2 (2), U1.G9 (CKE), U2.G9 (CKE)
CLK: R3.2, R87.1, U1.F7 (CK), U2.F7 (CK)
CLKN: R3.1, R88.1, U1.G7 (#CK), U2.G7 (#CK)
D0: RM1.1.2 (2), U1.B3 (DQ0)
D1: RM3.4.2 (2), U1.C7 (DQ1)
D2: RM1.2.2 (2), U1.C2 (DQ2)
D3: RM3.3.2 (2), U1.C8 (DQ3)
D4: RM1.4.2 (2), U1.E3 (DQ4)
D5: RM3.1.2 (2), U1.E8 (DQ5)
D6: RM1.3.2 (2), U1.D2 (DQ6)
D7: RM3.2.2 (2), U1.E7 (DQ7)
D8: RM2.3.2 (2), U2.C8 (DQ3)
D9: RM4.3.2 (2), U2.D2 (DQ6)
D10: RM2.1.2 (2), U2.E8 (DQ5)
D11: RM4.4.2 (2), U2.E3 (DQ4)
D12: RM2.4.2 (2), U2.C7 (DQ1)
D13: RM4.2.2 (2), U2.C2 (DQ2)
D14: RM2.2.2 (2), U2.E7 (DQ7)
D15: RM4.1.2 (2), U2.B3 (DQ0)
DDR3_A0: RM5.1.1 (1), U3.64 (DDR3_A0)
DDR3_A1: RM6.3.1 (1), U3.52 (DDR3_A1)
DDR3_A2: RM8.3.1 (1), U3.66 (DDR3_A2)
DDR3_A3: RM8.4.1 (1), U3.65 (DDR3_A3)
DDR3_A4: RM6.4.1 (1), U3.51 (DDR3_A4)
DDR3_A5: RM8.2.1 (1), U3.67 (DDR3_A5)
DDR3_A6: RM6.2.1 (1), U3.54 (DDR3_A6)
DDR3_A7: RM10.2.1 (1), U3.71 (DDR3_A7)
DDR3_A8: RM6.1.1 (1), U3.55 (DDR3_A8)
DDR3_A9: RM10.4.1 (1), U3.69 (DDR3_A9)
DDR3_A10: RM7.3.1 (1), U3.48 (DDR3_A10)
DDR3_A11: RM9.4.1 (1), U3.56 (DDR3_A11)
DDR3_A12: RM7.1.1 (1), U3.50 (DDR3_A12)
DDR3_A13: RM8.1.1 (1), U3.68 (DDR3_A13)
DDR3_A14: RM9.3.1 (1), U3.57 (DDR3_A14)
DDR3_BA0: RM5.2.1 (1), U3.63 (DDR3_BA0)
DDR3_BA1: RM7.2.1 (1), U3.49 (DDR3_BA1)
DDR3_BA2: RM5.3.1 (1), U3.61 (DDR3_BA2)
DDR3_CAS: RM9.1.1 (1), U3.59 (DDR3_CAS)
DDR3_CK: R87.2, U3.45 (DDR3_CK)
DDR3_CKE: RM7.4.1 (1), U3.47 (DDR3_CKE)
DDR3_CK_N: R88.2, U3.46 (DDR3_CK_N)
DDR3_D0: RM1.1.1 (1), U3.22 (DDR3_D0)
DDR3_D1: RM3.4.1 (1), U3.40 (DDR3_D1)
DDR3_D2: RM1.2.1 (1), U3.21 (DDR3_D2)
DDR3_D3: RM3.3.1 (1), U3.41 (DDR3_D3)
DDR3_D4: RM1.4.1 (1), U3.19 (DDR3_D4)
DDR3_D5: RM3.1.1 (1), U3.44 (DDR3_D5)
DDR3_D6: RM1.3.1 (1), U3.20 (DDR3_D6)
DDR3_D7: RM3.2.1 (1), U3.42 (DDR3_D7)
DDR3_D8: RM2.3.1 (1), U3.37 (DDR3_D8)
DDR3_D9: RM4.3.1 (1), U3.25 (DDR3_D9)
DDR3_D10: RM2.1.1 (1), U3.39 (DDR3_D10)
DDR3_D11: RM4.4.1 (1), U3.24 (DDR3_D11)
DDR3_D12: RM2.4.1 (1), U3.36 (DDR3_D12)
DDR3_D13: RM4.2.1 (1), U3.26 (DDR3_D13)
DDR3_D14: RM2.2.1 (1), U3.38 (DDR3_D14)
DDR3_D15: RM4.1.1 (1), U3.27 (DDR3_D15)
DDR3_DM0: R92.2, U3.29 (DDR3_DM0)
DDR3_DM1: R91.2, U3.28 (DDR3_DM1)
DDR3_DQS0: R93.2, U3.31 (DDR3_DQS0)
DDR3_DQS0_N: R94.2, U3.32 (DDR3_DQS0_N)
DDR3_DQS1: R89.2, U3.33 (DDR3_DQS1)
DDR3_DQS1_N: R90.2, U3.34 (DDR3_DQS1_N)
DDR3_ODT: RM10.1.2 (2), U1.G1 (ODT), U2.G1 (ODT)
DDR3_ODTT: RM10.1.1 (1), U3.72 (DDR3_ODT)
DDR3_RAS: RM9.2.1 (1), U3.58 (DDR3_RAS)
DDR3_RST: C144.1, RM10.3.2 (2), U1.N2 (#RESET), U2.N2 (#RESET)
DDR3_RSTT: RM10.3.1 (1), U3.70 (DDR3_RST)
DDR3_WE: RM5.4.1 (1), U3.60 (DDR3_WE)
DM1: U11.27 (DM1), USB_HOST1.2
DM2: U11.2 (DM2), USB_HOST2.2
DM3: U11.8 (DM3), USB_HOST3.2
DM4: U11.11 (DM4), WIFI.2
DP1: U11.28 (DP1), USB_HOST1.3
DP2: U11.3 (DP2), USB_HOST2.3
DP3: U11.9 (DP3), USB_HOST3.3
DP4: U11.12 (DP4), WIFI.3
DQM0: R92.1, U1.B7 (DM/TDQS)
DQM1: R91.1, U2.B7 (DM/TDQS)
DQS0: R93.1, U1.C3 (DQS)
DQS0_N: R94.1, U1.D3 (#DQS)
DQS1: R89.1, U2.C3 (DQS)
DQS1_N: R90.1, U2.D3 (#DQS)
DVDD: C108.1, C109.1, L9.1, R54.1, R56.1, U11.16 (DVDD), U11.24 (V33)
DZQ: R13.2, U3.17 (DZQ)
EXTEN: U9.20 (EXTEN), U15.1 (EN), U16.4 (EN)
GND: 3.0V_BAT.2, C2.1, C3.1, C4.1, C5.1, C6.1, C7.1, C8.1, C9.1, C10.1, C11.1, C12.1, C13.1, C14.1, C15.1, C16.1, C17.1, C18.1, C19.1, C20.1, C21.1, C22.1, C23.1, C24.1, C25.1, C26.1, C27.1, C28.1, C29.1, C31.1, C32.1, C33.1, C34.1, C35.1, C36.1, C37.1, C38.1, C39.1, C40.1, C41.1, C42.1, C43.1, C44.1, C45.1, C46.1, C47.1, C48.1, C49.1, C50.1, C51.1, C52.1, C53.1, C54.1, C55.1, C57.1, C58.1, C59.1, C60.1, C61.1, C62.1, C63.1, C64.1, C65.1, C66.1, C67.1, C68.1, C69.1, C70.1, C71.1, C72.1, C73.1, C74.1, C76.2, C77.2, C78.2, C79.1, C80.2, C81.2, C82.2, C83.2, C84.2, C85.2, C86.2, C87.2, C88.2, C89.1, C90.2, C91.-, C92.2, C93.2, C94.1, C95.1, C96.2, C97.2, C98.2, C99.-, C100.2, C101.2, C102.2, C103.1, C104.1, C105.2, C106.2, C107.-, C108.2, C109.2, C110.2, C111.2, C112.2, C113.2, C115.2, C116.2, C117.-, C118.2, C119.2, C120.1, C121.2, C122.2, C125.1, C126.-, C127.2, C128.2, C129.2, C130.2, C131.1, C132.2, C133.2, C135.1, C136.1, C137.2, C138.2, C139.2, C140.2, C141.2, C142.-, C143.-, C144.2, D2.1 (A), D3.1 (A), D4.1 (A), D5.1 (A), D6.1 (A), D8.A, FET1.2 (S), FET2.2 (S), FET4.2 (S), GND_PIN.P$1, GPIO-1.2, GPIO-1.4, GPIO-2.2, GPIO-2.4, JTAG.6, L5.1, L12.1, LCD_CON.2, LCD_CON.4, LIPO_BAT.2, MIC.5, P0.1, PWR.-, PWR.--, PWR_BUT.P$1 (0), PWR_LED.C, R2.1, R7.2, R10.1, R11.1, R12.1, R13.1, R15.2, R23.1, R42.1, R46.1, R48.1, R52.1, R57.2, R59.1, R63.1, R65.2, R66.1, R67.1, R68.1, R69.1, R73.2, R74.2, R85.2, R86.2, R95.1, R96.2, SD.6 (VSS), SW1.P$1 (0), SW2.P$1 (0), SW3.P$1 (0), SW4.P$1 (0), SW5.P$1 (0), U1.A1 (VSS), U1.A8 (VSS), U1.B1 (VSS), U1.B2 (VSSQ), U1.B8 (VSSQ), U1.C9 (VSSQ), U1.D1 (VSSQ), U1.D8 (VSS), U1.D9 (VSSQ), U1.F2 (VSS), U1.F8 (VSS), U1.H2 (#CS), U1.J1 (VSS), U1.J9 (VSS), U1.L1 (VSS), U1.L9 (VSS), U1.N1 (VSS), U1.N9 (VSS), U2.A1 (VSS), U2.A8 (VSS), U2.B1 (VSS), U2.B2 (VSSQ), U2.B8 (VSSQ), U2.C9 (VSSQ), U2.D1 (VSSQ), U2.D8 (VSS), U2.D9 (VSSQ), U2.F2 (VSS), U2.F8 (VSS), U2.H2 (#CS), U2.J1 (VSS), U2.J9 (VSS), U2.L1 (VSS), U2.L9 (VSS), U2.N1 (VSS), U2.N9 (VSS), U3.79 (AGND), U3.GND_PAD (GND), U3.P$2 (GND), U3.P$3 (GND), U3.P$4 (GND), U3.P$5 (GND), U3.P$6 (GND), U3.P$7 (GND), U3.P$8 (GND), U3.P$9 (GND), U3.P$10 (GND), U3.P$11 (GND), U3.P$12 (GND), U3.P$13 (GND), U3.P$14 (GND), U3.P$15 (GND), U3.P$16 (GND), U3.P$17 (GND), U3.P$18 (GND), U4.13 (VSS), U4.36 (VSS), U5.2 (A1), U5.4 (A2), U5.10 (GND), U6.2 (A1), U6.4 (A2), U6.10 (GND), U7.2 (A1), U7.4 (A2), U7.10 (GND), U8.2 (GND), U9.9 (PGND2), U9.16 (PGND3), U9.22 (AGND), U9.46 (PGND1), U9.N1 (GND_PAD), U9.N2 (GND_PAD), U9.N3 (GND_PAD), U9.N4 (GND_PAD), U9.N5 (GND_PAD), U9.N6 (GND_PAD), U9.N7 (GND_PAD), U9.N8 (GND_PAD), U9.N9 (GND_PAD), U9.N10 (GND_PAD), U9.N11 (GND_PAD), U9.N12 (GND_PAD), U9.N13 (GND_PAD), U9.N14 (GND_PAD), U9.N15 (GND_PAD), U9.N16 (GND_PAD), U9.N17 (GND_PAD), U9.VSS (GND_PAD), U10.2 (GND), U11.14 (TEST), U11.15 (GND), U12.2 (GND), U13.4 (GND), U14.4 (VSS), U15.2 (GND), U16.2 (GND), U$4.GND, U$4.P$2, U$4.P$3, U$4.P$4, UART0.4, UART1.4, UEXT.2, USB_HOST1.4, USB_HOST2.4, USB_HOST3.4, USB_OTG.GND, VGA_DB15-F.5 (F), VGA_DB15-F.6 (F), VGA_DB15-F.7 (F), VGA_DB15-F.8 (F), VGA_DB15-F.10 (F), VGA_DB15-F.GND1 (GND), VGA_DB15-F.GND2 (GND), WIFI.4
IPSOUT: C73.2, C78.1, C85.1, C88.1, C95.2, C102.1, C113.1, C133.1, C136.2, CHGLED.A, L14.1, P5.1, RESET.P$2 (1), U9.7 (VIN2), U9.13 (LDO24IN), U9.14 (VIN3), U9.21 (APS), U9.34 (IPSOUT), U9.35 (IPSOUT), U9.40 (LDO3IN), U9.44 (VIN1), U10.4 (IN), U15.4 (IN), U16.5 (IN)
LCD_CLK: LCD_CON.31, U3.129 (PD24/LCD_CLK)
LCD_D2: LCD_CON.21, LCD_CON.22, LCD_CON.23, U3.148 (PD2/LCD_D2), U7.6 (A3)
LCD_D3: LCD_CON.24, U3.147 (PD3/LCD_D3), U7.8 (A4)
LCD_D4: LCD_CON.25, U3.146 (PD4/LCD_D4), U7.11 (A1)
LCD_D5: LCD_CON.26, U3.145 (PD5/LCD_D5), U7.13 (A2)
LCD_D6: LCD_CON.27, U3.144 (PD6/LCD_D6), U7.15 (A3)
LCD_D7: LCD_CON.28, U3.143 (PD7/LCD_D7), U7.17 (A4)
LCD_D10: LCD_CON.13, LCD_CON.14, LCD_CON.15, U3.141 (PD10/LCD_D10), U6.6 (A3)
LCD_D11: LCD_CON.16, U3.140 (PD11/LCD_D11), U6.8 (A4)
LCD_D12: LCD_CON.17, U3.139 (PD12/LCD_D12), U6.11 (A1)
LCD_D13: LCD_CON.18, U3.138 (PD13/LCD_D13), U6.13 (A2)
LCD_D14: LCD_CON.19, U3.137 (PD14/LCD_D14), U6.15 (A3)
LCD_D15: LCD_CON.20, U3.136 (PD15/LCD_D15), U6.17 (A4)
LCD_D18: LCD_CON.5, LCD_CON.6, LCD_CON.7, U3.135 (PD18/LCD_D18), U5.6 (A3)
LCD_D19: LCD_CON.8, U3.134 (PD19/LCD_D19), U5.8 (A4)
LCD_D20: LCD_CON.9, U3.133 (PD20/LCD_D20), U5.11 (A1)
LCD_D21: LCD_CON.10, U3.132 (PD21/LCD_D21), U5.13 (A2)
LCD_D22: LCD_CON.11, U3.131 (PD22/LCD_D22), U5.15 (A3)
LCD_D23: LCD_CON.12, U3.130 (PD23/LCD_D23), U5.17 (A4)
LCD_DE: LCD_CON.32, R43.1, U3.128 (PD25/LCD_DE)
LCD_HSYNC: LCD_CON.29, R99.1, U3.127 (PD26/LCD_HSYNC)
LCD_VSYNC: LCD_CON.30, R98.1, U3.126 (PD27/LCD_VSYNC)
LRADC: C60.2, C139.1, R76.2, R79.1, U3.86 (LRADC)
MICIN1: C56.2, U3.84 (MICIN1)
unnamed: C58.2, C59.2, U3.75 (HPBP)
unnamed: C30.2, C38.2, C45.2, C46.2, R6.1, R11.2, U1.E1 (VREFDQ), U1.J8 (VREFCA), U2.E1 (VREFDQ), U2.J8 (VREFCA)
unnamed: R10.2, U1.H8 (ZQ)
unnamed: R45.2, U9.36 (CHGLED)
unnamed: R12.2, U2.H8 (ZQ)
unnamed: HOST_EN.2, R47.2, R95.2, U8.4 (EN)
unnamed: R96.1, SD.10 (PACK1), SD.11 (PACK2), SD.12 (PACK3), SD.13 (PACK4)
unnamed: L10.1, U10.3 (LX)
unnamed: C31.2, C32.2, U3.80 (VRP)
unnamed: D1.C, R5.2
unnamed: 5V_E_WIFI.2, C121.1, C122.1, WIFI.1, WIFI-3.3V/5V_USB.2
unnamed: #CE_NAND_E.2, U3.2 (PC4/NCE0)
unnamed: C33.2, U3.83 (VRA1)
unnamed: C34.2, C35.2, R7.1, U3.82 (VRA2)
unnamed: FET1.1 (G), R98.2
unnamed: C53.2, C56.1, MIC.2, MIC.3, R8.2
unnamed: FET2.1 (G), R99.2
unnamed: 1.5V_E.1, C114.1, C115.1, C116.1, L10.2, R62.1
unnamed: C114.2, R62.2, R65.1, U10.5 (FB)
unnamed: R37.1, U7.5 (Y3)
unnamed: FET4.1 (G), R43.2, R44.1
unnamed: C54.2, R8.1, R9.2
unnamed: C132.1, D9.1 (C), FET3.3 (D), R78.2
unnamed: C131.2, D10.3 (K), R103.2, U14.8 (VDD)
unnamed: C91.+, C99.+, C107.+, L6.1, L7.1, L8.1, R58.2, U8.1 (OUT), WIFI-3.3V/5V_USB.1
unnamed: HEADPHONES.2, RM16.2.2 (2), U3.74 (HPOUTL)
unnamed: HEADPHONES.5, RM16.3.2 (2), U3.77 (HPCOM)
unnamed: HEADPHONES.3, RM16.1.2 (2), U3.78 (HPOUTR)
unnamed: 3.0V_BAT.1, D10.2 (A2)
unnamed: C126.+, D8.C, P8.1, PWR.+, R70.1, U13.2 (IN)
unnamed: C62.2, RM16.2.1 (1)
unnamed: C63.2, RM16.3.1 (1)
unnamed: C127.1, U13.8 (SS)
unnamed: R70.2, U13.7 (EN)
unnamed: PWR_BUT.P$2 (1), R53.1
unnamed: LED1.C, R52.2
unnamed: CHGLED.C, R45.1
unnamed: C64.2, RM16.1.1 (1)
unnamed: C123.1, U13.1 (BS)
unnamed: C123.2, L13.1, U13.3 (SW)
unnamed: C124.1, U13.6 (COMP)
unnamed: C124.2, R73.1
unnamed: R71.1, R74.1, U13.5 (FB)
unnamed: L15.1, U15.3 (LX)
unnamed: 3.3V_E.1, C134.1, C137.1, C138.1, C142.+, L15.2, R84.1
unnamed: C134.2, R84.2, R86.1, U15.5 (FB)
unnamed: R79.2, R80.1, SW1.P$2 (1)
unnamed: R80.2, R81.1, SW2.P$2 (1)
unnamed: R81.2, R82.1, SW3.P$2 (1)
unnamed: R82.2, R83.1, SW4.P$2 (1)
unnamed: R68.2, U12.3 (ISET)
unnamed: C117.+, L11.2, R64.2, U12.1 (OUT)
unnamed: R48.2, U8.3 (ISET)
unnamed: R66.2, U11.4 (RREF)
unnamed: R40.1, U7.3 (Y4)
unnamed: R30.1, U7.9 (Y1)
unnamed: R54.2, U11.18 (PGANG)
unnamed: R56.2, U11.17 (PSELF)
unnamed: R33.1, U7.7 (Y2)
unnamed: R22.1, U7.14 (Y3)
unnamed: R26.1, U7.12 (Y4)
unnamed: L5.2, USB_HOST1.P$3 (5), USB_HOST1.P$4 (6), USB_HOST2.P$3 (5), USB_HOST2.P$4 (6), USB_HOST3.P$3 (5), USB_HOST3.P$4 (6)
unnamed: C90.1, L6.2, USB_HOST1.1
unnamed: C97.1, L7.2, USB_HOST2.1
unnamed: C105.1, L8.2, USB_HOST3.1
unnamed: R29.1, U6.9 (Y1)
unnamed: R32.1, U6.7 (Y2)
unnamed: C104.2, R55.1, R57.1, U11.13 (#RESET)
unnamed: R46.2, U9.23 (BIAS)
unnamed: C130.1, Q3.1, U14.1 (OSCI)
unnamed: Q3.4 (2), U14.2 (OSCO)
unnamed: D9.2 (A), L14.2, U16.1 (LX)
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

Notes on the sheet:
POWER SUPPLY CIRCUIT
LI-ION_BATTERY
2 x [2Gb DDR3 SDRAM (256Mx8)]
MicroSD
UEXT
Buttons
USB-OTG
USB-HOSTs
VCC
GND
RTC_MODULE
LED
NAND Flash
32Gb (4096M x 8bit)
GPIO EXTENSION
LCD EXTENSION
VGA
VOL+
VOL-
MENU
ENTER
HOME
JTAG
UART

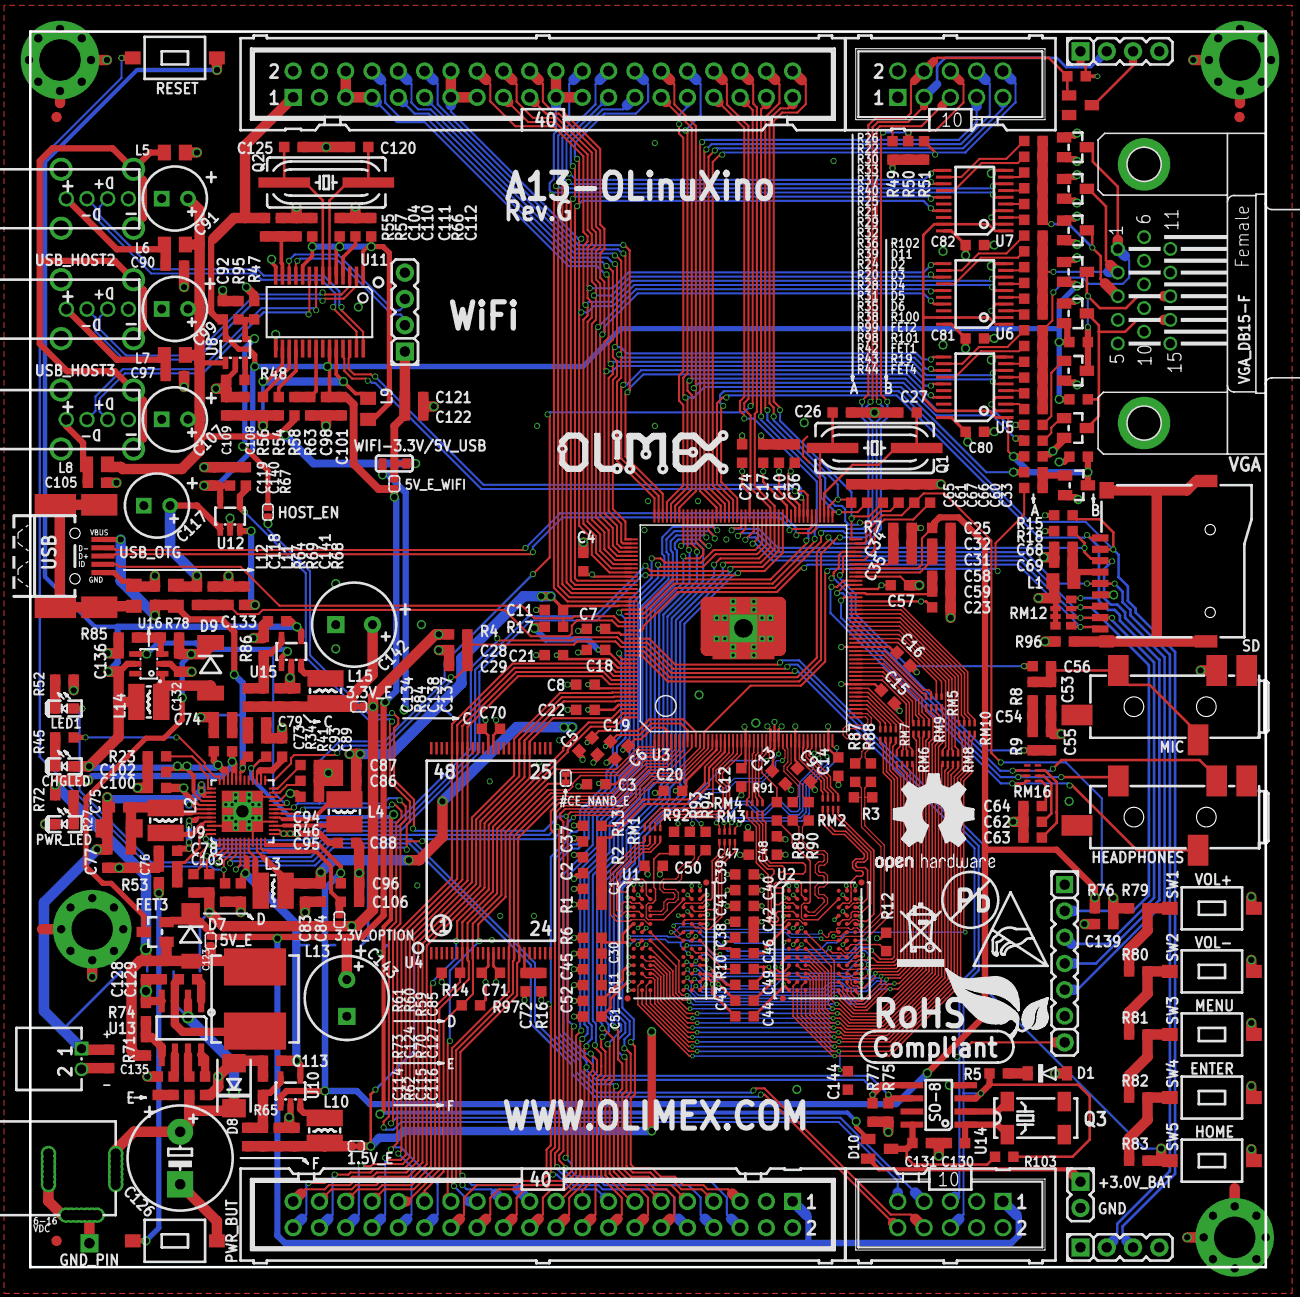
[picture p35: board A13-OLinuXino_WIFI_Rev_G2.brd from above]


Board: 4 copper layers, 119.4 x 119.4 mm, 371 parts (14 on the bottom side), 327 nets.

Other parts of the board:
U$5: LOGO-OPENHARDWARE_8X8
U$6, U$8: OLIMEX1_V
U$9: PB
U$10: ESD_SYMBOL
U$11: RECYCLE_BIN1/8
U$12: ROHS

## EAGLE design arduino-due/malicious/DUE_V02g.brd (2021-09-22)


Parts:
ADCH: FH254-108DF08500V; 1X08
ADCL: FH254-108DF08500V; 1X08
C26: 10n; C0402
C27, C29, C35, C49: 22uF; SMC_B
C28, C30, C31, C36, C37: 100nF; C0402
C38: 1uF; C0402
C39, C40: 22pF; C0402
C41, C50: 100nF; C0603-ROUND
COMMUNICATION: FH254-108DF08500V; 1X08
D1: MSS1P3L-M3/89A; MICROSMP
D2: CD1206-S01575; MINIMELF
D5: SS1P3L; DO220AAL
DEBUG: 0644_4X1VP.2,54H11,8; PH1X4-THT
F1, F2: MF-MSMF050-2 500mA; L1812
FID1, FID2, FID3, FID4: FIDUCIALMOUNT; FIDUCIA-MOUNT
IC1: LMV358IDGKR; MSOP08
IC4: NX1117CE33Z; SOT223
IC5: MPM3610; QFN-20
IC6: ATMEGA16U2-MU; MLF32
IC10: 74LVC1G125DCKR; SC70-5
ICSP1: ICSP; 2X03
JP5: 2x2M - NM; 2X02
L6: MH2029-300Y; 0805
PC1: 47uF; PANASONIC_D
PC2: 22uF; SMC_B
POWER: FH254-108DF08500V; 1X08
PWMH: FH254-110DF08500V; 1X10
PWML: FH254-108DF08500V; 1X08
Q2: BC847B; SOT23
R2, R13, R18: 10K; R0402
R3, R14, R15, R21, R23: 1K; R0402
R9: 1M; R0402
R16: 100k; R0402
R17: 75K; R0603-ROUND
R19, R20: 22R; R0402
R28: 100K_1%; R0603-ROUND
R29: 19K1_0,1%; R0603-ROUND
R30: 100k; R0603-ROUND
R31: 56k; R0603-ROUND
RN4: 100k; CAY16
RX1: Yellow; CHIPLED_0805
SPI: ICSP; 2X03
T1, T2: PMV48XP; SOT-23
TX1: Yellow; CHIPLED_0805
U$1: DNP; FRAME
UD+1, UD+2: DNP; TP-1.00MM
UD-1, UD-2: DNP; TP-1.00MM
UGND1, UGND2: DNP; TP-1.00MM
USB1: MCR-AB1-S-RA-SMT-TR; MCR-AB1-S-RA-SMT
USB2: MCR-B-S-RA-SMT-CS1TR; CON2_USB_MICRO_B_AT
UVB1, UVB2: DNP; TP-1.00MM
X2: POWER-SUPPLY; POWERSUPPLY_DC-21MM
XIO: 18x2F-H8.5; 2X18
Y4: 16Mhz-KX-7; CRYSTAL-3.2-2.5
Z1, Z2, Z3, Z4, Z5: BRNCG0603MLC-05E; CT/CN0603

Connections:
8PB4: IC6.18 ((T1/PCINT4)PB4), JP5.1
8PB5: IC6.19 ((PCINT5)PB5), JP5.3
8PB6: IC6.20 ((PCINT6)PB6), JP5.2
8PB7: IC6.21 ((PCINT7/OC0A/OC1C)PB7), JP5.4
16U2-TX: IC6.9 ((TXD1/INT3)PD3), IC10.1 (OE), IC10.2 (I)
+3V3: C29.+, C37.1, IC1.6 (-IN), IC4.2 (OUT), IC4.4 (OUT), IC10.5 (VDD), POWER.2, POWER.4; also elsewhere on the board
+5V: C30.2, C36.1, C50.1, D2.C, IC1.8 (V+), IC4.3 (IN), IC5.7 (OUT), IC5.8 (OUT), IC5.9 (OUT), IC5.20 (OUT), IC6.4 (VCC), IC6.32 (AVCC), ICSP1.2, PC2.+, POWER.5, R13.2, R14.1, R15.1, R28.2, SPI.2, T1.2 (S), T2.1 (D), XIO.1, XIO.2
AD0: ADCL.1; also elsewhere on the board
AD1: ADCL.2; also elsewhere on the board
AD2: ADCL.3; also elsewhere on the board
AD3: ADCL.4; also elsewhere on the board
AD4: ADCL.5; also elsewhere on the board
AD5: ADCL.6; also elsewhere on the board
AD6: ADCL.7; also elsewhere on the board
AD7: ADCL.8; also elsewhere on the board
AD8: ADCH.1; also elsewhere on the board
AD9: ADCH.2; also elsewhere on the board
AD10: ADCH.3; also elsewhere on the board
AD11(TXD3): ADCH.4; also elsewhere on the board
AD14(RXD3): XIO.33; also elsewhere on the board
AREF: PWMH.8; also elsewhere on the board
BD+: R20.2, UD+2.X, USB2.P3 (D+), Z4.2
BD-: R19.2, UD-2.X, USB2.P2 (D-), Z3.2
CANRX0: ADCH.7; also elsewhere on the board
CANTX0: ADCH.8; also elsewhere on the board
CANTX1/IO: XIO.34; also elsewhere on the board
CMP: C31.2, IC1.5 (+IN), Q2.3 (C), RN4.3 (1), RN4.4 (1)
D+: UD-1.X, USB1.3 (D+), Z1.1; also elsewhere on the board
D-: UD+1.X, USB1.2 (D-), Z2.1; also elsewhere on the board
DAC0(CANRX1): ADCH.5; also elsewhere on the board
DAC1: ADCH.6; also elsewhere on the board
DTR: IC6.13 ((CTS/HWB/AIN6/TO/INT7)PD7), R18.1
ERASE_CMD: IC6.23 ((OC1A/PCINT8)PC6); also elsewhere on the board
GATE_CMD: IC1.7 (OUT), T1.3 (G)
GND: C26.2, C27.-, C28.2, C29.-, C30.1, C31.1, C35.-, C36.2, C37.2, C38.2, C39.2, C40.2, C41.2, C49.-, C50.2, DEBUG.1, IC1.4 (V-), IC4.1 (GND/ADJ), IC5.3 (AGND), IC5.12 (GND), IC5.13 (GND), IC5.14 (GND), IC6.3 (GND), IC6.28 (UGND), IC6.33 (PAD), IC10.3 (VSS), ICSP1.6, PC1.-, PC2.-, POWER.6, POWER.7, PWMH.7, Q2.2 (E), R2.1, R17.1, R18.2, R29.1, R31.1, RN4.1, RN4.2 (1), RN4.5 (2), RN4.7 (2), SPI.6, UGND1.X, UGND2.X, USB1.5 (UGND), USB1.P$1 (G1), USB1.P$2 (G2), USB1.P$3 (G3), USB1.P$4 (G4), USB1.P$5 (G5), USB1.P$6 (G6), USB1.P$7 (G7), USB1.P$8 (G8), USB1.P$9 (G9), USB1.P$10 (G10), USB1.P$11 (G11), USB1.S1 (SH1), USB1.S2 (SH2), USB1.S3 (SH3), USB1.S4 (SH4), USB2.P5 (GND), USB2.P$1 (SH7), USB2.P$2 (SH8), USB2.P$3 (SH9), USB2.P$4 (SH10), USB2.P$5 (SH7), USB2.P$6 (SH8), USB2.P$7 (SH9), USB2.P$8 (SH10), USB2.S1 (SH1), USB2.S2 (SH2), USB2.S3 (SH3), USB2.S4 (SH4), USB2.S5 (SH5), USB2.S6 (SH6), X2.1, X2.3, XIO.35, XIO.36, Y4.2 (GND), Y4.4 (GND), Z1.2, Z2.2, Z3.1, Z4.1, Z5.1; also elsewhere on the board
JTAG_TCK: DEBUG.2; also elsewhere on the board
JTAG_TMS: DEBUG.3; also elsewhere on the board
MASTER-RESET: DEBUG.4, POWER.3, R23.2, SPI.5; also elsewhere on the board
MISO: SPI.1; also elsewhere on the board
MISO2: IC6.17 ((PD0/MISO/PCINT3)PB3), ICSP1.1
MOSI: SPI.4; also elsewhere on the board
MOSI2: IC6.16 ((PDI/MOSI/PCINT2)PB2), ICSP1.4
unnamed: IC6.26 ((PCINT10)PC4), R21.1
unnamed: R15.2, RX1.A
unnamed: Q2.1 (B), R3.2, RN4.8 (2)
unnamed: D1.A, D5.P$2 (A), L6.1
unnamed: R14.2, TX1.A
unnamed: R16.1, R17.2, T2.3 (G)
unnamed: IC5.1 (FB), R28.1, R29.2
unnamed: IC5.17 (EN), R30.2
unnamed: IC5.18 (AAM), R31.2
PIN22: XIO.3; also elsewhere on the board
PIN23: XIO.4; also elsewhere on the board
PIN24: XIO.5; also elsewhere on the board
PIN25: XIO.6; also elsewhere on the board
PIN26: XIO.7; also elsewhere on the board
PIN27: XIO.8; also elsewhere on the board
PIN28: XIO.9; also elsewhere on the board
PIN29: XIO.10; also elsewhere on the board
PIN30: XIO.11; also elsewhere on the board
PIN31: XIO.12; also elsewhere on the board
PIN32: XIO.13; also elsewhere on the board
PIN33: XIO.14; also elsewhere on the board
PIN34: XIO.15; also elsewhere on the board
PIN35: XIO.16; also elsewhere on the board
PIN36: XIO.17; also elsewhere on the board
PIN37: XIO.18; also elsewhere on the board
PIN38: XIO.19; also elsewhere on the board
PIN39: XIO.20; also elsewhere on the board
PIN40: XIO.21; also elsewhere on the board
PIN41: XIO.22; also elsewhere on the board
PIN42: XIO.23; also elsewhere on the board
PIN43: XIO.24; also elsewhere on the board
PIN44: XIO.25; also elsewhere on the board
PIN45: XIO.26; also elsewhere on the board
PIN46: XIO.27; also elsewhere on the board
PIN47: XIO.28; also elsewhere on the board
PIN48: XIO.29; also elsewhere on the board
PIN49: XIO.30; also elsewhere on the board
PIN50: XIO.31; also elsewhere on the board
PIN51: XIO.32; also elsewhere on the board
PWM2: PWML.3; also elsewhere on the board
PWM3: PWML.4; also elsewhere on the board
PWM5: PWML.6; also elsewhere on the board
PWM6: PWML.7; also elsewhere on the board
PWM7: PWML.8; also elsewhere on the board
PWM8: PWMH.1; also elsewhere on the board
PWM9: PWMH.2; also elsewhere on the board
PWM11: PWMH.4; also elsewhere on the board
PWM12: PWMH.5; also elsewhere on the board
PWM13: PWMH.6; also elsewhere on the board
RD+: IC6.29 (D+), R20.1
RD-: IC6.30 (D-), R19.1
RESET2: D2.A, IC6.24 (RESET(PC1/DW)), ICSP1.5, R13.1
RESET_CMD: IC6.22 ((INT4/ICP1/CLK0)PC7), R23.1
RX: IC10.4 (O), PWML.1; also elsewhere on the board
RXD0: COMMUNICATION.2; also elsewhere on the board
RXD1: COMMUNICATION.4; also elsewhere on the board
RXD2: COMMUNICATION.6; also elsewhere on the board
RXL-U2: IC6.10 ((INT5/AIN3)PD4), RX1.C
SCK2: IC6.15 ((SCLK/PCINT1)PB1), ICSP1.3
SCL0-3: COMMUNICATION.8; also elsewhere on the board
SCL1: PWMH.10; also elsewhere on the board
SDA0-3: COMMUNICATION.7; also elsewhere on the board
SDA1: PWMH.9; also elsewhere on the board
SPCK: SPI.3; also elsewhere on the board
SS0/PWM10: PWMH.3; also elsewhere on the board
SS1/PWM4: PWML.5; also elsewhere on the board
TX: IC6.8 ((RXD1/AIN1/INT2)PD2), PWML.2; also elsewhere on the board
TXD0: COMMUNICATION.1; also elsewhere on the board
TXD1: COMMUNICATION.3; also elsewhere on the board
TXD2: COMMUNICATION.5; also elsewhere on the board
TXL-U2: IC6.11 ((XCK/AIN4/PCINT12)PD5), TX1.C
UOTGID: USB1.4 (ID), Z5.2; also elsewhere on the board
UOTGVBOF: R3.1; also elsewhere on the board
USBVCC: C27.+, C35.+, F1.1, R2.2, R21.2, T1.1 (D)
USBVCCU2: C28.1, F2.1, IC6.31 (UVCC), T2.2 (S)
VIN: C41.1, C49.+, D1.K (C), D5.P$1 (K), IC5.16 (VIN), PC1.+, POWER.8, R30.1, RN4.6 (2)
VIN+: L6.2, R16.2, X2.2
VUCAP: C38.1, IC6.27 (UCAP)
XT1: C39.1, IC6.1 (XTAL1), R9.1, Y4.1 (C1)
XT2: C40.1, IC6.2 (XTAL2(PC0)), R9.2, Y4.3 (C2)
XUSB: C26.1, F1.2, USB1.1 (VUSB), UVB1.X; also elsewhere on the board
XVCC: F2.2, USB2.P1 (VBUS), UVB2.X

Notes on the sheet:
TWI pullups
USB AB
USB boot En
CONFIG 5V
Arturo Guadalupi


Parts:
BR1: NM; J0402
C1, C2, C3, C11, C33: 22uF; SMC_B
C4, C5, C6, C7, C8, C9, C10, C12, C13, C14, C15, C16, C17, C18, C19, C32, C34: 100nF; C0402
C20: 10n; C0402
C21, C22, C23, C24, C25: 22pF; C0402
CN2: PINHEAD-2x5-P1.27; PINHEAD_2X05_127
ERASE: 157SW; SMD_157SW
IC1: LMV358IDGKR; MSOP08
IC2, IC3: 74AHC1G86DBV; SOT23-5
JR1: 0R; R0402
L: Yellow; CHIPLED_0805
L1, L2, L3, L5: MH2029-300Y; 0805
ON: Green; CHIPLED_0805
R1, R8: 0R; R0402
R4: 100k; R0402
R5, R6: 39R 1%; R0402
R7: 6K8; R0603-ROUND
R99: 10K; R0402
RESET: TS42
RN1, RN2: 100k; CAY16
RN3: 1K; CAY16
RN5: 1K5; CAY16
RX: Yellow; CHIPLED_0805
T3, T4: PMV48XP; SOT-23
TX: Yellow; CHIPLED_0805
U1: ATSAM3X8EA-AU; LQFP144
U2: ATTINY102F-SSNRSOIC8_SA_SST_MCH-L; SOIC8_SA_SST_MCH-L
U$2: DNP; FRAME
Y1: 12mHz-12pF-K7; CRYSTAL-3.2-2.5
Y2: 32,768Khz_SMD; RESONATOR_EPSON_FC_145

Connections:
5-GND: RESET.5 (5-GND)
+3V3: BR1.3 (2), C1.+, C4.2, C5.2, C6.2, C7.2, C8.2, C18.2, C20.2, CN2.1, ERASE.1, IC2.5 (VCC), IC3.5 (VCC), JR1.1, L1.1, L2.1, R4.2, R99.2, RN1.5 (2), RN1.6 (2), RN2.2 (1), RN2.3 (1), RN3.5 (2), RN3.7 (2), RN3.8 (2), RN5.3 (1), RN5.4 (1), T3.2 (S), U1.11 (VDDIO1), U1.52 (VDDBU), U1.57 (VDDIN), U1.62 (VDDIO2), U1.105 (VDDIO3), U1.125 (VDDIO4), U2.1 (VCC); also elsewhere on the board
AD0: U1.78 (PA16); also elsewhere on the board
AD1: U1.79 (PA24); also elsewhere on the board
AD2: U1.80 (PA23); also elsewhere on the board
AD3: U1.81 (PA22); also elsewhere on the board
AD4: U1.82 (PA6); also elsewhere on the board
AD5: U1.83 (PA4); also elsewhere on the board
AD6: U1.84 (PA3); also elsewhere on the board
AD7: U1.85 (PA2); also elsewhere on the board
AD8: U1.88 (PB17); also elsewhere on the board
AD9: U1.89 (PB18); also elsewhere on the board
AD10: U1.90 (PB19); also elsewhere on the board
AD11(TXD3): U1.91 (PB20); also elsewhere on the board
AD14(RXD3): U1.92 (PB21); also elsewhere on the board
AREF: BR1.1; also elsewhere on the board
AVREF: C19.2, L3.2, U1.75 (ADVREF)
AVREFL: BR1.2 (C), C34.2, JR1.2, L3.1
CANRX0: U1.24 (PA1); also elsewhere on the board
CANTX0: U1.23 (PA0); also elsewhere on the board
CANTX1/IO: U1.140 (PB14); also elsewhere on the board
D+: R6.1, U1.37 (DHSDP); also elsewhere on the board
D-: R5.1, U1.38 (DHSDM); also elsewhere on the board
DAC0(CANRX1): U1.76 (PB15); also elsewhere on the board
DAC1: U1.77 (PB16); also elsewhere on the board
EEXTINT: U1.25 (PA5)
EMDC: U1.123 (PB8)
EMDIO: U1.127 (PB9)
ERASE_CMD: R99.1, T3.3 (G); also elsewhere on the board
ERASE_S: ERASE.2, T3.1 (D), U1.130 (PC0), U2.2 ((PCINT0/T0/CLKI/AIN0/ADC0/TPICLK)PA0)
ERXD0: U1.120 (PB5)
ERXD1: U1.121 (PB6)
ERX_DV: U1.119 (PB4)
ERX_ER: U1.122 (PB7)
ETXD0: U1.115 (PB2)
ETXD1: U1.118 (PB3)
ETX_CLK: U1.113 (PB0)
ETX_EN: U1.114 (PB1)
GND: C1.-, C2.-, C3.-, C4.1, C5.1, C6.1, C7.1, C8.1, C9.1, C10.1, C11.-, C12.1, C13.1, C14.1, C15.1, C16.1, C17.1, C18.1, C19.1, C21.2, C22.2, C23.2, C24.2, C25.2, C32.1, C33.-, C34.1, CN2.3, CN2.5, CN2.9, IC2.3 (GND), IC3.3 (GND), L.C, ON.C, R7.1, R8.1, RESET.1, RESET.2, RN1.1, RN1.2 (1), RN1.7 (2), RN1.8 (2), RN2.1, RN2.4 (1), RN2.5 (2), RN2.8 (2), T4.1 (D), U1.12 (GND1), U1.33 (GNDPLL), U1.44 (GNDUTMI), U1.46 (JTAGSEL), U1.54 (GNDBU), U1.58 (GND2), U1.74 (GNDANA), U1.106 (GND3), U1.126 (GND4), U2.8 (GND), Y1.2 (GND), Y1.4 (GND); also elsewhere on the board
JTAG_RESET: CN2.10, R1.1, RN1.4 (1)
JTAG_TCK: CN2.4, RN2.7 (2), U1.28 (PB28); also elsewhere on the board
JTAG_TDI: CN2.8, RN1.3 (1), U1.29 (PB29)
JTAG_TDO: CN2.6, U1.30 (PB30)
JTAG_TMS: CN2.2, RN2.6 (2), U1.31 (PB31); also elsewhere on the board
L13: IC1.1 (OUT), IC1.2 (-IN), RN3.6 (2)
MASTER-RESET: C20.1, IC2.4 (O), R1.2, RESET.3, RESET.4, U1.47 (NRSTB); also elsewhere on the board
MISO: U1.108 (PA25); also elsewhere on the board
MOSI: U1.109 (PA26); also elsewhere on the board
unnamed: L.A, RN3.3 (1)
unnamed: ON.A, RN3.4 (1)
unnamed: R8.2, U1.51 (TST)
unnamed: R4.1, U1.53 (FWUP)
unnamed: R5.2, U1.43 (DFSDM)
unnamed: R6.2, U1.42 (DFSDP)
unnamed: IC2.1 (I0), IC3.4 (O)
unnamed: RN3.1, RX.A
unnamed: RN3.2 (1), TX.A
PIN22: U1.1 (PB26); also elsewhere on the board
PIN23: U1.7 (PA14); also elsewhere on the board
PIN24: U1.8 (PA15); also elsewhere on the board
PIN25: U1.13 (PD0); also elsewhere on the board
PIN26: U1.14 (PD1); also elsewhere on the board
PIN27: U1.15 (PD2); also elsewhere on the board
PIN28: U1.16 (PD3); also elsewhere on the board
PIN29: U1.19 (PD6); also elsewhere on the board
PIN30: U1.22 (PD9); also elsewhere on the board
PIN31: U1.26 (PA7); also elsewhere on the board
PIN32: U1.32 (PD10); also elsewhere on the board
PIN33: U1.55 (PC1); also elsewhere on the board
PIN34: U1.59 (PC2); also elsewhere on the board
PIN35: U1.60 (PC3); also elsewhere on the board
PIN36: U1.116 (PC4); also elsewhere on the board
PIN37: U1.63 (PC5); also elsewhere on the board
PIN38: U1.64 (PC6); also elsewhere on the board
PIN39: U1.65 (PC7); also elsewhere on the board
PIN40: U1.66 (PC8); also elsewhere on the board
PIN41: U1.67 (PC9); also elsewhere on the board
PIN42: U1.71 (PA19); also elsewhere on the board
PIN43: U1.72 (PA20); also elsewhere on the board
PIN44: IC3.1 (I0), U1.101 (PC19); also elsewhere on the board
PIN45: IC3.2 (I1), U1.100 (PC18); also elsewhere on the board
PIN46: IC2.2 (I1), U1.99 (PC17); also elsewhere on the board
PIN47: U1.98 (PC16); also elsewhere on the board
PIN48: U1.97 (PC15); also elsewhere on the board
PIN49: U1.96 (PC14); also elsewhere on the board
PIN50: U1.95 (PC13); also elsewhere on the board
PIN51: U1.94 (PC12); also elsewhere on the board
PWM2: U1.144 (PB25); also elsewhere on the board
PWM3: U1.139 (PC28); also elsewhere on the board
PWM5: U1.136 (PC25); also elsewhere on the board
PWM6: U1.135 (PC24); also elsewhere on the board
PWM7: U1.134 (PC23); also elsewhere on the board
PWM8: U1.133 (PC22); also elsewhere on the board
PWM9: U1.132 (PC21); also elsewhere on the board
PWM11: U1.20 (PD7); also elsewhere on the board
PWM12: U1.21 (PD8); also elsewhere on the board
PWM13: IC1.3 (+IN), T4.2 (S), U1.68 (PB27); also elsewhere on the board
RX: U1.27 (PA8); also elsewhere on the board
RXD0: U1.18 (PD5); also elsewhere on the board
RXD1: U1.5 (PA12), U2.7 (PB3(ADC7/T0/RXD0/ACO/PCINT11)); also elsewhere on the board
RXD2: U1.3 (PA10); also elsewhere on the board
RXL: RX.C, U1.103 (PC30)
SCL0-3: RN5.5 (2), U1.87 (PB13); also elsewhere on the board
SCL1: U1.70 (PA18); also elsewhere on the board
SDA0-3: RN5.6 (2), U1.86 (PB12); also elsewhere on the board
SDA1: U1.9 (PA17); also elsewhere on the board
SPCK: U1.110 (PA27); also elsewhere on the board
SS0/PWM10: U1.102 (PC29), U1.111 (PA28); also elsewhere on the board
SS1/PWM4: U1.112 (PA29), U1.137 (PC26); also elsewhere on the board
SS3: U1.142 (PB23)
TX: U1.2 (PA9); also elsewhere on the board
TXD0: T4.3 (G), U1.17 (PD4); also elsewhere on the board
TXD1: U1.6 (PA13), U2.6 (PB2(ADC6/ICP0/TXD0/PCINT10)); also elsewhere on the board
TXD2: U1.4 (PA11); also elsewhere on the board
TXL: TX.C, U1.107 (PA21)
UOTGID: U1.129 (PB11); also elsewhere on the board
UOTGVBOF: U1.128 (PB10); also elsewhere on the board
VBG: C25.1, R7.2, U1.40 (VBG)
VDDANA: C3.+, C10.2, L1.2, U1.73 (VDDANA)
VDDOUT: C11.+, C12.2, C13.2, C14.2, C15.2, C16.2, C17.2, L5.1, U1.10 (VDDCORE1), U1.45 (VDDCORE2), U1.56 (VDDOUT), U1.61 (VDDCORE3), U1.104 (VDDCORE4), U1.124 (VDDCORE5)
VDDOUTMI: C2.+, C9.2, L2.2, U1.41 (VDDUTMI)
VDDPLL: C32.2, C33.+, L5.2, U1.34 (VDDPLL)
XIN: C22.1, U1.36 (XIN), Y1.1 (C1)
XIN32: C24.1, U1.48 (XIN32), Y2.P$2 (2)
XOUT: C21.1, U1.35 (XOUT), Y1.3 (C2)
XOUT32: C23.1, U1.49 (XOUT32), Y2.P$1 (1)
XUSB: U1.39 (VBUS); also elsewhere on the board

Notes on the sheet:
N.C.
N.C. - internal pullup
Arturo Guadalupi


Board: 2 copper layers, 101.6 x 53.3 mm, 145 parts (0 on the bottom side), 151 nets.

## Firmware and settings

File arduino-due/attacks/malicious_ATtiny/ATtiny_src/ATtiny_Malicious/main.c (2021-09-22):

/*
 * ATtiny102_Malicious.c
 *
 * Created: 1/7/2021 9:35:14 PM
 * Author : louiekotler
 * Some code sampled from Ardunaut
 */ 

#define F_CPU 1000000
#include <avr/io.h>
#include <util/delay.h>
#define LED_PIN     (1 << PA5)
#define BUTTON_PIN  (1 << PB1)       // Not used in this example
#define TRIGGER_PIN (1 << PA0)
// #define BAUD 4800
// #define MYUBRR F_CPU/16/BAUD        // +1, 0 or -1 to adjust the timing.

#define FSOC 1000000 // Clock Speed (8MHz/8, 8 = default divider)
#define BAUD 4800    // Anything higher = corruption. FOSC?
//#define MYUBRR (((( FSOC / 16) + ( BAUD / 2) ) / ( BAUD )) - 1)
#define MYUBRR FSOC / 16 / BAUD -1

void PORTS_Init( void ){
  PUEB |= BUTTON_PIN;               // Enable Pull-Up function in PB1.
  PORTB |= BUTTON_PIN;              // Set Pull-Up for the Button.
  DDRA |= LED_PIN;                  // Configure LED pin as Output.
  DDRA |= TRIGGER_PIN;
}


void USART_Init( unsigned int ubrr){  // Initialize USART
  UBRRH = (unsigned char)(ubrr>>8); // Set the baud rate
  UBRRL = (unsigned char)ubrr;
  UCSRB = (1<<RXEN)|(1<<TXEN);      // Enable Receiver and Transmitter
  UCSRC = (1<<USBS)|(3<<UCSZ0);     // Set Format: 8 data, 2 stop bit
}


void USART_Transmit( unsigned char data ){
  while ( !( UCSRA & (1<<UDRE)) );  // Wait for empty buffer.
  UDR = data;                       // Put data into buffer.
}

unsigned char USART_Receive( void ){
  while ( !(UCSRA & (1<<RXC)) );    // Wait for received data.
  return UDR;                       // Return received data.
}

void USART_Flush( void ){
  while ( UCSRA & (1<<RXC) ){};
}


//-----------------------------------------------------------------------------

int main( void ){
  PORTS_Init();
  USART_Init(MYUBRR);
  PORTA |= LED_PIN;                                          // Switch off the LED.
  unsigned char c[] = {'a', 'a', 'a', 'a', 'a', 'a'};        // Set buffer to useless characters
  unsigned char trigger[] = {'A', 'T', 'T', 'A', 'C', 'K'};  // Trigger string
  unsigned char data;
  
  while(1){	
	data = USART_Receive();

	if(data) {
		c[0] = c[1];
		c[1] = c[2];
		c[2] = c[3];
		c[3] = c[4];
		c[4] = c[5];
		c[5] = data;
		
		USART_Transmit(data); // For testing only
		
		if(c[0]==trigger[0] && c[1]==trigger[1] && c[2]==trigger[2] && c[3]==trigger[3] && c[4]==trigger[4] && c[5]==trigger[5]) {
			USART_Transmit('!');            // Send '!' for testing purposes to show trigger string match
			USART_Transmit( 13 );
			USART_Transmit( 10 );
			PORTA &= ~LED_PIN;              // Switch on the LED.
			PORTA |= TRIGGER_PIN;			// Trigger reset on malicious board by setting TRIGGER_PIN
			_delay_ms(2000);
			PORTA &= ~TRIGGER_PIN; 
			PORTA |= LED_PIN;               // Switch off the LED.
		}
		
	}

  }

}  // End of main.

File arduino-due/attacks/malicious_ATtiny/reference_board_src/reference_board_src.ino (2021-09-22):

//Reference Board

void setup() {
  SerialUSB.begin(9600); // Monitor Serial
  Serial2.begin(4800);   // UART being monitored by malicious chip
  delay(5000); // Startup Serial Monitor
  SerialUSB.println("Reference Board - ATtiny Attack");
  SerialUSB.println("Trigger Word: \"ATTACK\"\n\n");
}

void loop() {
   if (SerialUSB.available() > 0) {
    char input = SerialUSB.read();
    Serial2.print(input);
    SerialUSB.print(input);
    }
}

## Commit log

2020-10-16 arduino image
2020-10-16 Upload arduino due CAM
    [DUE_V02g.GBL, DUE_V02g.GBO, DUE_V02g.GBP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]
2020-11-19 Upload the benchmark of a13-olinuxino board.
    [A13-OLinuXino_WIFI_Rev_G2.GBL, A13-OLinuXino_WIFI_Rev_G2.GBO, A13-OLinuXino_WIFI_Rev_G2.GBP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]
2021-09-22 Update the schematic, layout, and test results of Arduino due
    [BOM.xlsx, DUE_V02g.brd, DUE_V02g.sch]
2021-09-22 Update the schematic and layout of 13
    [A13-OLinuXino_WIFI_Rev_G2.brd, A13-OLinuXino_WIFI_Rev_G2.sch, BOM.xlsx]
2021-09-22 trezor_one benchmark
    [ATTiny Breakout Board.kicad_pcb, ATTiny Breakout Board.sch, bottom.stl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]

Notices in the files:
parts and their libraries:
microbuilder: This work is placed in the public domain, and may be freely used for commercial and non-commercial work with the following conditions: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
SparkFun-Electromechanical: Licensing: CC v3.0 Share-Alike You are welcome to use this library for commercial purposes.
